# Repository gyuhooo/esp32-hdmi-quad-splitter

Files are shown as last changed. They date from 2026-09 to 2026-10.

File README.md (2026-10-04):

# esp32-hdmi-quad-splitter

Full HD のテスト映像を **1 台のデバイス内で生成し、HDMI 4 本に出力する**装置の設計。

> リポジトリ名は初期案(ESP32 + 分配器)に由来します。現在の方針は **FPGA によるテストパターン発生器**です。
> mp4 の再生は行わず、カラーバー・フレームカウンタ・タイムコードをロジックで生成して 4 本を独立したタイミングで出します。

## 現在の方針: FPGA 4 出力テストパターン発生器

| 項目 | 内容 |
|---|---|
| FPGA | Xilinx Artix-7 XC7A35T 以上(無償 Vivado、MMCM ×4 で 6 種のピクセルクロックを 1 ppm 以内で生成) |
| HDMI 送信 | ADI ADV7513 ×4(24bit RGB パラレル入力 → HDMI 1.4、1080p60 対応、資料公開) |
| 出力 | 1080p / 720p / 480p × 29.97p / 59.94p / 30p / 60p を出力ごとに独立して設定 |
| 画面 | 75% カラーバー、動くボックス(コマ落ち検出)、グレースケール、外枠、ラベル、6 桁フレームカウンタ、タイムコード |
| 状態 | HDL 一式と iverilog シミュレーション済み。キャリア基板は回路図・6 層レイアウト(115 × 38 mm)・ガーバーまで生成済み(DRC 未接続 0 / クリアランス違反 0)。実機は未評価 |

```
100 MHz --> [Artix-7: MMCM x4 -> timing -> pattern] --24bit RGB--> [ADV7513] --> HDMI OUT1
                                   |                              [ADV7513] --> HDMI OUT2
                                   |                              [ADV7513] --> HDMI OUT3
                                   +---------- I2C 初期化 ------->[ADV7513] --> HDMI OUT4
```

シミュレーション結果(1080p 59.94 / 480p 59.94):

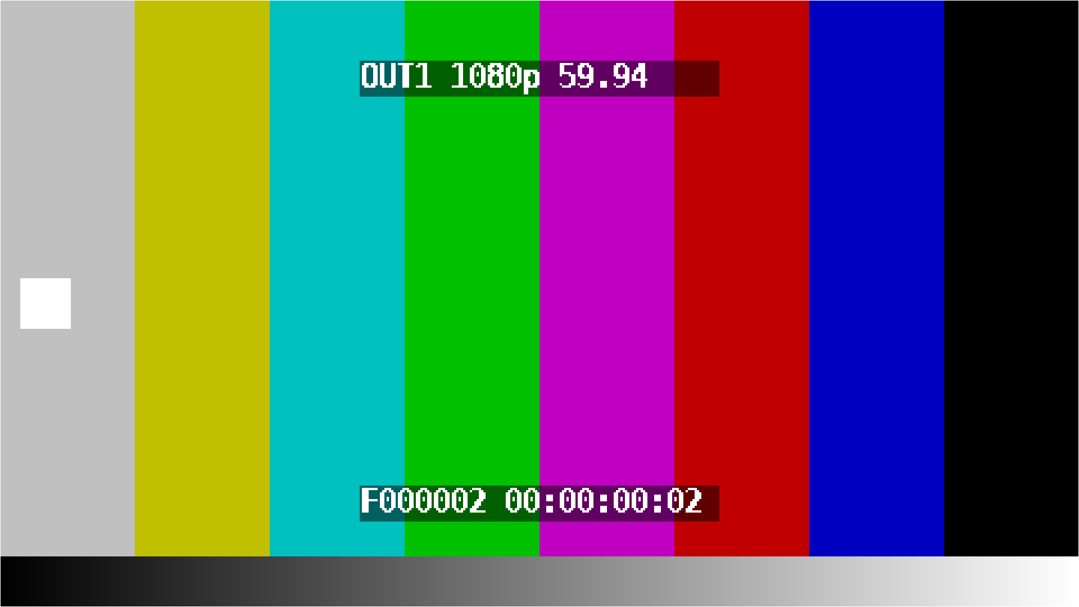
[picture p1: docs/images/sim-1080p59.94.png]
1080p


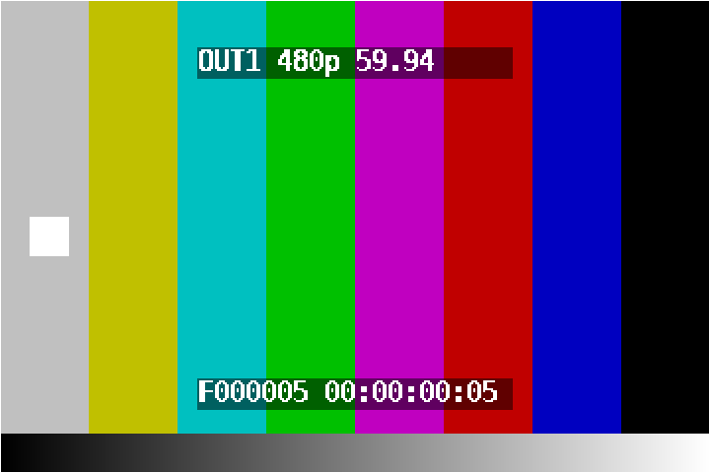
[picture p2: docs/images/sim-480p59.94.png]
480p


詳細は [docs/fpga-pattern-generator.md](docs/fpga-pattern-generator.md)。

### 試す

```
cd sim && make MODE=1 FRAME=2     # iverilog で 1080p59.94 の 1 フレームを frame.ppm に保存
```

### 回路図(hardware/)

FPGA ボードに載せるキャリア基板(ADV7513 ×4、TPD12S016 ×4、HDMI ×4、USB-C 5 V 入力、3.3 V バック、1.8 V LDO ×4)。
[hardware/README.md](hardware/README.md) に構成・検証状況・発注前チェックリストがある。

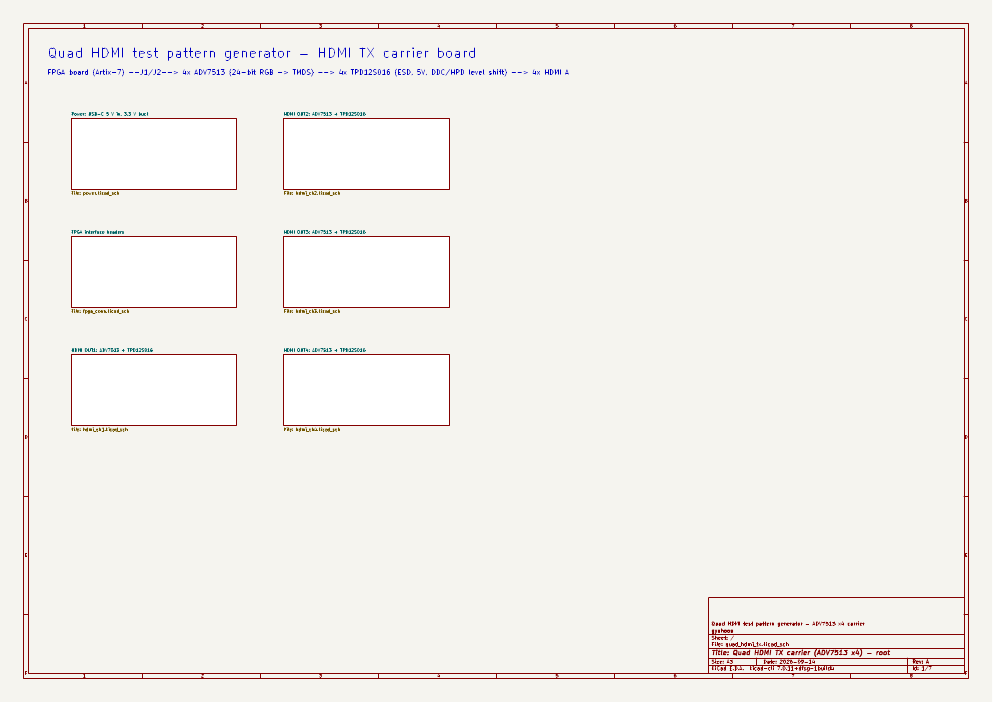
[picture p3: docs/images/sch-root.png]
root


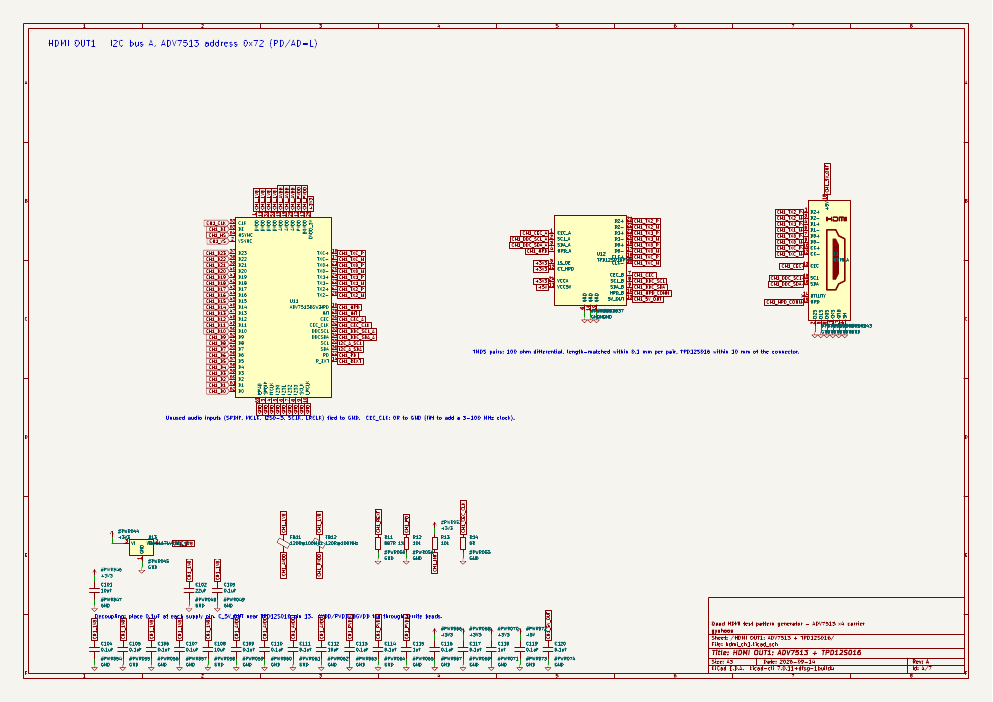
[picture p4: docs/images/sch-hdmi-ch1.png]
ch1


基板の簡易 3D モデル(`hardware/quad_hdmi_tx/3d/`、three.js ビューア付き):

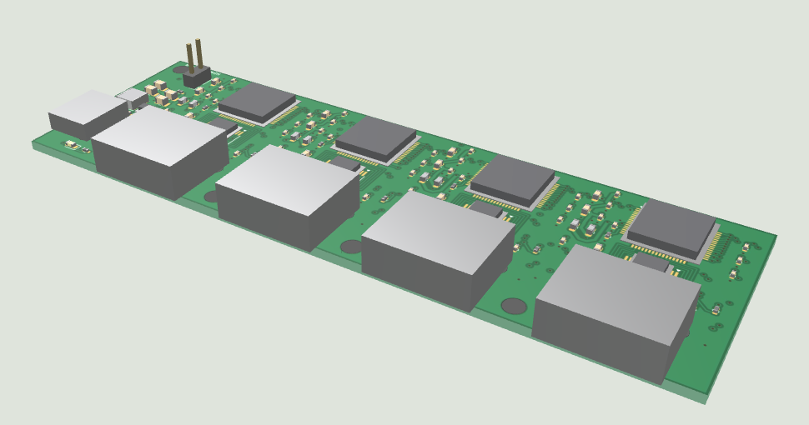
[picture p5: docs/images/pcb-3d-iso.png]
3d


基板レイアウト(6 層、115 × 38 mm、表面):

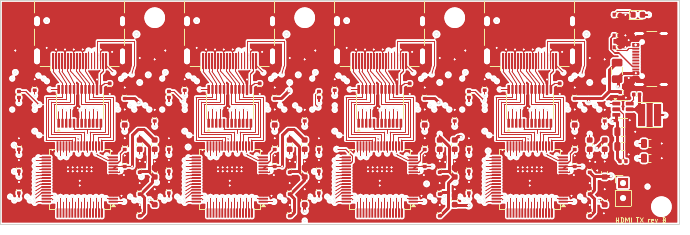
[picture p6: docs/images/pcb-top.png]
pcb


### ディレクトリ

| パス | 内容 |
|---|---|
| hardware/ | KiCad 7 回路図プロジェクト、BOM、ピン割り当て表、生成スクリプト |
| hdl/ | Verilog ソース(タイミング、パターン、文字重畳、MMCM、ADV7513 初期化、トップ) |
| sim/ | iverilog テストベンチと Makefile |
| constraints/ | Vivado 制約ファイルの例 |
| tools/make-font.py | フォント ROM 生成 |
| docs/ | 設計文書 |

## 検討経緯

| 案 | 判定 | 理由 |
|---|---|---|
| ESP32 + LT86104SX 分配器 | 不採用 | ESP32 は映像を生成できない。分配器は同一映像しか出せない |
| RK3588 で mp4 を再生し 4 CRTC へ | 代替案 | 自己完結するが、Linux と SoM が要り、出力ごとの独立タイミングは難しい。[docs/self-contained.md](docs/self-contained.md) |
| Ambarella A7 | 不採用 | HDMI 1 本、SDK は NDA |
| **FPGA パターン発生器** | **採用** | テストパターンで十分。出力ごとに独立したクロックを持て、BOM が小さい |

---

## 初期案(参考): ESP32 + LT86104SX 分配器

以下は「外部 HDMI ソース + 分配器を ESP32 で制御する」初期案の記録です。同一映像の 4 分配だけが目的ならこの構成でも成立します。

### 結論: 実現可能(ただし ESP32 は「制御担当」)

| 役割 | 担当 | 備考 |
|---|---|---|
| Full HD 映像の生成 | PC(ffmpeg) | [docs/video-source.md](docs/video-source.md) |
| Full HD 映像の再生(HDMI ソース) | **Raspberry Pi 4/5 など**(mpv) | ESP32 単体では不可 |
| 1→4 分配、HDCP リピータ、EDID 処理 | LT86104SX | 1080p60 まで、3.4 Gbps/ch |
| IC の初期化・EDID 管理・入力監視・出力 ON/OFF | ESP32(I2C マスタ) | Wi-Fi 経由でリモート制御も可 |

- LT86104SX は入力 HDMI 信号をそのまま 4 系統へ複製する IC で、映像の生成や解像度変換は行いません。
- ESP32(無印 / S3 / C3)には TMDS 出力が無く、1080p60(約 4.5 Gbps)の映像を生成する帯域も持たないため、**映像ソースにはなれません**。
- したがって「ESP32 + LT86104SX」で成立するのは **`HDMI ソース → LT86104SX → HDMI×4` を ESP32 が I2C で制御する構成** です。同じ映像を 4 台のモニタに出す用途なら、これで十分です。

### 4 本が「別々の映像」である必要がある場合

スプリッタでは実現できません。RK3588(4 画面同時出力)や 4 出力 GPU(ASUS GT710-4H など)を使ってください。

### ESP32-P4 を映像ソースにできるか

ESP32-P4 は MIPI-DSI(2 レーン)と H.264 デコーダを持つため、`ESP32-P4 → LT9611 / LT8912B (DSI→HDMI) → LT86104SX` で **1080p30 程度のテストパターン/静止画** を出すことは原理的に可能です。ただし 1080p60(RGB888 で約 3.56 Gbps)は DSI 帯域を超えるため、59.94p / 60p のテストは不可です。本リポジトリでは扱いません。

### ブロック図

```
[PC: ffmpeg で生成] --master.mp4--> [Raspberry Pi: mpv でループ再生]
                                              | HDMI 1080p
                                        [LT86104SX] --HDMI--> OUT1
                                           |   |------HDMI--> OUT2
                                           |   |------HDMI--> OUT3
                                           |   '------HDMI--> OUT4
                                           | I2C (SDA/SCL), RESET, INT
                                        [ESP32] <--Wi-Fi--> OBS-RemoteControl 等
```

### 最小構成の BOM

### 映像ソース

| 部品 | 数 | 備考 |
|---|---|---|
| Raspberry Pi 4(2 GB 以上)または Pi 5 | 1 | mpv でループ再生 |
| microSD 16 GB 以上 | 1 | Raspberry Pi OS Lite 64bit |
| micro HDMI → HDMI ケーブル | 1 | LT86104SX 入力へ |
| 5V 3A(Pi4)/ 5V 5A(Pi5)電源 | 1 | |
| 生成用 PC(ffmpeg) | 1 | 手元の PC で可 |

### スプリッタ + 制御

| 部品 | 数 | 備考 |
|---|---|---|
| LT86104SX(LQFP-128) | 1 | Lontium。データシート/レジスタ仕様は代理店経由(NDA)で入手 |
| ESP32 モジュール(ESP32-WROOM-32 / S3) | 1 | I2C マスタ、Wi-Fi |
| HDMI レセプタクル | 5 | 入力 1、出力 4 |
| 3.3V / コア用レギュレータ | 各 1 | 電圧は LT86104SX データシートで要確認 |
| ESD 保護ダイオード(TMDS 用) | 5 セット | 入出力各ポート |
| 水晶(周波数はデータシートで要確認) | 1 | |
| I2C プルアップ 4.7 kΩ | 2 | |
| 5V → HDMI +5V(各出力) | 4 | 出力側ホットプラグ用に 5V を給電 |

完成品の 1×4 スプリッタ基板(LT86104 搭載)を購入し、基板上の I2C を ESP32 に引き出す方法が最も安価で確実です。

### 使い方(映像の生成と再生)

```
# PC で生成 (ffmpeg 必須)
tools/generate-test-video.sh out/test-video 3

# Raspberry Pi に master.mp4 をコピーしてループ再生 (mpv 必須)
tools/play-loop.sh master.mp4
# セグメントごとに HDMI 出力モードを切替してテストする場合
tools/play-loop.sh --native segments
```

### 詳細

- [docs/self-contained.md](docs/self-contained.md): **現在の方針**。デバイス内で生成して 4 本出す構成
- [docs/video-source.md](docs/video-source.md): 映像の生成と再生機に必要なもの(初期案)
- [docs/feasibility.md](docs/feasibility.md): 可否判断の根拠、帯域計算
- [docs/hardware.md](docs/hardware.md): 配線、電源、注意点
- [docs/i2c-control.md](docs/i2c-control.md): ESP32 からの制御シーケンス
- [tools/](tools/): テスト映像の生成・再生スクリプト
- [firmware/](firmware/): ESP-IDF 用 I2C 制御の雛形

### 関連

- [OBS-RemoteControl](https://github.com/gyuhooo/OBS-RemoteControl)(テスト映像スクリプトの元)
- [LT86104SXE Product Brief (Lontium)](https://www.lontiumsemi.com/UploadFiles/2021-03/LT86104SXE_brief_R1.pdf)

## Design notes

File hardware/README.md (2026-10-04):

# Quad HDMI TX キャリア基板 (ADV7513 ×4)

FPGA ボードから 24bit RGB ×4 を受け、HDMI 4 本を出す基板の KiCad 7 プロジェクト。
`gen/gen_schematic.py` が回路図・BOM・ピン割り当て表を生成し、`kicad-cli` でネットリストと PDF を書き出している。

| ファイル | 内容 |
|---|---|
| quad_hdmi_tx/quad_hdmi_tx.kicad_pro / *.kicad_sch | KiCad 7 プロジェクト(ルート + 電源 + FPGA コネクタ + HDMI OUT1〜4) |
| quad_hdmi_tx/quad_hdmi_tx.pdf | 回路図 PDF(7 ページ) |
| quad_hdmi_tx/netlist.net | kicad-cli で書き出したネットリスト |
| quad_hdmi_tx/bom.csv, bom_grouped.csv | 部品表(リファレンス別 / 集計、MPN 付き) |
| quad_hdmi_tx/fpga_header_pinmap.csv | J7/J8 のピン → 信号名。FPGA ピン列を埋めて `gen/gen_xdc.py` で XDC を生成 |
| quad_hdmi_tx/quad_hdmi_tx.kicad_pcb | 基板レイアウト rev B(6 層、115 × 38 mm の細長い基板)。`gen/gen_pcb.py` が配置・プレーン・事前配線を生成し、FreeRouting で自動配線 |
| quad_hdmi_tx/drc.rpt | DRC レポート(pcbnew API) |
| quad_hdmi_tx/fab/ | ガーバー、ドリル、CPL(部品座標)、各層の PDF(`gen/export_fab.sh`) |
| quad_hdmi_tx/3d/ | STEP(基板のみ)、簡易 3D モデル(OBJ + テクスチャ)、three.js ビューア(`gen/gen_3d.py`、`gen/make_3d_textures.py`) |
| gen/ | 生成スクリプト、ネットリスト検査、配線パイプライン |

## 回路構成

```
USB-C 5V ─ F1(PTC 2A) ─ +5V ─ U5 AP63203 (3.3V 2A buck) ─ +3V3 ─┬─ U13 TLV1117LV18 ─ CH1_1V8 ─ U11 ADV7513 ─ U12 TPD12S016 ─ J1 HDMI
                                                               ├─ U23 ...                          CH2 (I2C bus A, addr 0x7A)
                                                               ├─ U33 ...                          CH3 (I2C bus B, addr 0x72)
                                                               └─ U43 ...                          CH4 (I2C bus B, addr 0x7A)
J7 / J8 (2×40 SMD、裏面): 各チャネル 20 ピンずつ。J7 = D13-23 + D1/D2/D4/D5/D10、J8 = D0/D3/D6-9/D11/D12, CLK, DE/HS/VS, HPD, INT (+ I2C_A/I2C_B, FPGA_5V)
```

### チャネル(×4)

| 要素 | 内容 | 根拠 |
|---|---|---|
| ADV7513BSWZ (LQFP-64 EP) | 24bit RGB 4:4:4 入力 ID 0、セパレートシンク。TMDS 出力 | データシート Rev.B Table 3 のピン配置 |
| R_EXT 887 Ω 1% | TMDS 基準電流 | データシート Table 3 |
| PD/AD 10 kΩ | GND → I2C 0x72(7bit 0x39)、+3V3 → 0x7A(0x3D)。同一バス 2 台をこれで分ける | |
| INT 10 kΩ プルアップ | ヘッダへ | |
| CEC_CLK 0 Ω→GND | CEC 未使用。使う場合は 0 Ω を外して 3〜100 MHz を入れる | Table 3 |
| 未使用オーディオ入力 | SPDIF, MCLK, I2S0-3, SCLK, LRCLK を GND | |
| 電源 | DVDD ×4 / AVDD ×3 / PVDD / BGVDD = 1.8 V、DVDD_3V = 3.3 V。1.8 V はチャネルごとの LDO。AVDD と PVDD/BGVDD はフェライトビーズ経由 | 1.8 V 系は最大 256 mW/個 |
| TPD12S016PWR (TSSOP-24) | TMDS 8 本の ESD、DDC/CEC のレベルシフト(A 側 3.3 V、B 側 5 V プルアップ内蔵)、HPD、5V_OUT(55 mA リミット) | データシート SLLSE96F |
| LS_OE / CT_HPD | +3V3 固定(常時有効) | |
| HDMI A(Molex 208658-1001) | シールド、GND、SH は GND。UTILITY(14) は未接続 | |

### 電源

- USB-C(GCT USB4105-GF-A、USB2.0 16P)、CC1/CC2 に 5.1 kΩ(5 V 3 A シンク宣言)。代替 5 V 入力 J6。
- F1: PTC 2 A。+5V と VBUS に PWR_FLAG。
- U5 AP63203WU(3.3 V 固定、2 A): CIN 10 µF ×2、CBST 0.1 µF、L 4.7 µH(NR4018T4R7M)、COUT 22 µF ×2、EN は 100 kΩ で VIN へ。
- 消費見積: 1.8 V 系 4 × 142 mA ≈ 0.57 A(LDO 損失 ≈ 0.85 W、SOT-223 ×4 に分散)、3.3 V 系合計 ≈ 0.7 A、5 V 入力 ≈ 0.8 A(HDMI 5V_OUT 4 × 55 mA 含む)。
- JP1(ソルダージャンパ)を閉じると J8 の 39-40 ピン(FPGA_5V)から FPGA ボードへ 5 V を供給できる。FPGA ボードが自前電源のときは開けたままにする。

### FPGA コネクタ J7 / J8

- 2×40 ピン 2.54 mm の SMD ヘッダ 2 本を **裏面** に長辺と平行に置く(Samtec TSM-140-01-L-DV 相当)。リボンケーブル(IDC)で FPGA ボードへ。
- ヘッダの列 k(ピン 2k-1 / 2k)は OUT ⌈k/10⌉ の ADV7513 の真下にある。各チャネルは J7 で 20 ピン(ADV 左辺の D13-23 と下辺の D1/D2/D4/D5/D10、GND ×4)、J8 で 20 ピン(ADV 下辺の D0/D3/D6-9/D11、CLK, DE/HS と D12、VS, HPD, INT、GND ×4、OUT1/OUT3 は I2C、OUT2 は FPGA_5V ×2)。
  データ線の並びは配線経路(内層の通路の順序)で決めたもので、ビット順ではない。FPGA 側のピン割り当ては `fpga_header_pinmap.csv` を参照。
- GND は ADV / TPD の真下の列(J7 列 4-7 下段、J8 列 4-7 上段)に置いている(表面がふさがっていて信号のビアが打てない位置)。リボンケーブル上では 4〜9 本おき。ケーブルは 15 cm 以下を推奨(148.5 MHz SDR)。
- 3.3 V LVCMOS。FPGA ボードの該当バンクは VCCO = 3.3 V であること。
- スタック高さは 30 mm 以下を推奨(148.5 MHz SDR)。FPGA 側で 22〜33 Ω の直列終端を入れられるとなお良い。
- 使用する FPGA ボードのヘッダ ⇔ FPGA ピン対応を `fpga_header_pinmap.csv` の FPGA_pin 列に記入し、`python3 gen/gen_xdc.py quad_hdmi_tx/fpga_header_pinmap.csv > constraints/board.xdc` で XDC を作る。

## 検証状況

| 項目 | 状態 |
|---|---|
| ADV7513 の全 65 ピン、TPD12S016 の全 24 ピンがデータシートどおりに割り当てられている | 済(スクリプトで番号を生成、検査で全ピンの接続を確認) |
| kicad-cli によるネットリスト書き出し | 済(147 部品、233 ネット) |
| ネット検査: データ線 2 ピン、TMDS 3 ピン、HPD/INT 3 ピン、I2C 4 ピン、GND/+3V3 に信号ピンが混ざっていない | 済(`gen/check_netlist.py`) |
| 基板レイアウト(配置・配線) | 済(rev B: 6 層 115 × 38 mm、配線 2010 本、ビア 634 個。HDMI・USB-C コネクタは基板端に合わせ済み) |
| DRC(pcbnew API、KiCad 7 の既定ルール + 本基板のルール) | 未接続 0、クリアランス / 穴 / 外形 / コートヤード違反 0(残りは `lib_footprint_issues` 147 件 = 生成したフットプリントがライブラリと一致しないという情報のみ) |
| TMDS 8 本 × 4 ch | ビアなし、ペア内長差 0.47 mm 以下(スクリプトで固定配線) |
| ガーバー / ドリル / CPL 出力 | 済(`quad_hdmi_tx/fab/`) |
| KiCad GUI での ERC / DRC 再確認 | **未**(GUI で開いて再実行を推奨) |
| 実機評価 | **未** |

### レイアウトの結果

| 層 | 画像 |
|---|---|
| 表面 (F.Cu) | top |
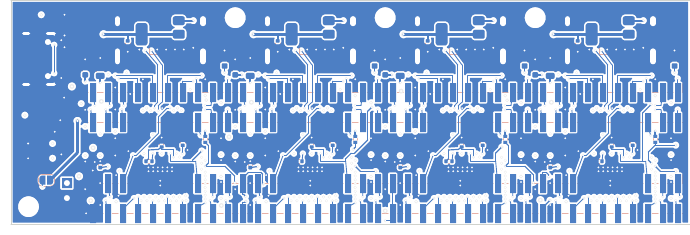
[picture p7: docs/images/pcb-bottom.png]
bottom
| 裏面 (B.Cu、ミラー表示) |  |
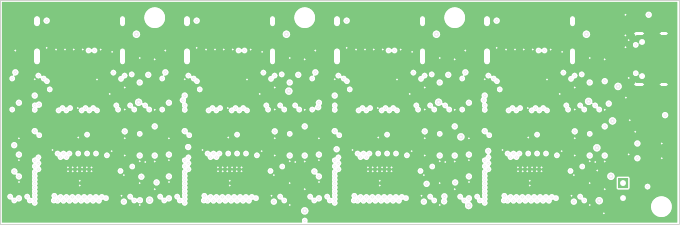
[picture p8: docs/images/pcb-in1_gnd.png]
gnd
| 内層 1 (GND) |  |
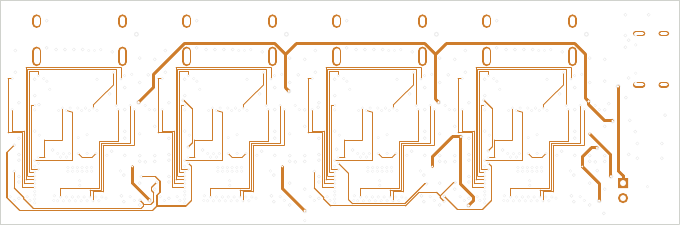
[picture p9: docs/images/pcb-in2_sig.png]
sig1
| 内層 2 (SIG1) |  |
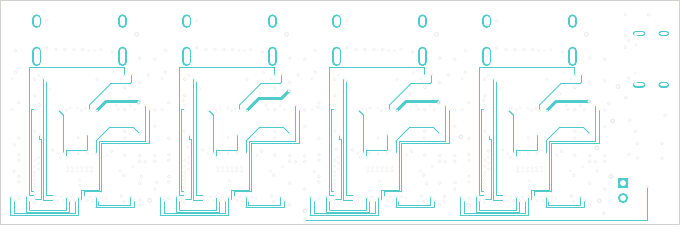
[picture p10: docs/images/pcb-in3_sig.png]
sig2
| 内層 3 (SIG2) |  |
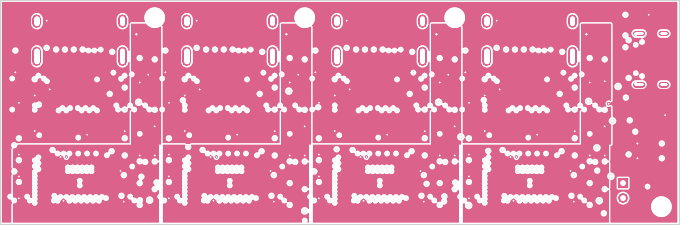
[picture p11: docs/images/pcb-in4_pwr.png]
pwr
| 内層 4 (+3V3 / CHn_1V8) |  |

TMDS の事前配線(OUT1 周辺、配線前の状態):

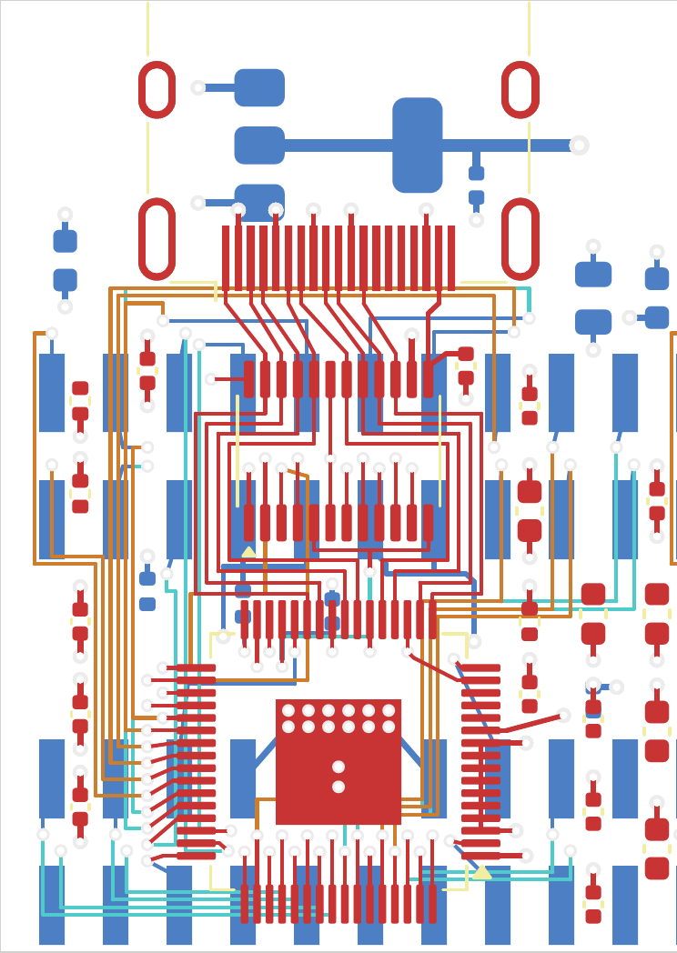
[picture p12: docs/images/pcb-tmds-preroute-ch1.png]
tmds


自動配線(FreeRouting 1.9)後の主なネット長:

```
RGB バス / 同期 (112 本): 最長 51.3 mm (D16、ヘッダ上の横レーン経由)、平均 21.4 mm、最短 4.2 mm。すべて gen_pcb.py の固定配線 (ビア 1〜2 個)
I2C_A_SCL 70 mm (OUT1/OUT2 の ADV とプルアップ、J8 経由)、I2C_B_SCL 56 mm
HPD 20 mm、INT 25 mm、DDC_SCL / CEC 15 mm (TPD -> HDMI)、FPGA_5V 72 mm (J8 ピン 39/40 -> JP1)
+5V 197 mm (ビア 9)、+3V3 132 mm (ビア 41、内層 4 のプレーンが主)、GND 326 mm (ビア 203、内層 1 のプレーンが主)
TMDS: ペア内長差 0.05〜0.47 mm、ビアなし
```

### 3D モデル

3d

| 表 | 裏 |
|---|---|
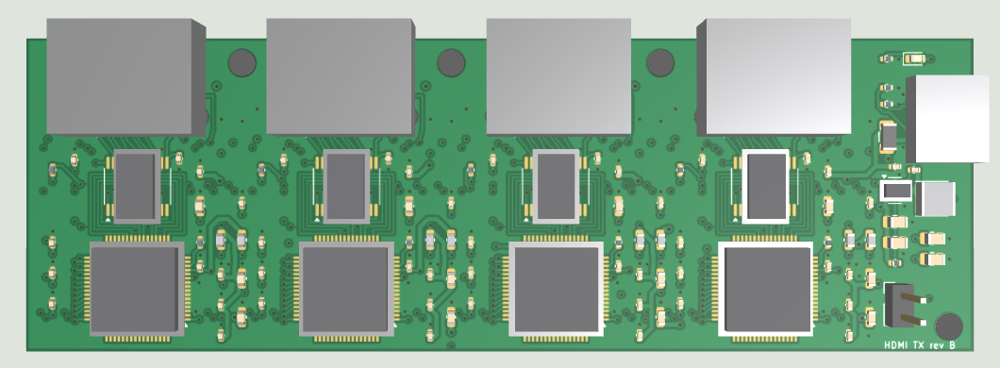
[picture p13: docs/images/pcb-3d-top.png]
3d top
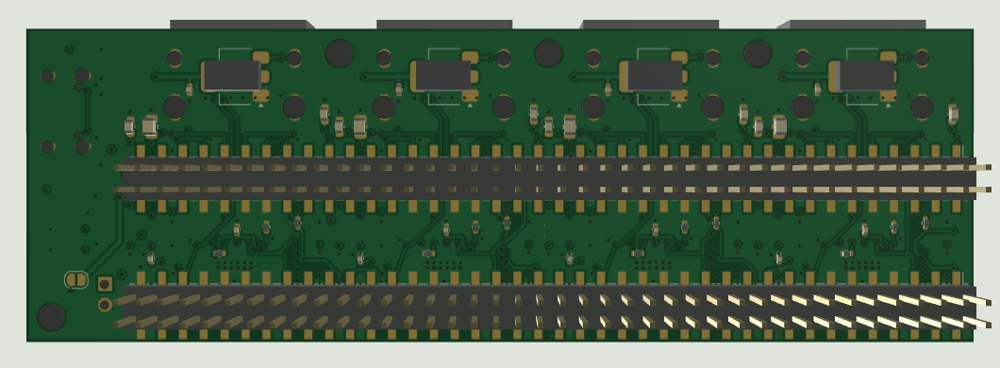
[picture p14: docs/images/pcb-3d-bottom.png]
3d bottom
|  |  |

`quad_hdmi_tx/3d/` に 3 種類ある(`gen/gen_3d.py` と `gen/make_3d_textures.py` で生成):

| ファイル | 内容 |
|---|---|
| `quad_hdmi_tx.step` | kicad-cli の STEP 出力。この環境には KiCad の 3D モデルライブラリが無いため **基板のみ**(部品なし)。筐体設計の基準に使える |
| `quad_hdmi_tx_simplified.obj` / `.mtl` / `tex_top.png` / `tex_bot.png` | 簡易モデル(Wavefront OBJ、mm、Y 上)。基板は表裏にレジスト・金パッド・シルクのテクスチャ、部品はパッケージ種別の寸法表による直方体(IC・受動部品・コネクタ・ヘッダのピン) |
| `viewer.html` | 上の簡易モデルを three.js で回転表示する 1 ファイルのビューア(ブラウザで開く) |

部品の外形は寸法表の近似なので、正確な 3D モデルが要るときは KiCad の 3D ライブラリを入れて `kicad-cli pcb export step` を再実行する。

## 発注前チェックリスト

1. **ADV7513 の推奨回路**: ハードウェアユーザーガイド(ADI)で、PVDD/BGVDD のフィルタ構成と HPD/DDC の扱いが本回路(フェライトビーズ + 0.1 µF、TPD12S016 経由)と矛盾しないか確認する。
2. **フットプリント**: ADV7513 の露出パッドは 5.3 mm 角。`LQFP-64-1EP_10x10mm_P0.5mm_EP5x5mm` を使い、EP のサーマルビア(0.5/0.3 mm ×14)は裏面ヘッダのパッドを避けて `gen_pcb.py` が打っている。
3. **HDMI コネクタ**: Molex 208658-1001 の KiCad 標準フットプリント。別品番なら 1〜19 + シェルの配列を照合する。
4. **USB-C**: GCT USB4105-GF-A の標準フットプリント。NPTH と自身のパッドの間隔が 0.194 mm なので、穴クリアランスの規則を 0.18 mm にしている。
5. **LDO**: TLV1117LV18DCYR(セラミック出力対応、1 A)。AMS1117-1.8 はピン互換だがタンタル出力推奨。
6. **I2C アドレス**: 同一バスに 2 台(0x72 と 0x7A)。HDL の `top.v` はバス 0 = OUT1/OUT2、バス 1 = OUT3/OUT4 でこの割り当てを前提にしている。
7. **KiCad GUI で ERC と DRC を再実行する**: 本リポジトリの検査は pcbnew API のレポート。DRC の残り 143 件は「フットプリントがライブラリと一致しない」情報(ライブラリ名なしで読み込んだため)で、製造には影響しない。
8. **インピーダンス**: TMDS は 0.15 mm 幅 / 0.15 mm 間隔で固定配線している。製造業者の 6 層スタックアップ(例: JLC06161H-3313、F.Cu〜In1 が 0.1 mm 程度)の計算値に合わせて幅・間隔を調整し、必要なら `gen/gen_pcb.py` のネットクラスと事前配線幅を変えて再生成する。
9. **自動配線部の目視確認**: RGB バス(148.5 MHz)30 本は `gen_pcb.py` の固定配線(内層 SIG1/SIG2、各線 40 mm 以下)。電源・I2C・CEC・HPD 系は FreeRouting の結果なので、ADV 右辺付近の AVDD/PVDD と I2C の引き回しをレビューし、必要なら手で整える。
10. **シルク**: 参照記号は F.Fab に置いている(シルクには出ない)。実装は `fab/cpl.csv` の座標で行う。
11. **コネクタの基板端合わせ**: HDMI(Molex 208658)と USB-C(GCT USB4105)のフットプリントには "PCB Edge" の基準線がある。
    生成スクリプトはこの線が基板外形(HDMI: y=0、USB-C: x=115)に一致するよう配置している(HDMI は本体が 1.5 mm、USB-C は 0.5 mm 外形からはみ出す)。
    ケースに入れる場合はこのはみ出し量を前提に開口を設計する。
12. **裏面のヘッダと IDC ソケット**: J7/J8 の中心間隔は 15.4 mm、J8 は下辺から 4.4 mm。IDC ソケット(幅 8.9 mm)は J8 側が基板端とほぼ面一になる。基板の下に高さ 10 mm 以上の空間が必要。
13. **両面実装**: LDO ×4、そのコンデンサ、ヘッダ 2 本、JP1 が裏面。実装業者には両面(F+B)の CPL を渡す。裏面の SMD ヘッダはリフロー可能品(TSM-140-01-L-DV 等)を選ぶ。
14. **取付穴**: M3 ×4(HDMI の間に 3 個、右下に 1 個)。HDMI の間の穴はプラグのオーバーモールド(幅 ~21 mm)と干渉しない位置だが、ナットは基板の裏側に置くこと。

## 基板レイアウト

### 配置(rev B: 115 × 38 mm、縦横比 0.33)

```
 y=0  ┌───────────────────────────────────────────────────────────────────────┐
      │ [J1 HDMI] H1 [J2 HDMI]  H2 [J3 HDMI]  H4 [J4 HDMI]   R5 R6 F1  [J5]   │  上辺: HDMI ×4 (25.4 mm ピッチ、開口部は上)。裏面の真裏に LDO
      │  U12 TPD     U22 TPD       U32 TPD       U42 TPD      C54     USB-C   │  TPD12S016 (rot 90)。両脇に +3V3 / 5V 系のコンデンサ
      │  U11 ADV     U21 ADV       U31 ADV       U41 ADV      U5  C51  L1     │  ADV7513 (rot 180)。左右の列に 1V8 / AVDD / PVDD 系
      │                                                      C52 C53  C55 C56 │  電源部 (右端)
 y=38 └───────────────────────────────────────────────────────────────────────┘
        x=0                              裏面: J7 (y=18.2) と J8 (y=33.6) が x=1.6..101.6 に横たわる        x=115

 裏面 (透視): [LDO U13][LDO U23][LDO U33][LDO U43] ← HDMI のシェルタブの穴の間
             ═══════════ J7 2×40 (列 1-10 = OUT1, 11-20 = OUT2, 21-30 = OUT3, 31-40 = OUT4) ═══════════
             ═══════════ J8 2×40 (同じ列割り) ═══════════════════════════════════════════════════  JP1
```

- HDMI 4 個の横幅(4 × 25.4 mm)に電源部を足した 115 mm を横幅とし、縦幅は 38 mm(横の 1/3 以下)。
- 各チャネルは幅 25.4 mm = ヘッダ 10 列。ヘッダの列は ADV の真下なので、RGB バスの配線は 1 本あたり 15 mm 以下。
- TMDS の並び順が ADV7513(rot 180)→ TPD12S016(rot 90)→ HDMI(rot 90)で **交差なし**に揃うよう向きを決めている
  (ADV 上辺: TX2+ TX2- TX1+ TX1- TX0+ TX0- TXC+ TXC-、TPD 上辺: D2+ D2- D1+ D1- D0+ D0- CLK+ CLK-、コネクタ: 1 3 4 6 7 9 10 12)。
- 裏面ヘッダのパッド(1.0 mm 幅、2.54 mm ピッチ)の隙間は 1.54 mm しかないので、貫通ビアはパッド列の隙間の中心(x = cx ± 2.54 m)か、
  2 列の間 / J7-J8 の間の帯に置く。2 端子部品はすべて縦置きでこの x に載せ、外向きのビアが隙間に来るようにしている。
  TPD の A 側ピンのビア(y = 18.3 / 18.7)は J7 の 2 列の隙間(y 17.25〜19.15)に、ADV 上辺の囲われたピンのビア(y = 26.0 / 26.6)は J7-J8 の間の帯に入る。
- ADV のデータピンはルータ任せでは半分が配線できない(裏面ヘッダのパッドが B.Cu を塞ぐ)ので、`gen_pcb.py` が 30 本の RGB/同期/制御線をすべて事前配線する(残りの電源・I2C・CEC などが FreeRouting):
  - 下辺 16 ピンのエスケープビアは本体下(EP とパッド内端の間 = J8 の 2 列の隙間に当たる y)に 2 段。真下の J8 下段 4 本(D11/D8/D3/HS)は裏面で直落とし、
    D6/D7/CLK/D9 と DE/D0 は SIG2 の横レーン(y = 34.8〜36.5)で J8 列 1-2 / 列 9 の隙間ビアへ、D1/D2/D4/D5/D10 は ADV 右脇の通路(x = cx+3.35/3.65/3.95)を上って J7 列 8-10 へ。
  - 左辺 16 ピンは左へ(上 5 本は x=cx-7.0/-7.62 に交互、中 8 本は隙間の列 x=cx-7.62 に 0.65 ピッチで斜めに、D14/D13 は本体下、D12 は隙間の列の一番下)。
    D16-D23 と DDC は左の内層通路(x = cx-8.19〜-9.69、SIG1/SIG2 各 6 レーン)を上り、J7 列 1-2 の隙間ビア、またはヘッダの上(y = 11.5〜12.1)の横レーン経由で列 5-8 上段へ。
    D13/D14/D15 は ADV 脇の帯(x = cx-6.5〜-5.5)を SIG2 で上って列 3-4 へ。J8 列 4-7 上段(GND)は EP のサーマルビアに裏面で直結。
  - レーンの割り当ては「右の通路ほど低い横レーン」「横レーンから下に曲がる先は左ほど低いレーン」の規則で決め、事前配線どうしが交差しないようにしている。
  - そのほか、ルータが落としやすい DDC_SCL(TPD → HDMI、SIG2 で右上へ抜けて表面でコネクタの上を回る)と FPGA_5V(J8 ピン 39/40 → JP1、SIG2 で基板下端を右へ)も固定配線。
- LDO(SOT-223)は HDMI コネクタの真裏、シェルタブの穴の間。出力は裏面の太い配線で内層 4 の 1V8 の島の「首」へ入る。
- 電源部は右端(USB-C の開口部は右)。

### 層構成(6 層、1.6 mm)

| 層 | 用途 |
|---|---|
| F.Cu | 信号(TMDS 事前配線、短い引き出し)、部品 |
| In1.Cu (GND) | GND プレーン(全面) |
| In2.Cu (SIG1) / In3.Cu (SIG2) | 信号(RGB バス、制御線、+5V) |
| In4.Cu (PWR) | +3V3 プレーン。各 ADV の周囲は CHn_1V8 の島(優先度 1)。島は LDO へ向けて首を伸ばしている |
| B.Cu | FPGA ヘッダ、LDO、信号、配線後に GND ベタ |

4 層では裏面ヘッダのパッド列が B.Cu を塞ぐため、RGB バスの配線が成立しない。6 層にして内層 2 層を信号に使う。

### ルール

| 項目 | 値 |
|---|---|
| クリアランス | 0.15 mm |
| 配線幅 | 0.2 mm(TMDS 0.15、Power 0.5) |
| ビア | 0.6/0.3 mm(TMDS・アクセスビア 0.5/0.3、Power 0.8/0.4) |
| 差動 | 100 Ω 目標、0.15/0.15 mm(**製造業者のインピーダンス計算で要調整**) |

### 生成と配線のパイプライン

```
cd hardware/gen
python3 gen_pcb.py                       # 配置・外形・プレーン・事前配線・ファンアウト -> quad_hdmi_tx.kicad_pcb, drc_pre.rpt
python3 route_pcb.py export              # quad_hdmi_tx.dsn
xvfb-run -a java -jar freerouting-1.9.0.jar -de ../quad_hdmi_tx/quad_hdmi_tx.dsn -do ../quad_hdmi_tx/quad_hdmi_tx.ses -mp 24 -oit 1.0   # 約 10 分
python3 route_pcb.py import              # SES 取り込み、外層 GND ベタ、ゾーン塗り、DRC -> drc.rpt
python3 layout_report.py                 # 配線長、ビア数、TMDS ペア長差、DRC 集計
./export_fab.sh                          # fab/ にガーバー・ドリル・CPL・PDF
python3 render_images.py                 # fab/*.pdf → docs/images/pcb-*.png (Pillow, pdftoppm)
python3 gen_3d.py                        # 3d/board3d.json, 簡易 OBJ/MTL (pcbnew)
python make_3d_textures.py               # 3d/tex_*.png と 3d/viewer.html (Pillow + numpy。先に各層の白黒 PDF→PNG が要る、スクリプト冒頭参照)
```

FreeRouting を使う上での注意(実測で判明したもの):

- 外層のベタを DSN に含めると障害物として扱われ配線できないため、ベタは SES 取り込み後に追加している。
- FreeRouting 2.1 は SMD パッドから内層プレーンへのビアを自分では作らない。`gen_pcb.py` が GND / +3V3 / CHn_1V8 の全 SMD パッドに
  ファンアウトビア(ロック済み)を先に置き、DSN には固定配線として渡している。
- 2.1 はコマンドラインの `-mp` / `-mt` を無視し、設定ファイル(`/tmp/freerouting/freerouting.json` など)の
  `router.max_passes`(既定 9999)と `router.max_threads`(既定 1)を使う。ヘッドレスでは `gui.enabled` を false にする。
- 1.9.0 は `-mp` を受け付けるが GUI 必須(Xvfb で起動できる)。

## レイアウト指針

- TMDS: 100 Ω 差動、ペア内長差 0.1 mm 以内、ペア間はゆるく揃える。ADV7513 → TPD12S016 → コネクタを一直線に、TPD はコネクタから 10 mm 以内。
- RGB バス(148.5 MHz SDR): ヘッダ → ADV7513 を短く、GND プレーンを連続させる。CLK はデータより長めにしない。
- 1.8 V: LDO ごとに ADV7513 の近くに配置。0.1 µF は各電源ピン直近。
- 4 層(信号 / GND / 電源 / 信号)を推奨。2 層でも可能だが TMDS のインピーダンス管理が難しい。
- 発熱: LDO ×4(各 ≈ 0.2 W)と ADV7513 ×4 に銅箔面積を確保する。

## 発注手順(例: JLCPCB)

1. KiCad で `quad_hdmi_tx.kicad_pro` を開き、ERC → 「PCB を更新」でフットプリントを配置、レイアウトする。
2. 基板外形、4 層、1.6 mm、ENIG(0.5 mm ピッチの LQFP と TSSOP に無難)。
3. ガーバー + ドリルを出力、`bom_grouped.csv` と CPL(配置座標)を出して実装を依頼する。MPN は Murata / Yageo / Taiyo Yuden / Diodes / TI / ADI / Molex / GCT の標準品。
4. ADV7513、TPD12S016、AP63203、TLV1117LV は実装業者の在庫にない場合があるので、事前に入手性を確認する。

## 回路図の再生成

```
cd hardware/gen
python3 gen_schematic.py                 # *.kicad_sch, bom.csv, fpga_header_pinmap.csv
cd ../quad_hdmi_tx
kicad-cli sch export netlist --format kicadsexpr -o netlist.net quad_hdmi_tx.kicad_sch
python3 ../gen/check_netlist.py netlist.net
kicad-cli sch export pdf -o quad_hdmi_tx.pdf quad_hdmi_tx.kicad_sch
```

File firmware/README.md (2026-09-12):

# firmware

ESP-IDF(v5.x)向けの雛形。以下を行います。

1. LT86104SX をリセット
2. I2C バスをスキャンしてデバイスを列挙
3. 見つかったアドレスに対して `lt86104_init()` を呼ぶ(初期化テーブルは空。データシート入手後に `lt86104.c` の `INIT_TABLE` を埋める)

```
idf.py set-target esp32
idf.py build flash monitor
```

ピン割り当ては `main/lt86104.h` で変更できます。

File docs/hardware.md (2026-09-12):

# ハードウェア構成

## 接続

| ESP32 ピン(例) | LT86104SX 側 | 備考 |
|---|---|---|
| GPIO21 (SDA) | SDA | 4.7 kΩ プルアップ(3.3V) |
| GPIO22 (SCL) | SCL | 同上。100 kHz から始め、安定したら 400 kHz |
| GPIO4 | RESET_N | 起動時に Low → High |
| GPIO5 | INT | 入力信号変化 / HPD 通知(プルアップ) |
| GND | GND | 共通 |

ピン番号は例です。使用する ESP32 ボードに合わせて変更してください。

## 電源

- LT86104SX はコア用の低電圧と I/O 用 3.3V の複数電源が必要です。正確な電圧・投入順序はデータシートで確認してください。
- 各 HDMI 出力の +5V ピンにはソース側の役割として 5V を供給します(合計 4 系統、各 50 mA 程度)。
- ESP32 の Wi-Fi ピーク電流(約 500 mA)を考慮し、3.3V レギュレータは 1 A 級を推奨します。

## TMDS 配線

- 差動 100 Ω、ペア内長差 ±5 mil 以内、AC 結合なし(HDMI は DC 結合)
- コネクタ直近に ESD 保護素子を配置
- 自作基板で TMDS を引く場合は 4 層以上を推奨。難しければ **市販の LT86104 搭載スプリッタ基板を流用し、I2C だけ引き出す** ことを推奨します。

## 市販基板流用の手順

1. LT86104SX/SXE 搭載の 1×4 スプリッタ(2,000〜4,000 円程度)を入手
2. 基板上の MCU(多くは 8051 系)を取り外す、または I2C バスをアイドルにする
3. SDA/SCL/RESET/GND を ESP32 に接続
4. 基板の 5V 電源を ESP32 と共用

## 注意

- LT86104SX のレジスタマップは公開されていません。Lontium または代理店(L2Tek 等)から NDA でデータシートと初期化シーケンスを入手する必要があります。
- HDCP コンテンツを扱う場合はライセンス上の制約があります。

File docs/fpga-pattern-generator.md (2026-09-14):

# FPGA 4 出力テストパターン発生器

mp4 を再生するのではなく、**FPGA のロジックでテストパターンを生成し、HDMI 4 本を独立したタイミングで出力する**装置。
1 台で完結し、分配器も外部ソースも使わない。

## 出せるもの

- 解像度: 1080p / 720p / 480p
- フレームレート: 29.97p / 59.94p / 30p / 60p(4 出力それぞれに別のモードを設定できる)
- 画面内容: 75% カラーバー、1 フレーム 1 ステップで動く白いボックス(コマ落ち検出用)、
  下部グレースケール、1 ピクセルの白い外枠(オーバースキャン検出用)、
  「OUT1 1080p 59.94」ラベル、6 桁フレームカウンタ、hh:mm:ss:ff タイムコード
- 音声: なし(必要なら ADV7513 の I2S に正弦波を入れる拡張が可能)

シミュレーションで得た 480p フレーム:

```
sim/ で make MODE=9 FRAME=2 -> frame.ppm
```

## 構成

```
                +------------------------- Artix-7 -------------------------+
100 MHz OSC --->| MMCM x4 (各出力の正確なピクセルクロック)                     |
                |  ch0: timing -> counter -> pattern -> 24bit RGB + DE/HS/VS |--> ADV7513 #1 --> HDMI OUT1
                |  ch1:                     "                                |--> ADV7513 #2 --> HDMI OUT2
                |  ch2:                     "                                |--> ADV7513 #3 --> HDMI OUT3
                |  ch3:                     "                                |--> ADV7513 #4 --> HDMI OUT4
                |  I2C master x2 (ADV7513 初期化: 0x39 / 0x3D を 2 バスに振り分け) |
                +------------------------------------------------------------+
```

- 各チャネルは完全に独立したクロック域で動く。OUT1=59.94p、OUT2=60p のような組み合わせも同時に出せる。
- HDMI の TMDS 化は ADV7513(HDMI 1.4 送信 IC、165 MHz まで、公開データシート・Linux ドライバあり)に任せ、
  FPGA は 24bit パラレル RGB を出すだけ。FPGA から直接 TMDS を出す方式は Artix-7 の HR バンクでは
  1080p60(1.485 Gbps)が規格外になるため採らない。

## チップ選定

| 部品 | 選定 | 理由 |
|---|---|---|
| FPGA | Xilinx Artix-7 XC7A35T 以上(FGG484 推奨) | 無償の Vivado で使える、MMCM 5 個以上、I/O が足りる |
| HDMI 送信 | ADI ADV7513 ×4 | 1080p60 対応、データシート公開、Linux に adv7511 ドライバがあり設定値が確認できる |
| 発振器 | 100 MHz ×1 | MMCM で 6 種類のピクセルクロックを誤差 1 ppm 以内で生成 |

### 代替

- HDMI 送信を **ITE IT66121** にすると安価だが、設定手順の公開資料が少ない。
- **Lattice ECP5 + オープンツール(Yosys/nextpnr)** でも可。PLL の分数分周がないので 1/1.001 系の
  クロックは外付け発振器(Si5351 など)が必要。
- 4 出力を 1 つの FPGA に入れず、**1 出力 = 小型 FPGA 1 個**(Artix-7 XC7A15T / Gowin GW1N + ADV7513)を
  4 枚並べる構成も、基板が単純になり最小構成として有効。

## ピン数の見積もり(XC7A35T-FGG484: 250 I/O)

| 信号 | 本数 |
|---|---|
| RGB 24bit ×4 | 96 |
| CLK / DE / HS / VS ×4 | 16 |
| I2C ×2 バス | 4 |
| HPD ×4 | 4 |
| 100 MHz、リセット、LED | 6 |
| 合計 | 約 126 |

I/O が足りない小型パッケージ(FTG256 = 170 I/O)でも収まる。さらに減らしたい場合は ADV7513 の
DDR 入力モード(12bit ×2 エッジ)を使えば RGB は 48 本になる。

## クロック生成

MMCME2_BASE(100 MHz 入力)の設定。`hdl/video_modes.vh` の関数で MODE から自動選択される。

| ピクセルクロック | 用途 | DIVCLK | MULT_F | DIVIDE_F | 誤差 |
|---|---|---|---|---|---|
| 148.5 MHz | 1080p60 | 4 | 37.125 | 6.25 | 0 |
| 148.352 MHz | 1080p59.94 | 7 | 50.625 | 4.875 | 0 |
| 74.25 MHz | 1080p30 / 720p60 / 720p30 | 4 | 37.125 | 12.5 | 0 |
| 74.176 MHz | 1080p29.97 / 720p59.94 / 720p29.97 | 6 | 50.625 | 11.375 | 0 |
| 27.027 MHz | 480p60 | 1 | 6.25 | 23.125 | +1 ppm |
| 27.0 MHz | 480p59.94 | 1 | 6.75 | 25.0 | 0 |

## モード一覧

| MODE | 解像度 | fps | H total × V total | 備考 |
|---|---|---|---|---|
| 0 / 1 | 1080p | 60 / 59.94 | 2200 × 1125 | CEA-861 VIC 16 |
| 2 / 3 | 1080p | 30 / 29.97 | 2200 × 1125 | VIC 34 |
| 4 / 5 | 720p | 60 / 59.94 | 1650 × 750 | VIC 4 |
| 6 / 7 | 720p | 30 / 29.97 | 3300 × 750 | VIC 62 |
| 8 / 9 | 480p | 60 / 59.94 | 858 × 525 | VIC 2/3、負極性シンク |
| 10 / 11 | 480p | 30 / 29.97 | 1716 × 525 | **規格外**。受け付けないモニタがある |

各出力のモードは `hdl/top.v` の `MODE0..MODE3` パラメータで指定する(ビルド時固定)。

### 実行時にモードを切り替えたい場合

ピクセルクロックを変える必要があるため、次のいずれかが要る。v1 では対象外。

1. MMCM の DRP(動的再構成)で分周比を書き換える
2. 外付けクロックジェネレータ(Si5351A、I2C、分数 PLL)から 4 本のピクセルクロックを供給し、
   FPGA から I2C で周波数を書き換える。タイミングパラメータはレジスタ化して UART/DIP から選ぶ

## ADV7513 の接続

| ADV7513 ピン | 接続先 | 備考 |
|---|---|---|
| D[23:0] | hdmi_d[23:0](R=D[23:16], G=D[15:8], B=D[7:0]) | 入力 ID 0(24bit RGB 4:4:4) |
| CLK | hdmi_clk | ピクセルクロック。ODDR で出すのが望ましい |
| DE / HSYNC / VSYNC | hdmi_de / hdmi_hs / hdmi_vs | セパレートシンク |
| SCL / SDA | i2c_scl / i2c_sda | 4.7 kΩ プルアップ。1 バスに 2 台(PD/AD ピンで 0x39 と 0x3D) |
| PD/AD | GND または 3.3V | I2C アドレス選択 |
| HPD(出力) | hdmi_hpd | 未使用なら FPGA 側で 1 に固定 |
| TMDS 出力 | HDMI コネクタ | 100 Ω 差動、ESD 保護 |
| 電源 | 1.8V(コア/PLL/TMDS)、3.3V(I/O) | データシートの推奨回路に従う |

初期化レジスタは `hdl/adv7513_init.v` のテーブルにある(ADI Programming Guide の
クイックスタート値)。HPD を強制 High(0xD6=0xC0)にしているので、モニタ未接続でも出力を続ける。

## ファイル

| パス | 内容 |
|---|---|
| hdl/video_modes.vh | MODE → タイミング / MMCM 設定 / ラベルの変換関数 |
| hdl/video_timing.v | H/V カウンタ、DE/HS/VS 生成 |
| hdl/frame_counter.v | 6 桁 BCD フレームカウンタとタイムコード |
| hdl/text_overlay.v | 8x16 フォントによる文字重畳(2^n 倍拡大) |
| hdl/pattern_gen.v | カラーバー、動くボックス、グラデーション、文字合成 |
| hdl/mmcm_pixclk.v | MMCME2_BASE ラッパ(SIM 時はバイパス) |
| hdl/hdmi_channel.v | 1 出力分の結線 |
| hdl/adv7513_init.v, hdl/i2c_master.v | ADV7513 の I2C 初期化 |
| hdl/top.v | 4 出力トップ |
| hdl/font8x16.mem | フォント ROM(tools/make-font.py で生成) |
| sim/ | iverilog テストベンチ。1 フレームを PPM に保存 |
| constraints/example.xdc | 制約ファイルの例 |
| hardware/ | キャリア基板の KiCad 7 回路図、BOM、J7/J8 ピン割り当て、XDC 生成 ([hardware/README.md](../hardware/README.md)) |

## ビルドとシミュレーション

```
# シミュレーション (iverilog 12 以上)
cd sim && make MODE=1 FRAME=2      # 1080p 59.94 の 3 フレーム目を frame.ppm に保存

# Vivado
#  1. hdl/*.v, hdl/video_modes.vh, hdl/font8x16.mem をソースに追加 (top = top)
#  2. constraints/example.xdc をボードに合わせて編集して追加
#  3. top の MODE0..3 を Settings > General > Generics/Parameters で設定
#  4. Generate Bitstream
```

## 未実装・注意

- 音声出力なし。
- モード切替はビルド時固定。
- ADV7513 のレジスタ値は Programming Guide のクイックスタート値で、実機での確認が必要
  (特に 0x17 のシンク極性まわりと 0x18)。
- 同一 I2C バス上の 2 台は起動時に直列に初期化するが、HPD 再初期化が同時に走ると衝突する。
  ケーブルを同時に挿さない運用か、バスを 4 本に分けることで回避できる。
- 480p の 29.97/30(MODE 10/11)は CEA-861 にない規格外タイミング。

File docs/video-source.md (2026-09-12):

# 映像ソース(生成・再生)

LT86104SX は入力を複製するだけなので、Full HD 映像を作って HDMI で入力する機器が別途必要です。
ここでは「テスト映像の生成」と「その再生機」に必要なものをまとめます。

## 1. テスト映像の生成(PC で行う)

| 必要なもの | 備考 |
|---|---|
| ffmpeg / ffprobe | drawtext(libfreetype)有効ビルド。Ubuntu は `apt install ffmpeg`、Windows は gyan.dev の full ビルド |
| 等幅フォント | 既定は DejaVu Sans Mono Bold。環境変数 `FONT` で変更可 |
| bash | Windows は WSL または Git Bash |
| ディスク約 200 MB | 3 秒セグメントで master 約 30 MB × 5 本 |

```
tools/generate-test-video.sh out/test-video 3
```

生成されるもの:

- `master.mp4`: 1080p / 720p / 480p × 29.97p / 59.94p / 30p / 60p の 12 セグメントを連結した 1 本。キャンバスは 1920x1080、フレームレートは VFR で元の値を保持
- `output-1.mp4` 〜 `output-4.mp4`: master の複製(ファイルとして 4 本必要な場合用)
- `segments/`: 各組み合わせをネイティブ解像度のまま保存した個別ファイル

各フレームに「解像度 fps」ラベル、フレーム番号、タイムコードを焼き込んでいるので、4 出力のコマ落ちや遅延差を目視で確認できます。

### モード切替をネイティブでテストしたい場合

1 本のファイルに複数解像度は入らないため、master は 1080p キャンバスに拡大しています。
HDMI のモード切替(EDID ネゴシエーション、再ロック)をテストしたい場合は `segments/` のファイルを順に再生し、
再生機の出力モードをファイルに追従させます(`tools/play-loop.sh` の `--native` 参照)。

## 2. 再生機(HDMI ソース)の選定

| 候補 | 1080p60 | 59.94p の正確さ | モード切替 | 備考 |
|---|---|---|---|---|
| **Raspberry Pi 4 / 5** | ◎ | ○(KMS で 59.94 Hz 選択可) | ○ | 最小・安価。推奨 |
| ミニ PC(N100 等) | ◎ | ○ | ○ | mpv で安定。ffmpeg で生成も同じ機で可 |
| RK3588 ボード | ◎ | ○ | ○ | 将来 4 画面独立出力に移行するならこれ |
| ESP32-P4 + LT9611 | ×(1080p30 まで) | × | △ | 59.94p/60p が不可のため対象外 |

推奨は Raspberry Pi 4 または 5 です。必要なもの:

| 部品 | 備考 |
|---|---|
| Raspberry Pi 4 (2 GB 以上) または Pi 5 | Pi 5 は H.264 ハードウェアデコードがないが 1080p60 は CPU で足りる |
| microSD 16 GB 以上 | Raspberry Pi OS Lite(64bit) |
| micro HDMI → HDMI ケーブル | LT86104SX の入力へ |
| 5V 3A(Pi4) / 5V 5A(Pi5) 電源 | |
| mpv | `apt install mpv` |

### Raspberry Pi の設定

`/boot/firmware/cmdline.txt` に出力モードを固定します(1080p 59.94 Hz の例)。

```
video=HDMI-A-1:1920x1080@59.94D
```

モードを切り替えてテストする場合は固定せず、`tools/play-loop.sh --native` で mpv に切替させます。

デスクトップ不要のため DRM 直接出力を使います:

```
mpv --vo=drm --drm-connector=HDMI-A-1 --loop-file=inf --fs master.mp4
```

## 3. システム全体

```
[PC: ffmpeg で生成] --master.mp4--> [Raspberry Pi: mpv でループ再生]
                                              | HDMI 1080p
                                        [LT86104SX] ---> HDMI×4
                                              | I2C
                                           [ESP32]
```

## 4. 確認項目

- 4 出力ともフレーム番号が同時に進む(スプリッタの遅延は 1 フレーム未満)
- 29.97p ↔ 59.94p の切替でコマ落ち・テアリングがない(VFR 区間)
- モニタの情報表示で入力モードが 1080p 59.94/60 Hz と表示される
- 1 kHz テスト音が 4 出力すべてで出る

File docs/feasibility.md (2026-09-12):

# 実現可否の検討

## 要件

- Full HD(1920x1080)の映像を HDMI で 4 本出力する
- 最小構成にしたい
- ESP32 と LT86104SX を使う

## LT86104SX の能力

- HDMI 1.4 / DVI 1.0 準拠、1 入力 4 出力
- 3.4 Gbps/ch まで(1080p60 8bit は 1.485 Gbps/ch、Deep Color 12bit でも収まる)
- HDCP 1.4 リピータをハードウェアで処理
- EDID シャドウ RAM 内蔵(4 台の出力先の EDID を 1 つにまとめてソースへ提示)
- 受信側に CDR とアダプティブイコライザ、送信側にデエンファシス。長めのケーブルにも耐える

→ 1080p60 を 4 本へ複製する要件は IC 単体で満たす。

## ESP32 の能力

| 項目 | ESP32 / S3 | 1080p60 で必要な値 |
|---|---|---|
| 映像 I/F | なし(TMDS なし) | TMDS 3 レーン |
| 出力帯域 | 数十 Mbps 級(LCD/RGB パラレルで最大 80 MHz 程度) | 約 4.5 Gbps |
| フレームバッファ | PSRAM 最大 8〜16 MB | 1 フレーム 6 MB(RGB888) |

→ ESP32 は映像ソースになれない。役割は I2C による制御に限定する。

## 成立する構成

```
HDMI ソース ──> LT86104SX ──> HDMI×4
                  ^
                  | I2C
                ESP32
```

- 映像品質・解像度・フレームレート(29.97p / 59.94p / 30p / 60p)は **ソース側で決まる**。スプリッタは透過。
- ESP32 は起動時初期化、EDID 選択、入力信号検出、出力ポートの有効/無効、リモート操作を担当。

## 成立しない構成

- ESP32 が映像を生成して LT86104SX に入れる(帯域・I/F が無い)
- 4 本に異なる映像を出す(スプリッタは複製専用)

## 判断

**同一映像の 4 分配**であれば実現可能。ESP32 を組み合わせる価値は「ネットワーク経由での制御・監視」にある。

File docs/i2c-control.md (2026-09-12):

# ESP32 からの制御

LT86104SX は I2C スレーブとして動作します。レジスタの詳細は非公開のため、ここでは制御の枠組みと、実機で確認すべき項目を示します。

## I2C アドレス

- 7bit アドレスはアドレス選択ピンで決まります。
- 起動後にバススキャンして確認してください(`firmware/` の雛形はスキャンを行います)。

## 初期化シーケンス(概要)

1. RESET_N を Low に 10 ms 以上保持し、High にする
2. 20 ms 待つ
3. チップ ID レジスタを読み、応答を確認
4. Lontium 提供の初期化テーブル(レジスタ/値の配列)を順に書く
5. EDID モードを設定(下記)
6. 出力ポートを有効化

## EDID の扱い

| モード | 内容 | 用途 |
|---|---|---|
| 内蔵固定 EDID | 1080p60 固定の EDID をソースへ提示 | テスト用途で最も安定。モニタ未接続でも出力可 |
| 最小公倍(mix) | 4 出力先の EDID から共通能力を合成 | 混在モニタ |
| 特定ポートをコピー | OUT1 の EDID をそのまま提示 | 基準モニタがある場合 |

テスト映像(1080/720/480、29.97p/59.94p/30p/60p)を通す場合は、固定 EDID に各モードの DTD を含めておくとソース側の切替が確実になります。

## 監視

- INT ピンまたはポーリングで「入力信号あり/なし」「各出力の HPD」を取得
- 取得した状態を Wi-Fi 経由(HTTP / WebSocket)で公開すると、OBS-RemoteControl などから確認できます

## 実機で確認する項目

- [ ] I2C アドレス
- [ ] チップ ID レジスタとその期待値
- [ ] 初期化テーブル(代理店提供)
- [ ] EDID 書き込み手順(シャドウ RAM のアドレス)
- [ ] 出力ポート個別 ON/OFF のレジスタ
- [ ] 信号検出ステータスのレジスタ

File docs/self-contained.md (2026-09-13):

# 自己完結型: デバイス内で映像を生成し HDMI 4 本を出す

外部ソースも分配器も使わず、**1 台の中で Full HD テスト映像を生成し、HDMI コネクタ 4 本から直接出す**ための構成検討。

## 要件

- 1080p / 720p / 480p、29.97p / 59.94p / 30p / 60p のテスト映像を本体で生成する
- HDMI 出力 4 本(本体に 4 コネクタ)
- 分配器チップに頼らない(4 本を独立した表示パイプラインから出す)
- 最小構成

## 候補チップの比較

| チップ | 映像生成 | 表示出力数 | 4 本 HDMI にするには | 59.94p/60p | 入手性 | 判定 |
|---|---|---|---|---|---|---|
| **Rockchip RK3588** | ◎(H.264/H.265 デコード、GPU、CPU) | 4(HDMI2.1×2, DP1.4×2, eDP, DSI×2) | HDMI×2 ネイティブ + DP→HDMI 変換 IC×2 | ◎ | ◎(SoM 多数、Linux 公開) | **推奨** |
| FPGA(Artix-7 / Zynq-7000 / ECP5) | ○(パターン生成はロジックで容易。mp4 再生は不向き) | ロジック次第で 4 本以上 | HDMI TX IC(ADV7513 等)×4 | ◎(出力ごとに独立クロック) | ○ | 純粋な信号発生器なら最適 |
| x86 ミニ PC(Iris Xe 11 世代以降 / Ryzen APU) | ◎ | 4 | 2×HDMI + 2×USB-C(DP Alt)→HDMI ケーブル | ◎ | ◎ | 最短で動くが「チップ」ではなく完成品 |
| NXP i.MX 8QuadMax | ◎ | 4(HDMI/DP, DSI×2, LVDS×2) | DSI/LVDS→HDMI ブリッジ×3 | ○ | △(高価、複雑) | 不利 |
| ESP32-P4 | △(1080p30 まで) | 1(DSI 2 レーン) | 不可 | × | ◎ | 不可 |
| ESP32 / S3 / C3 | ×(帯域なし) | 0 | 不可 | × | ◎ | 不可 |
| Ambarella A7 | ○(カメラ SoC) | 1(HDMI×1) | 不可 | ○ | ×(NDA、旧世代) | 不可 |

## 推奨: RK3588

### 構成

```
                 +-------------------- RK3588 --------------------+
                 |  CPU/GPU/VPU: テスト映像を生成 (ffmpeg / mpv)   |
                 |  VOP: 4 つの表示ポート (VP0..VP3)                |
                 |   VP0 -> HDMI TX0 ------------------------------> HDMI OUT1
                 |   VP1 -> HDMI TX1 ------------------------------> HDMI OUT2
                 |   VP2 -> DP TX0  ---> [DP→HDMI 変換 IC] --------> HDMI OUT3
                 |   VP3 -> DP TX1  ---> [DP→HDMI 変換 IC] --------> HDMI OUT4
                 +-------------------------------------------------+
```

- HDMI 2.1 TX を 2 本ネイティブに持ち、残り 2 本は DP1.4 TX を **アクティブ DP→HDMI 変換 IC**(ITE IT6563、Realtek RTD2171、Parade PS176 など。いずれも 1080p60 は余裕)で HDMI 化する。
- DP を使わず MIPI-DSI×2 を **LT9611(DSI→HDMI1.4)** で変換しても 4 本にできる。DSI は 1080p60 まで。DP のほうが帯域に余裕があり、USB3 と PHY を共有する点だけ注意。
- 4 本は独立した CRTC なので、同一映像のミラーも、別々の映像も出せる。分配器は不要。

### ソフトウェア

- Linux(Armbian / Debian、Rockchip BSP カーネル)で 4 つの CRTC が DRM に見える。
- 同一映像を 4 本に出す: 1 枚のフレームバッファを 4 つの CRTC にアタッチする(KMS の clone)。Weston や X の mirror 設定で可能。
- 生成: `tools/generate-test-video.sh` を本体で実行(ffmpeg はソフトウェアエンコード)。再生: mpv の `--vo=drm` または Weston 上で再生。
- 出力ごとにモード(1080p59.94 / 1080p60 など)を個別に設定できる。ミラー時は同じモードに揃える。

### 入手できる形

| 形 | 例 | 4 本目までの出し方 |
|---|---|---|
| SoM + 自作キャリア | Firefly Core-3588J、Radxa CM5、Banana Pi CM5 | キャリアに HDMI×2 + DP→HDMI IC×2 を実装。最小構成に最も近い |
| 市販 SBC | Radxa ROCK 5B(HDMI×2 + USB-C DP)、Orange Pi 5 Plus | 3 本は変換ケーブルで出る。4 本目は DSI→HDMI アダプタ基板(LT9611 搭載)が必要 |
| 産業用ボード | Firefly ITX-3588J、AIO-3588Q | 4 画面出力を公式に謳う。コネクタ形状は製品ごとに異なる |

### BOM(SoM + 自作キャリアの場合)

| 部品 | 数 | 備考 |
|---|---|---|
| RK3588 SoM(4 GB 以上) | 1 | Core-3588J など |
| DP→HDMI 変換 IC(IT6563 等) | 2 | 1080p60 対応、ファーム内蔵タイプが楽 |
| HDMI レセプタクル | 4 | |
| ESD 保護(TMDS 用) | 4 セット | |
| 電源(12V 入力 + DC/DC) | 1 式 | SoM の要求に従う |
| eMMC / microSD | 1 | OS とテスト映像 |

## FPGA を選ぶ場合

「mp4 を再生」ではなく「テストパターンを出す装置」として割り切れるなら FPGA が最も素直です。

- カラーバー、フレームカウンタ、タイムコードはロジックと文字 ROM で生成でき、フレームバッファ不要。
- 出力ごとに PLL を持てるので、OUT1=59.94p、OUT2=60p のような **完全に独立したタイミング**を同時に出せる。同期検証やキャプチャカード評価に向く。
- HDMI TX は 1080p60 なら外付け IC(ADV7513 / IT66121、24bit RGB パラレル入力)を 4 個。FPGA から直接 TMDS を出す場合は 1.485 Gbps のシリアライザが必要で、Artix-7 の HR バンクでは規格外(Kintex-7 HP バンクか、Zynq UltraScale+ なら規格内)。
- 4 出力とも HDMI コネクタ付きの市販 FPGA ボードは無いので、キャリア自作か拡張ボードが必要。

## 使わない理由の記録

- **分配器(LT86104SX)**: 4 本が同一映像に固定され、出力ごとのタイミング差もつけられない。
- **ESP32**: 映像帯域がない。制御用マイコンとして残す価値もあるが、RK3588 なら本体だけで完結する。
- **Ambarella A7**: HDMI 1 本、SDK は NDA。

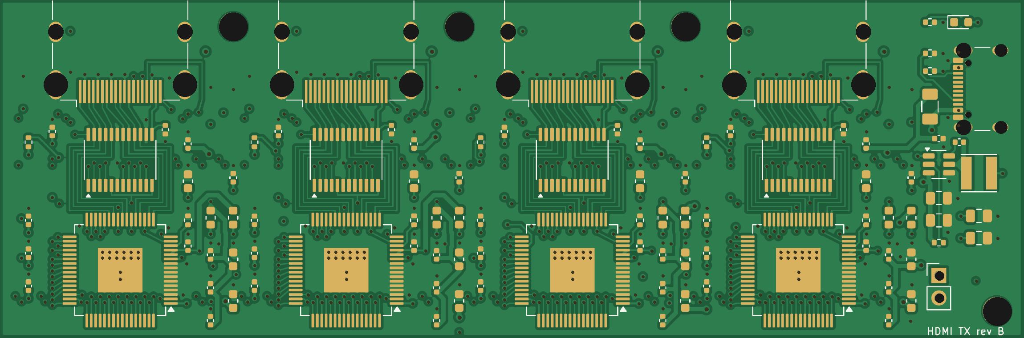
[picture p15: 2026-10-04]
hardware/quad_hdmi_tx/3d/tex_top.png

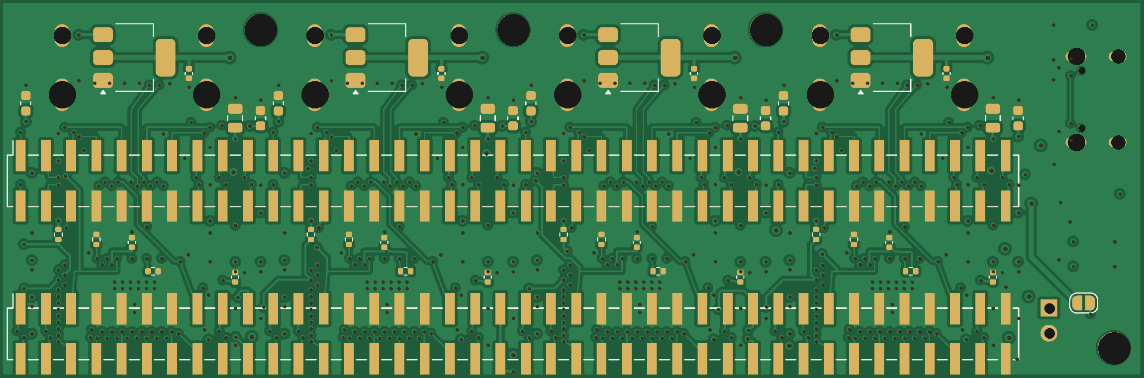
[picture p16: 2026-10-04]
hardware/quad_hdmi_tx/3d/tex_bot.png

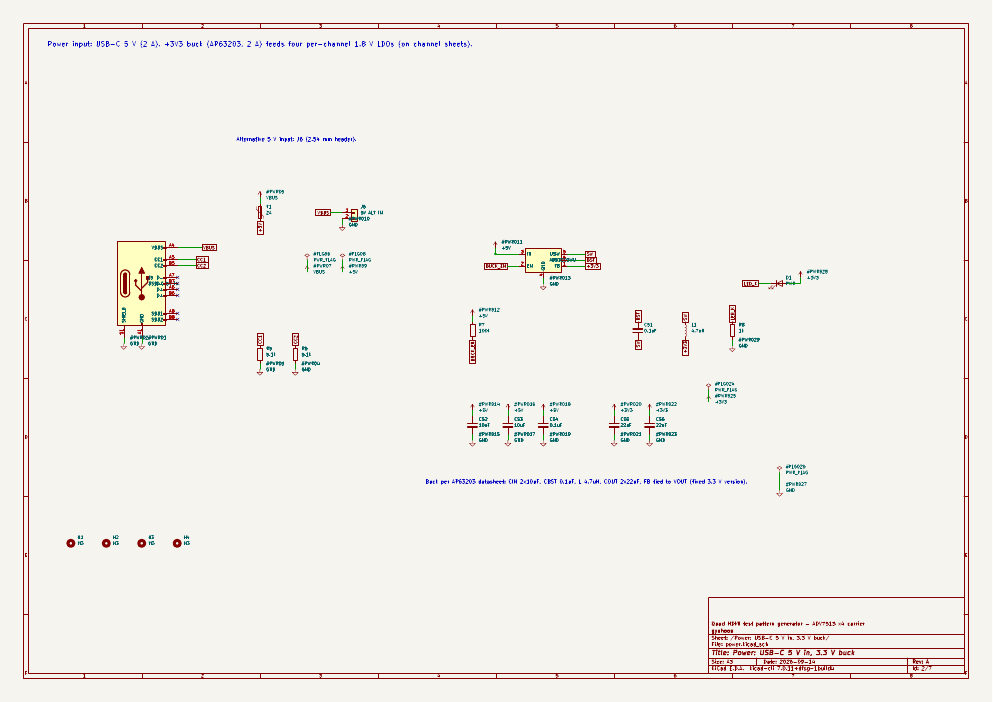
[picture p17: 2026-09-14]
docs/images/sch-power.png

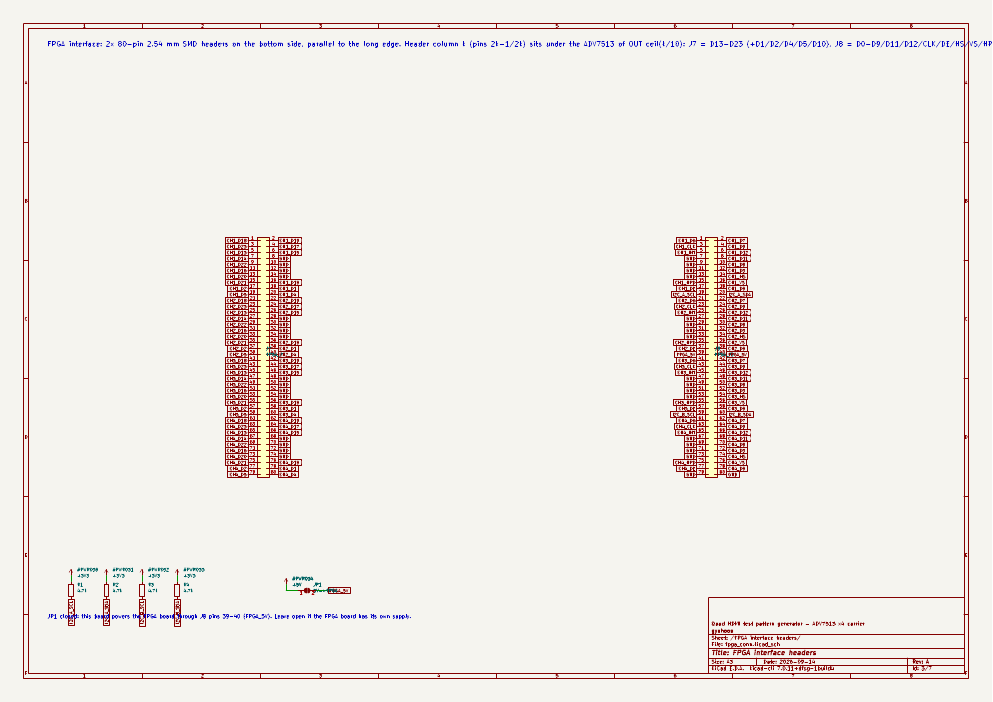
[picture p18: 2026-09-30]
docs/images/sch-fpga.png

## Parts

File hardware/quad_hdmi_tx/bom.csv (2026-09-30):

Reference | Value | Footprint | MPN | Description
C51 | 0.1uF | Capacitor_SMD:C_0402_1005Metric | GRM155R71C104KA88D | 0.1uF 16V X7R 0402 (bootstrap)
C52 | 10uF | Capacitor_SMD:C_0805_2012Metric | GRM21BR61A106KE19L | 10uF 10V X5R 0805
C53 | 10uF | Capacitor_SMD:C_0805_2012Metric | GRM21BR61A106KE19L | 10uF 10V X5R 0805
C54 | 0.1uF | Capacitor_SMD:C_0402_1005Metric | GRM155R71C104KA88D | 0.1uF 16V X7R 0402
C55 | 22uF | Capacitor_SMD:C_0805_2012Metric | GRM21BR60J226ME39L | 22uF 6.3V X5R 0805
C56 | 22uF | Capacitor_SMD:C_0805_2012Metric | GRM21BR60J226ME39L | 22uF 6.3V X5R 0805
C101 | 10uF | Capacitor_SMD:C_0603_1608Metric | GRM188R60J106ME47D | 10uF 6.3V X5R 0603
C102 | 22uF | Capacitor_SMD:C_0805_2012Metric | GRM21BR60J226ME39L | 22uF 6.3V X5R 0805
C103 | 0.1uF | Capacitor_SMD:C_0402_1005Metric | GRM155R71C104KA88D | 0.1uF 16V X7R 0402
C104 | 0.1uF | Capacitor_SMD:C_0402_1005Metric | GRM155R71C104KA88D | 0.1uF 16V X7R 0402
C105 | 0.1uF | Capacitor_SMD:C_0402_1005Metric | GRM155R71C104KA88D | 0.1uF 16V X7R 0402
C106 | 0.1uF | Capacitor_SMD:C_0402_1005Metric | GRM155R71C104KA88D | 0.1uF 16V X7R 0402
C107 | 0.1uF | Capacitor_SMD:C_0402_1005Metric | GRM155R71C104KA88D | 0.1uF 16V X7R 0402
C108 | 10uF | Capacitor_SMD:C_0603_1608Metric | GRM188R60J106ME47D | 10uF 6.3V X5R 0603
C109 | 0.1uF | Capacitor_SMD:C_0402_1005Metric | GRM155R71C104KA88D | 0.1uF 16V X7R 0402
C110 | 0.1uF | Capacitor_SMD:C_0402_1005Metric | GRM155R71C104KA88D | 0.1uF 16V X7R 0402
C111 | 0.1uF | Capacitor_SMD:C_0402_1005Metric | GRM155R71C104KA88D | 0.1uF 16V X7R 0402
C112 | 10uF | Capacitor_SMD:C_0603_1608Metric | GRM188R60J106ME47D | 10uF 6.3V X5R 0603
C113 | 0.1uF | Capacitor_SMD:C_0402_1005Metric | GRM155R71C104KA88D | 0.1uF 16V X7R 0402
C114 | 0.1uF | Capacitor_SMD:C_0402_1005Metric | GRM155R71C104KA88D | 0.1uF 16V X7R 0402
C115 | 1uF | Capacitor_SMD:C_0603_1608Metric | GRM188R61A105KA61D | 1uF 10V X5R 0603
C116 | 0.1uF | Capacitor_SMD:C_0402_1005Metric | GRM155R71C104KA88D | 0.1uF 16V X7R 0402
C117 | 0.1uF | Capacitor_SMD:C_0402_1005Metric | GRM155R71C104KA88D | 0.1uF 16V X7R 0402
C118 | 1uF | Capacitor_SMD:C_0603_1608Metric | GRM188R61A105KA61D | 1uF 10V X5R 0603
C119 | 0.1uF | Capacitor_SMD:C_0402_1005Metric | GRM155R71C104KA88D | 0.1uF 16V X7R 0402
C120 | 0.1uF | Capacitor_SMD:C_0402_1005Metric | GRM155R71C104KA88D | 0.1uF 16V X7R 0402
C201 | 10uF | Capacitor_SMD:C_0603_1608Metric | GRM188R60J106ME47D | 10uF 6.3V X5R 0603
C202 | 22uF | Capacitor_SMD:C_0805_2012Metric | GRM21BR60J226ME39L | 22uF 6.3V X5R 0805
C203 | 0.1uF | Capacitor_SMD:C_0402_1005Metric | GRM155R71C104KA88D | 0.1uF 16V X7R 0402
C204 | 0.1uF | Capacitor_SMD:C_0402_1005Metric | GRM155R71C104KA88D | 0.1uF 16V X7R 0402
C205 | 0.1uF | Capacitor_SMD:C_0402_1005Metric | GRM155R71C104KA88D | 0.1uF 16V X7R 0402
C206 | 0.1uF | Capacitor_SMD:C_0402_1005Metric | GRM155R71C104KA88D | 0.1uF 16V X7R 0402
C207 | 0.1uF | Capacitor_SMD:C_0402_1005Metric | GRM155R71C104KA88D | 0.1uF 16V X7R 0402
C208 | 10uF | Capacitor_SMD:C_0603_1608Metric | GRM188R60J106ME47D | 10uF 6.3V X5R 0603
C209 | 0.1uF | Capacitor_SMD:C_0402_1005Metric | GRM155R71C104KA88D | 0.1uF 16V X7R 0402
C210 | 0.1uF | Capacitor_SMD:C_0402_1005Metric | GRM155R71C104KA88D | 0.1uF 16V X7R 0402
C211 | 0.1uF | Capacitor_SMD:C_0402_1005Metric | GRM155R71C104KA88D | 0.1uF 16V X7R 0402
C212 | 10uF | Capacitor_SMD:C_0603_1608Metric | GRM188R60J106ME47D | 10uF 6.3V X5R 0603
C213 | 0.1uF | Capacitor_SMD:C_0402_1005Metric | GRM155R71C104KA88D | 0.1uF 16V X7R 0402
C214 | 0.1uF | Capacitor_SMD:C_0402_1005Metric | GRM155R71C104KA88D | 0.1uF 16V X7R 0402
C215 | 1uF | Capacitor_SMD:C_0603_1608Metric | GRM188R61A105KA61D | 1uF 10V X5R 0603
C216 | 0.1uF | Capacitor_SMD:C_0402_1005Metric | GRM155R71C104KA88D | 0.1uF 16V X7R 0402
C217 | 0.1uF | Capacitor_SMD:C_0402_1005Metric | GRM155R71C104KA88D | 0.1uF 16V X7R 0402
C218 | 1uF | Capacitor_SMD:C_0603_1608Metric | GRM188R61A105KA61D | 1uF 10V X5R 0603
C219 | 0.1uF | Capacitor_SMD:C_0402_1005Metric | GRM155R71C104KA88D | 0.1uF 16V X7R 0402
C220 | 0.1uF | Capacitor_SMD:C_0402_1005Metric | GRM155R71C104KA88D | 0.1uF 16V X7R 0402
C301 | 10uF | Capacitor_SMD:C_0603_1608Metric | GRM188R60J106ME47D | 10uF 6.3V X5R 0603
C302 | 22uF | Capacitor_SMD:C_0805_2012Metric | GRM21BR60J226ME39L | 22uF 6.3V X5R 0805
C303 | 0.1uF | Capacitor_SMD:C_0402_1005Metric | GRM155R71C104KA88D | 0.1uF 16V X7R 0402
C304 | 0.1uF | Capacitor_SMD:C_0402_1005Metric | GRM155R71C104KA88D | 0.1uF 16V X7R 0402
C305 | 0.1uF | Capacitor_SMD:C_0402_1005Metric | GRM155R71C104KA88D | 0.1uF 16V X7R 0402
C306 | 0.1uF | Capacitor_SMD:C_0402_1005Metric | GRM155R71C104KA88D | 0.1uF 16V X7R 0402
C307 | 0.1uF | Capacitor_SMD:C_0402_1005Metric | GRM155R71C104KA88D | 0.1uF 16V X7R 0402
C308 | 10uF | Capacitor_SMD:C_0603_1608Metric | GRM188R60J106ME47D | 10uF 6.3V X5R 0603
C309 | 0.1uF | Capacitor_SMD:C_0402_1005Metric | GRM155R71C104KA88D | 0.1uF 16V X7R 0402
C310 | 0.1uF | Capacitor_SMD:C_0402_1005Metric | GRM155R71C104KA88D | 0.1uF 16V X7R 0402
C311 | 0.1uF | Capacitor_SMD:C_0402_1005Metric | GRM155R71C104KA88D | 0.1uF 16V X7R 0402
C312 | 10uF | Capacitor_SMD:C_0603_1608Metric | GRM188R60J106ME47D | 10uF 6.3V X5R 0603
C313 | 0.1uF | Capacitor_SMD:C_0402_1005Metric | GRM155R71C104KA88D | 0.1uF 16V X7R 0402
C314 | 0.1uF | Capacitor_SMD:C_0402_1005Metric | GRM155R71C104KA88D | 0.1uF 16V X7R 0402
C315 | 1uF | Capacitor_SMD:C_0603_1608Metric | GRM188R61A105KA61D | 1uF 10V X5R 0603
C316 | 0.1uF | Capacitor_SMD:C_0402_1005Metric | GRM155R71C104KA88D | 0.1uF 16V X7R 0402
C317 | 0.1uF | Capacitor_SMD:C_0402_1005Metric | GRM155R71C104KA88D | 0.1uF 16V X7R 0402
C318 | 1uF | Capacitor_SMD:C_0603_1608Metric | GRM188R61A105KA61D | 1uF 10V X5R 0603
C319 | 0.1uF | Capacitor_SMD:C_0402_1005Metric | GRM155R71C104KA88D | 0.1uF 16V X7R 0402
C320 | 0.1uF | Capacitor_SMD:C_0402_1005Metric | GRM155R71C104KA88D | 0.1uF 16V X7R 0402
C401 | 10uF | Capacitor_SMD:C_0603_1608Metric | GRM188R60J106ME47D | 10uF 6.3V X5R 0603
C402 | 22uF | Capacitor_SMD:C_0805_2012Metric | GRM21BR60J226ME39L | 22uF 6.3V X5R 0805
C403 | 0.1uF | Capacitor_SMD:C_0402_1005Metric | GRM155R71C104KA88D | 0.1uF 16V X7R 0402
C404 | 0.1uF | Capacitor_SMD:C_0402_1005Metric | GRM155R71C104KA88D | 0.1uF 16V X7R 0402
C405 | 0.1uF | Capacitor_SMD:C_0402_1005Metric | GRM155R71C104KA88D | 0.1uF 16V X7R 0402
C406 | 0.1uF | Capacitor_SMD:C_0402_1005Metric | GRM155R71C104KA88D | 0.1uF 16V X7R 0402
C407 | 0.1uF | Capacitor_SMD:C_0402_1005Metric | GRM155R71C104KA88D | 0.1uF 16V X7R 0402
C408 | 10uF | Capacitor_SMD:C_0603_1608Metric | GRM188R60J106ME47D | 10uF 6.3V X5R 0603
C409 | 0.1uF | Capacitor_SMD:C_0402_1005Metric | GRM155R71C104KA88D | 0.1uF 16V X7R 0402
C410 | 0.1uF | Capacitor_SMD:C_0402_1005Metric | GRM155R71C104KA88D | 0.1uF 16V X7R 0402
C411 | 0.1uF | Capacitor_SMD:C_0402_1005Metric | GRM155R71C104KA88D | 0.1uF 16V X7R 0402
C412 | 10uF | Capacitor_SMD:C_0603_1608Metric | GRM188R60J106ME47D | 10uF 6.3V X5R 0603
C413 | 0.1uF | Capacitor_SMD:C_0402_1005Metric | GRM155R71C104KA88D | 0.1uF 16V X7R 0402
C414 | 0.1uF | Capacitor_SMD:C_0402_1005Metric | GRM155R71C104KA88D | 0.1uF 16V X7R 0402
C415 | 1uF | Capacitor_SMD:C_0603_1608Metric | GRM188R61A105KA61D | 1uF 10V X5R 0603
C416 | 0.1uF | Capacitor_SMD:C_0402_1005Metric | GRM155R71C104KA88D | 0.1uF 16V X7R 0402
C417 | 0.1uF | Capacitor_SMD:C_0402_1005Metric | GRM155R71C104KA88D | 0.1uF 16V X7R 0402
C418 | 1uF | Capacitor_SMD:C_0603_1608Metric | GRM188R61A105KA61D | 1uF 10V X5R 0603
C419 | 0.1uF | Capacitor_SMD:C_0402_1005Metric | GRM155R71C104KA88D | 0.1uF 16V X7R 0402
C420 | 0.1uF | Capacitor_SMD:C_0402_1005Metric | GRM155R71C104KA88D | 0.1uF 16V X7R 0402
D1 | PWR | LED_SMD:LED_0603_1608Metric | LTST-C193KGKT-5A | Green LED 0603
F1 | 2A | Fuse:Fuse_1206_3216Metric | 1206L200/12SLYR | PTC resettable fuse 2 A hold, 1206
FB11 | 120R@100MHz | Inductor_SMD:L_0603_1608Metric | BLM18PG121SN1D | Ferrite bead 0603
FB12 | 120R@100MHz | Inductor_SMD:L_0603_1608Metric | BLM18PG121SN1D | Ferrite bead 0603
FB21 | 120R@100MHz | Inductor_SMD:L_0603_1608Metric | BLM18PG121SN1D | Ferrite bead 0603
FB22 | 120R@100MHz | Inductor_SMD:L_0603_1608Metric | BLM18PG121SN1D | Ferrite bead 0603
FB31 | 120R@100MHz | Inductor_SMD:L_0603_1608Metric | BLM18PG121SN1D | Ferrite bead 0603
FB32 | 120R@100MHz | Inductor_SMD:L_0603_1608Metric | BLM18PG121SN1D | Ferrite bead 0603
FB41 | 120R@100MHz | Inductor_SMD:L_0603_1608Metric | BLM18PG121SN1D | Ferrite bead 0603
FB42 | 120R@100MHz | Inductor_SMD:L_0603_1608Metric | BLM18PG121SN1D | Ferrite bead 0603
H1 | M3 | MountingHole:MountingHole_3.2mm |  | Mounting hole M3
H2 | M3 | MountingHole:MountingHole_3.2mm |  | Mounting hole M3
H3 | M3 | MountingHole:MountingHole_3.2mm |  | Mounting hole M3
H4 | M3 | MountingHole:MountingHole_3.2mm |  | Mounting hole M3
J1 | HDMI_A | Connector_HDMI:HDMI_A_Molex_208658-1001_Horizontal | 208658-1001 | HDMI type A receptacle, right angle
J2 | HDMI_A | Connector_HDMI:HDMI_A_Molex_208658-1001_Horizontal | 208658-1001 | HDMI type A receptacle, right angle
J3 | HDMI_A | Connector_HDMI:HDMI_A_Molex_208658-1001_Horizontal | 208658-1001 | HDMI type A receptacle, right angle
J4 | HDMI_A | Connector_HDMI:HDMI_A_Molex_208658-1001_Horizontal | 208658-1001 | HDMI type A receptacle, right angle
J5 | USB-C 5V in | Connector_USB:USB_C_Receptacle_GCT_USB4105-xx-A_16P_TopMnt_Horizontal | USB4105-GF-A | USB-C receptacle 16P (power only)
J6 | 5V ALT IN | Connector_PinHeader_2.54mm:PinHeader_1x02_P2.54mm_Vertical |  | 2-pin header, alternative 5 V input
J7 | FPGA_J7 | Connector_PinHeader_2.54mm:PinHeader_2x40_P2.54mm_Vertical_SMD | TSM-140-01-L-DV | 2x40 pin header 2.54 mm, SMD, bottom side
J8 | FPGA_J8 | Connector_PinHeader_2.54mm:PinHeader_2x40_P2.54mm_Vertical_SMD | TSM-140-01-L-DV | 2x40 pin header 2.54 mm, SMD, bottom side
JP1 | 5V->FPGA | Jumper:SolderJumper-2_P1.3mm_Open_RoundedPad1.0x1.5mm |  | Solder jumper: feed +5V to FPGA board via J8 pins 39/40
L1 | 4.7uH | Inductor_SMD:L_Taiyo-Yuden_NR-40xx | NR4018T4R7M | 4.7uH 2.2A shielded inductor 4x4 mm
R1 | 4.7k | Resistor_SMD:R_0402_1005Metric | RC0402FR-074K7L | 4.7k 0402 (I2C pull-up)
R2 | 4.7k | Resistor_SMD:R_0402_1005Metric | RC0402FR-074K7L | 4.7k 0402 (I2C pull-up)
R3 | 4.7k | Resistor_SMD:R_0402_1005Metric | RC0402FR-074K7L | 4.7k 0402 (I2C pull-up)
R4 | 4.7k | Resistor_SMD:R_0402_1005Metric | RC0402FR-074K7L | 4.7k 0402 (I2C pull-up)
R5 | 5.1k | Resistor_SMD:R_0402_1005Metric | RC0402FR-075K1L | 5.1k 0402 (USB-C sink CC)
R6 | 5.1k | Resistor_SMD:R_0402_1005Metric | RC0402FR-075K1L | 5.1k 0402 (USB-C sink CC)
R7 | 100k | Resistor_SMD:R_0402_1005Metric | RC0402FR-07100KL | 100k 0402 (EN pull-up to VIN)
R8 | 1k | Resistor_SMD:R_0402_1005Metric | RC0402FR-071KL | 1k 0402
R11 | 887R 1% | Resistor_SMD:R_0402_1005Metric | RC0402FR-07887RL | 887 ohm 1% 0402 (TMDS current reference)
R12 | 10k | Resistor_SMD:R_0402_1005Metric | RC0402FR-0710KL | 10k 0402 (I2C address select)
R13 | 10k | Resistor_SMD:R_0402_1005Metric | RC0402FR-0710KL | 10k 0402 (INT pull-up)
R14 | 0R | Resistor_SMD:R_0402_1005Metric | RC0402FR-070RL | 0 ohm 0402
R21 | 887R 1% | Resistor_SMD:R_0402_1005Metric | RC0402FR-07887RL | 887 ohm 1% 0402 (TMDS current reference)
R22 | 10k | Resistor_SMD:R_0402_1005Metric | RC0402FR-0710KL | 10k 0402 (I2C address select)
R23 | 10k | Resistor_SMD:R_0402_1005Metric | RC0402FR-0710KL | 10k 0402 (INT pull-up)
R24 | 0R | Resistor_SMD:R_0402_1005Metric | RC0402FR-070RL | 0 ohm 0402
R31 | 887R 1% | Resistor_SMD:R_0402_1005Metric | RC0402FR-07887RL | 887 ohm 1% 0402 (TMDS current reference)
R32 | 10k | Resistor_SMD:R_0402_1005Metric | RC0402FR-0710KL | 10k 0402 (I2C address select)
R33 | 10k | Resistor_SMD:R_0402_1005Metric | RC0402FR-0710KL | 10k 0402 (INT pull-up)
R34 | 0R | Resistor_SMD:R_0402_1005Metric | RC0402FR-070RL | 0 ohm 0402
R41 | 887R 1% | Resistor_SMD:R_0402_1005Metric | RC0402FR-07887RL | 887 ohm 1% 0402 (TMDS current reference)
R42 | 10k | Resistor_SMD:R_0402_1005Metric | RC0402FR-0710KL | 10k 0402 (I2C address select)
R43 | 10k | Resistor_SMD:R_0402_1005Metric | RC0402FR-0710KL | 10k 0402 (INT pull-up)
R44 | 0R | Resistor_SMD:R_0402_1005Metric | RC0402FR-070RL | 0 ohm 0402
U5 | AP63203WU | Package_TO_SOT_SMD:TSOT-23-6 | AP63203WU-7 | 3.3 V 2 A synchronous buck, TSOT-23-6
U11 | ADV7513BSWZ | Package_QFP:LQFP-64-1EP_10x10mm_P0.5mm_EP5x5mm | ADV7513BSWZ | HDMI 1.4 transmitter, 165 MHz, LQFP-64 EP
U12 | TPD12S016PWR | Package_SO:TSSOP-24_4.4x7.8mm_P0.65mm | TPD12S016PWR | HDMI ESD/level shifter/5V load switch, TSSOP-24
U13 | TLV1117LV18DCYR | Package_TO_SOT_SMD:SOT-223-3_TabPin2 | TLV1117LV18DCYR | 1.8 V 1 A LDO, SOT-223 (AMS1117-1.8 pin compatible)
U21 | ADV7513BSWZ | Package_QFP:LQFP-64-1EP_10x10mm_P0.5mm_EP5x5mm | ADV7513BSWZ | HDMI 1.4 transmitter, 165 MHz, LQFP-64 EP
U22 | TPD12S016PWR | Package_SO:TSSOP-24_4.4x7.8mm_P0.65mm | TPD12S016PWR | HDMI ESD/level shifter/5V load switch, TSSOP-24
U23 | TLV1117LV18DCYR | Package_TO_SOT_SMD:SOT-223-3_TabPin2 | TLV1117LV18DCYR | 1.8 V 1 A LDO, SOT-223 (AMS1117-1.8 pin compatible)
U31 | ADV7513BSWZ | Package_QFP:LQFP-64-1EP_10x10mm_P0.5mm_EP5x5mm | ADV7513BSWZ | HDMI 1.4 transmitter, 165 MHz, LQFP-64 EP
U32 | TPD12S016PWR | Package_SO:TSSOP-24_4.4x7.8mm_P0.65mm | TPD12S016PWR | HDMI ESD/level shifter/5V load switch, TSSOP-24
U33 | TLV1117LV18DCYR | Package_TO_SOT_SMD:SOT-223-3_TabPin2 | TLV1117LV18DCYR | 1.8 V 1 A LDO, SOT-223 (AMS1117-1.8 pin compatible)
U41 | ADV7513BSWZ | Package_QFP:LQFP-64-1EP_10x10mm_P0.5mm_EP5x5mm | ADV7513BSWZ | HDMI 1.4 transmitter, 165 MHz, LQFP-64 EP
U42 | TPD12S016PWR | Package_SO:TSSOP-24_4.4x7.8mm_P0.65mm | TPD12S016PWR | HDMI ESD/level shifter/5V load switch, TSSOP-24
U43 | TLV1117LV18DCYR | Package_TO_SOT_SMD:SOT-223-3_TabPin2 | TLV1117LV18DCYR | 1.8 V 1 A LDO, SOT-223 (AMS1117-1.8 pin compatible)

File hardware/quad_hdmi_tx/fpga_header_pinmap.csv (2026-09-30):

Header | Pin | Signal | FPGA_pin(fill in) | Direction(FPGA)
J7 | 1 | CH1_D18 |  | out
J7 | 2 | CH1_D19 |  | out
J7 | 3 | CH1_D23 |  | out
J7 | 4 | CH1_D17 |  | out
J7 | 5 | CH1_D13 |  | out
J7 | 6 | CH1_D15 |  | out
J7 | 7 | CH1_D14 |  | out
J7 | 8 | GND
J7 | 9 | CH1_D22 |  | out
J7 | 10 | GND
J7 | 11 | CH1_D16 |  | out
J7 | 12 | GND
J7 | 13 | CH1_D20 |  | out
J7 | 14 | GND
J7 | 15 | CH1_D21 |  | out
J7 | 16 | CH1_D10 |  | out
J7 | 17 | CH1_D2 |  | out
J7 | 18 | CH1_D1 |  | out
J7 | 19 | CH1_D5 |  | out
J7 | 20 | CH1_D4 |  | out
J7 | 21 | CH2_D18 |  | out
J7 | 22 | CH2_D19 |  | out
J7 | 23 | CH2_D23 |  | out
J7 | 24 | CH2_D17 |  | out
J7 | 25 | CH2_D13 |  | out
J7 | 26 | CH2_D15 |  | out
J7 | 27 | CH2_D14 |  | out
J7 | 28 | GND
J7 | 29 | CH2_D22 |  | out
J7 | 30 | GND
J7 | 31 | CH2_D16 |  | out
J7 | 32 | GND
J7 | 33 | CH2_D20 |  | out
J7 | 34 | GND
J7 | 35 | CH2_D21 |  | out
J7 | 36 | CH2_D10 |  | out
J7 | 37 | CH2_D2 |  | out
J7 | 38 | CH2_D1 |  | out
J7 | 39 | CH2_D5 |  | out
J7 | 40 | CH2_D4 |  | out
J7 | 41 | CH3_D18 |  | out
J7 | 42 | CH3_D19 |  | out
J7 | 43 | CH3_D23 |  | out
J7 | 44 | CH3_D17 |  | out
J7 | 45 | CH3_D13 |  | out
J7 | 46 | CH3_D15 |  | out
J7 | 47 | CH3_D14 |  | out
J7 | 48 | GND
J7 | 49 | CH3_D22 |  | out
J7 | 50 | GND
J7 | 51 | CH3_D16 |  | out
J7 | 52 | GND
J7 | 53 | CH3_D20 |  | out
J7 | 54 | GND
J7 | 55 | CH3_D21 |  | out
J7 | 56 | CH3_D10 |  | out
J7 | 57 | CH3_D2 |  | out
J7 | 58 | CH3_D1 |  | out
J7 | 59 | CH3_D5 |  | out
J7 | 60 | CH3_D4 |  | out
J7 | 61 | CH4_D18 |  | out
J7 | 62 | CH4_D19 |  | out
J7 | 63 | CH4_D23 |  | out
J7 | 64 | CH4_D17 |  | out
J7 | 65 | CH4_D13 |  | out
J7 | 66 | CH4_D15 |  | out
J7 | 67 | CH4_D14 |  | out
J7 | 68 | GND
J7 | 69 | CH4_D22 |  | out
J7 | 70 | GND
J7 | 71 | CH4_D16 |  | out
J7 | 72 | GND
J7 | 73 | CH4_D20 |  | out
J7 | 74 | GND
J7 | 75 | CH4_D21 |  | out
J7 | 76 | CH4_D10 |  | out
J7 | 77 | CH4_D2 |  | out
J7 | 78 | CH4_D1 |  | out
J7 | 79 | CH4_D5 |  | out
J7 | 80 | CH4_D4 |  | out
J8 | 1 | CH1_D6 |  | out
J8 | 2 | CH1_D7 |  | out
J8 | 3 | CH1_CLK |  | out
J8 | 4 | CH1_D9 |  | out
J8 | 5 | CH1_INT |  | in
J8 | 6 | CH1_D12 |  | out
J8 | 7 | GND
J8 | 8 | CH1_D11 |  | out
J8 | 9 | GND
J8 | 10 | CH1_D8 |  | out
J8 | 11 | GND
J8 | 12 | CH1_D3 |  | out
J8 | 13 | GND
J8 | 14 | CH1_HS |  | out
J8 | 15 | CH1_HPD |  | in
J8 | 16 | CH1_VS |  | out
J8 | 17 | CH1_DE |  | out
J8 | 18 | CH1_D0 |  | out
J8 | 19 | I2C_A_SCL |  | out
J8 | 20 | I2C_A_SDA |  | inout
J8 | 21 | CH2_D6 |  | out
J8 | 22 | CH2_D7 |  | out
J8 | 23 | CH2_CLK |  | out
J8 | 24 | CH2_D9 |  | out
J8 | 25 | CH2_INT |  | in
J8 | 26 | CH2_D12 |  | out
J8 | 27 | GND
J8 | 28 | CH2_D11 |  | out
J8 | 29 | GND
J8 | 30 | CH2_D8 |  | out
J8 | 31 | GND
J8 | 32 | CH2_D3 |  | out
J8 | 33 | GND
J8 | 34 | CH2_HS |  | out
J8 | 35 | CH2_HPD |  | in
J8 | 36 | CH2_VS |  | out
J8 | 37 | CH2_DE |  | out
J8 | 38 | CH2_D0 |  | out
J8 | 39 | FPGA_5V
J8 | 40 | FPGA_5V
J8 | 41 | CH3_D6 |  | out
J8 | 42 | CH3_D7 |  | out
J8 | 43 | CH3_CLK |  | out
J8 | 44 | CH3_D9 |  | out
J8 | 45 | CH3_INT |  | in
J8 | 46 | CH3_D12 |  | out
J8 | 47 | GND
J8 | 48 | CH3_D11 |  | out
J8 | 49 | GND
J8 | 50 | CH3_D8 |  | out
J8 | 51 | GND
J8 | 52 | CH3_D3 |  | out
J8 | 53 | GND
J8 | 54 | CH3_HS |  | out
J8 | 55 | CH3_HPD |  | in
J8 | 56 | CH3_VS |  | out
J8 | 57 | CH3_DE |  | out
J8 | 58 | CH3_D0 |  | out
J8 | 59 | I2C_B_SCL |  | out
J8 | 60 | I2C_B_SDA |  | inout
J8 | 61 | CH4_D6 |  | out
J8 | 62 | CH4_D7 |  | out
J8 | 63 | CH4_CLK |  | out
J8 | 64 | CH4_D9 |  | out
J8 | 65 | CH4_INT |  | in
J8 | 66 | CH4_D12 |  | out
J8 | 67 | GND
J8 | 68 | CH4_D11 |  | out
J8 | 69 | GND
J8 | 70 | CH4_D8 |  | out
J8 | 71 | GND
J8 | 72 | CH4_D3 |  | out
J8 | 73 | GND
J8 | 74 | CH4_HS |  | out
J8 | 75 | CH4_HPD |  | in
J8 | 76 | CH4_VS |  | out
J8 | 77 | CH4_DE |  | out
J8 | 78 | CH4_D0 |  | out
J8 | 79 | GND
J8 | 80 | GND

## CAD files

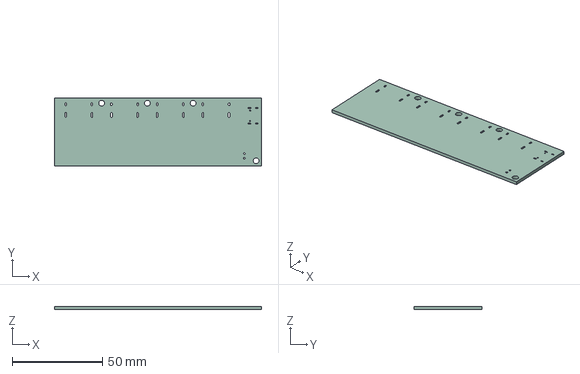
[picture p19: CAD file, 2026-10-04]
hardware/quad_hdmi_tx/3d/quad_hdmi_tx.step
115.0 x 38.0 x 1.60 mm

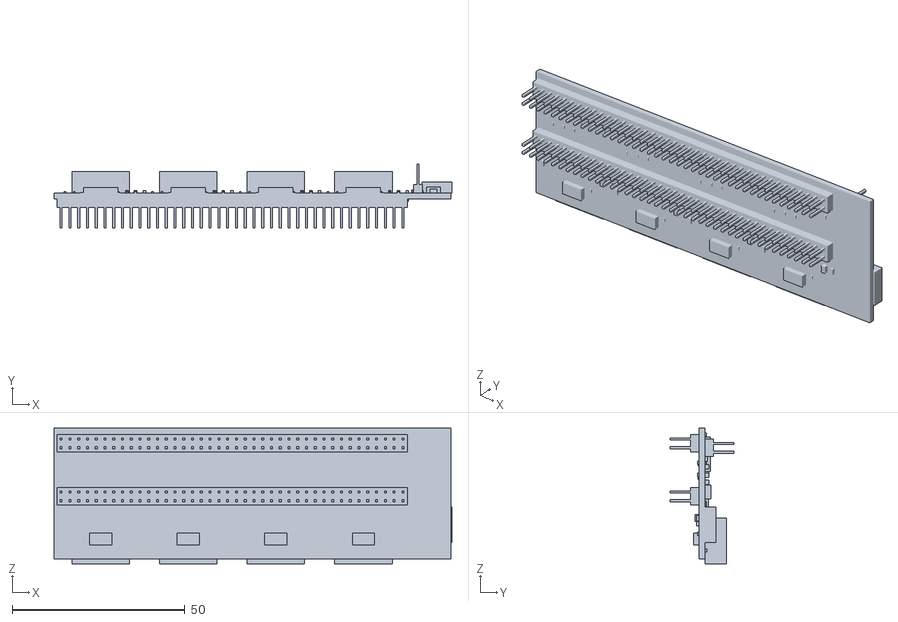
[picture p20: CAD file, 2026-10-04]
hardware/quad_hdmi_tx/3d/quad_hdmi_tx_simplified.obj
115.4 x 18.6 x 39.4

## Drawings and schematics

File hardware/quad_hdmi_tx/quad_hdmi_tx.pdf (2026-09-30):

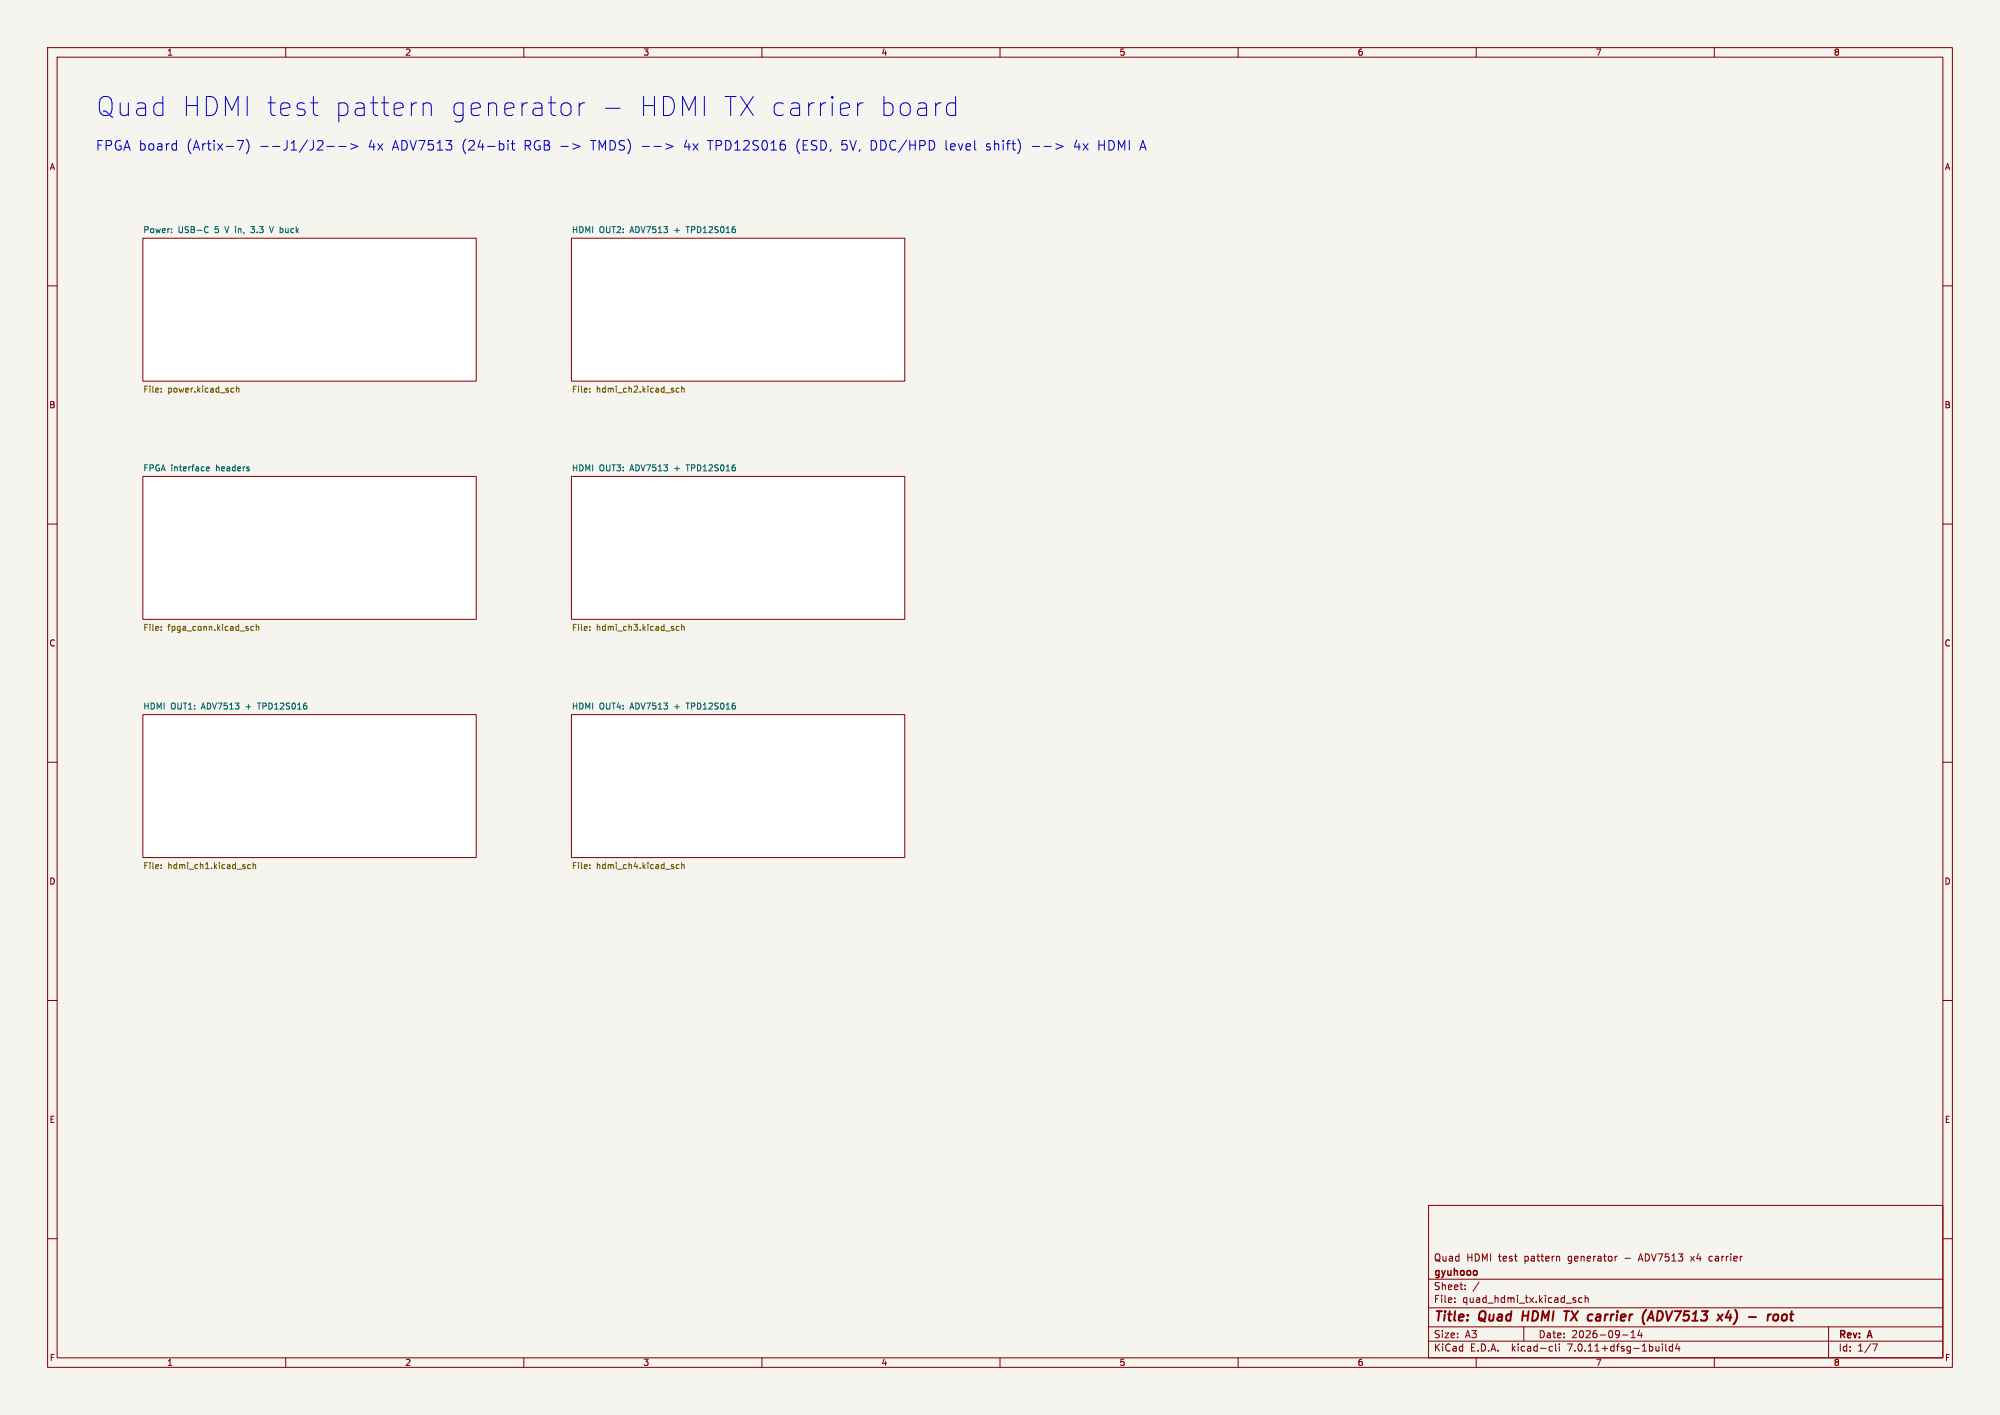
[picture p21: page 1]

Id: 1/7 Title: Quad HDMI TX carrier (ADV7513 x4) - root File: quad_hdmi_tx.kicad_sch Sheet: / gyuhooo

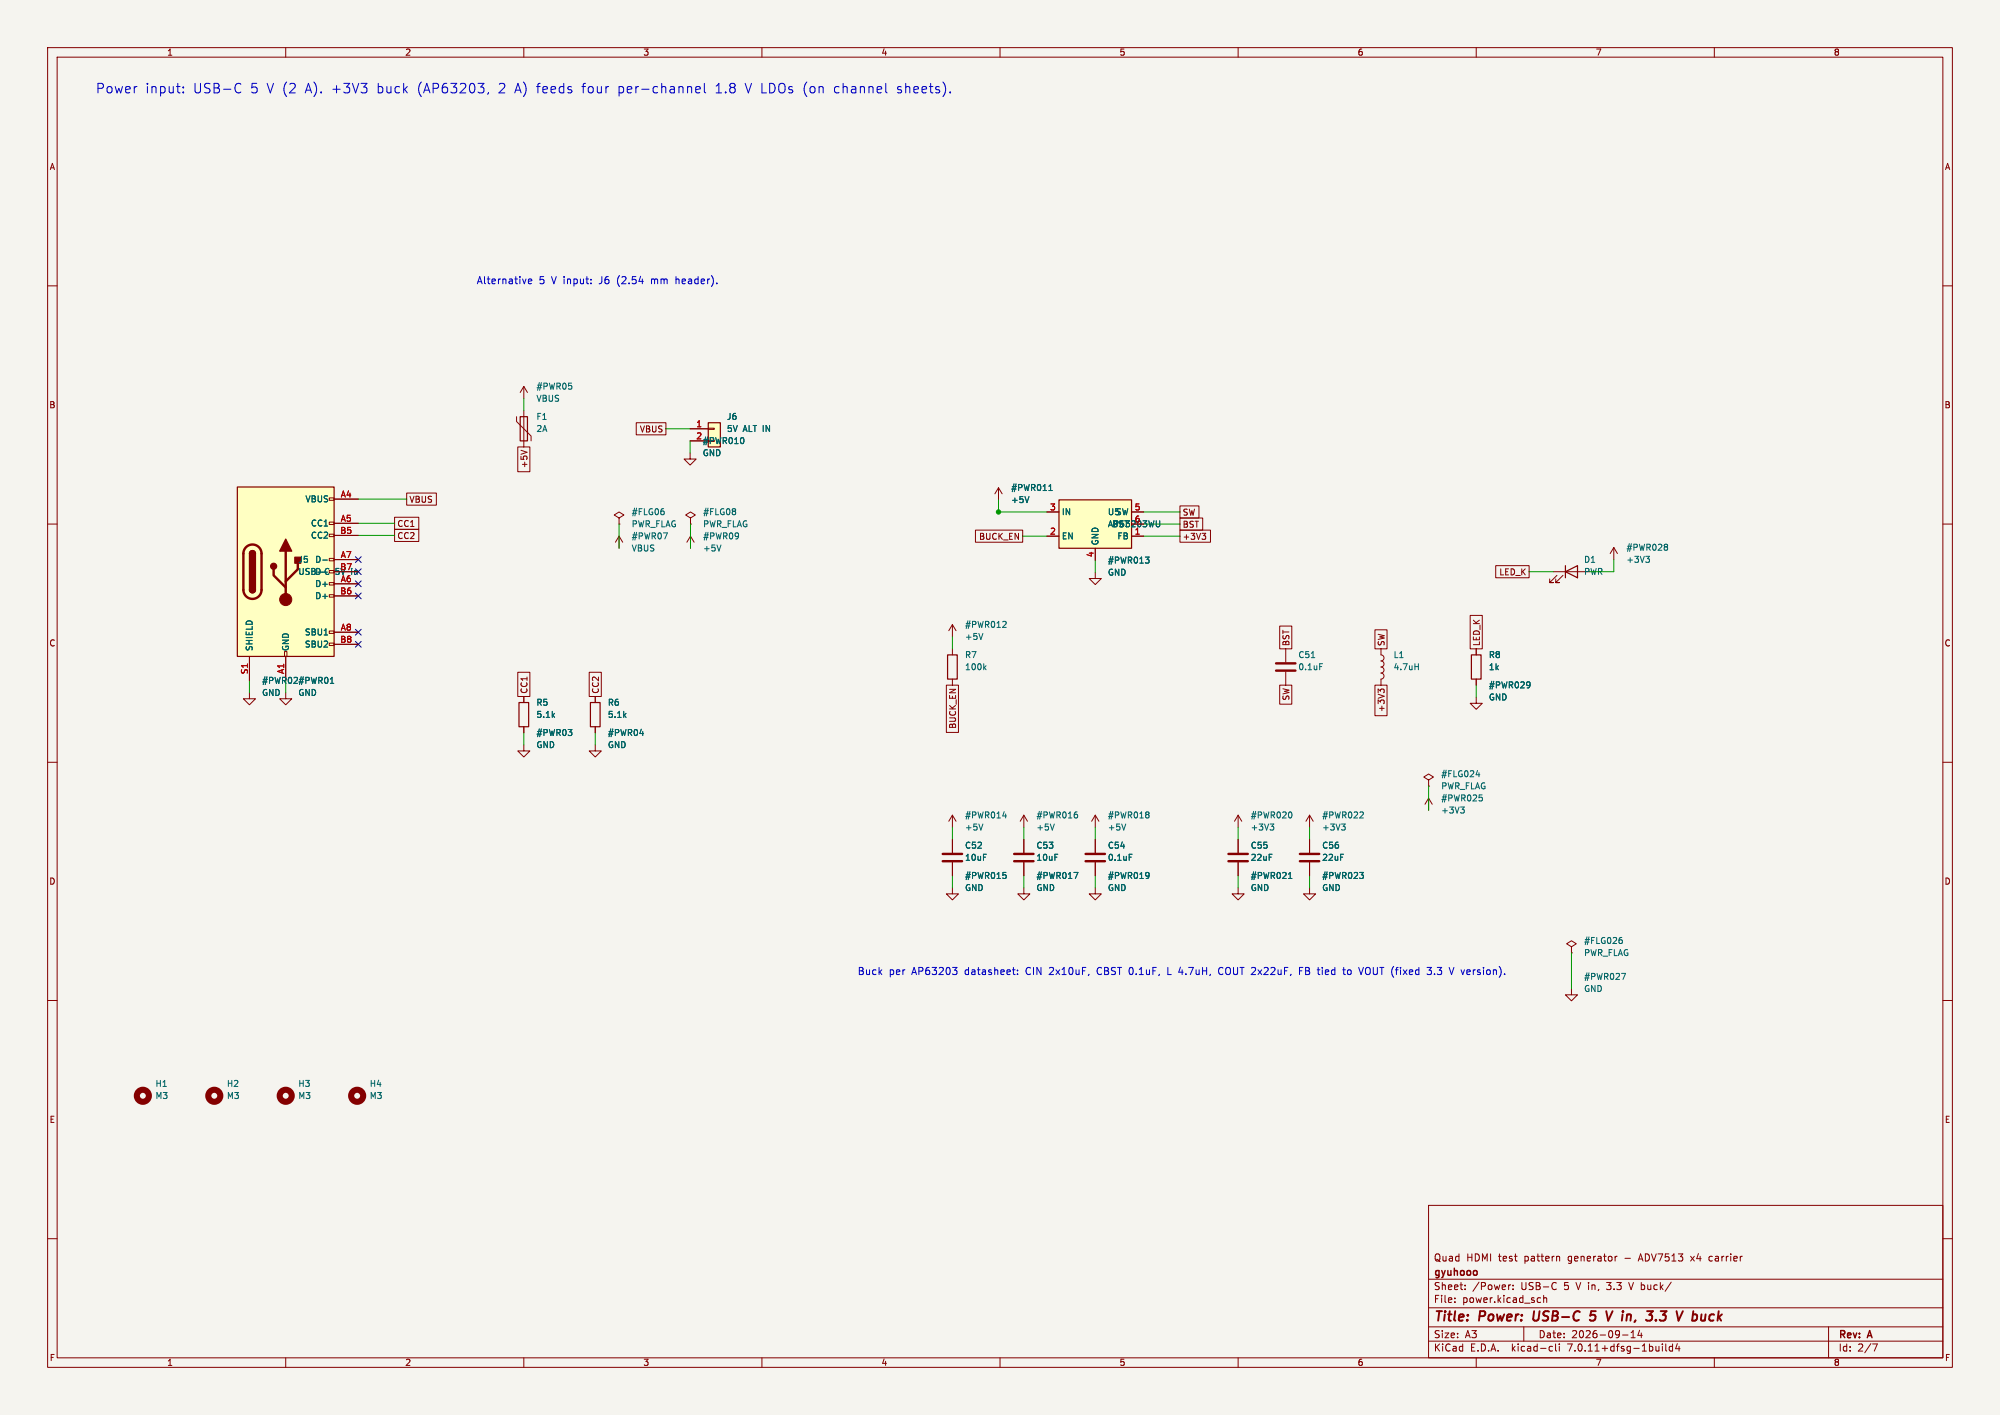
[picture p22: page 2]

Id: 2/7 Title: Power: USB-C 5 V in, 3.3 V buck

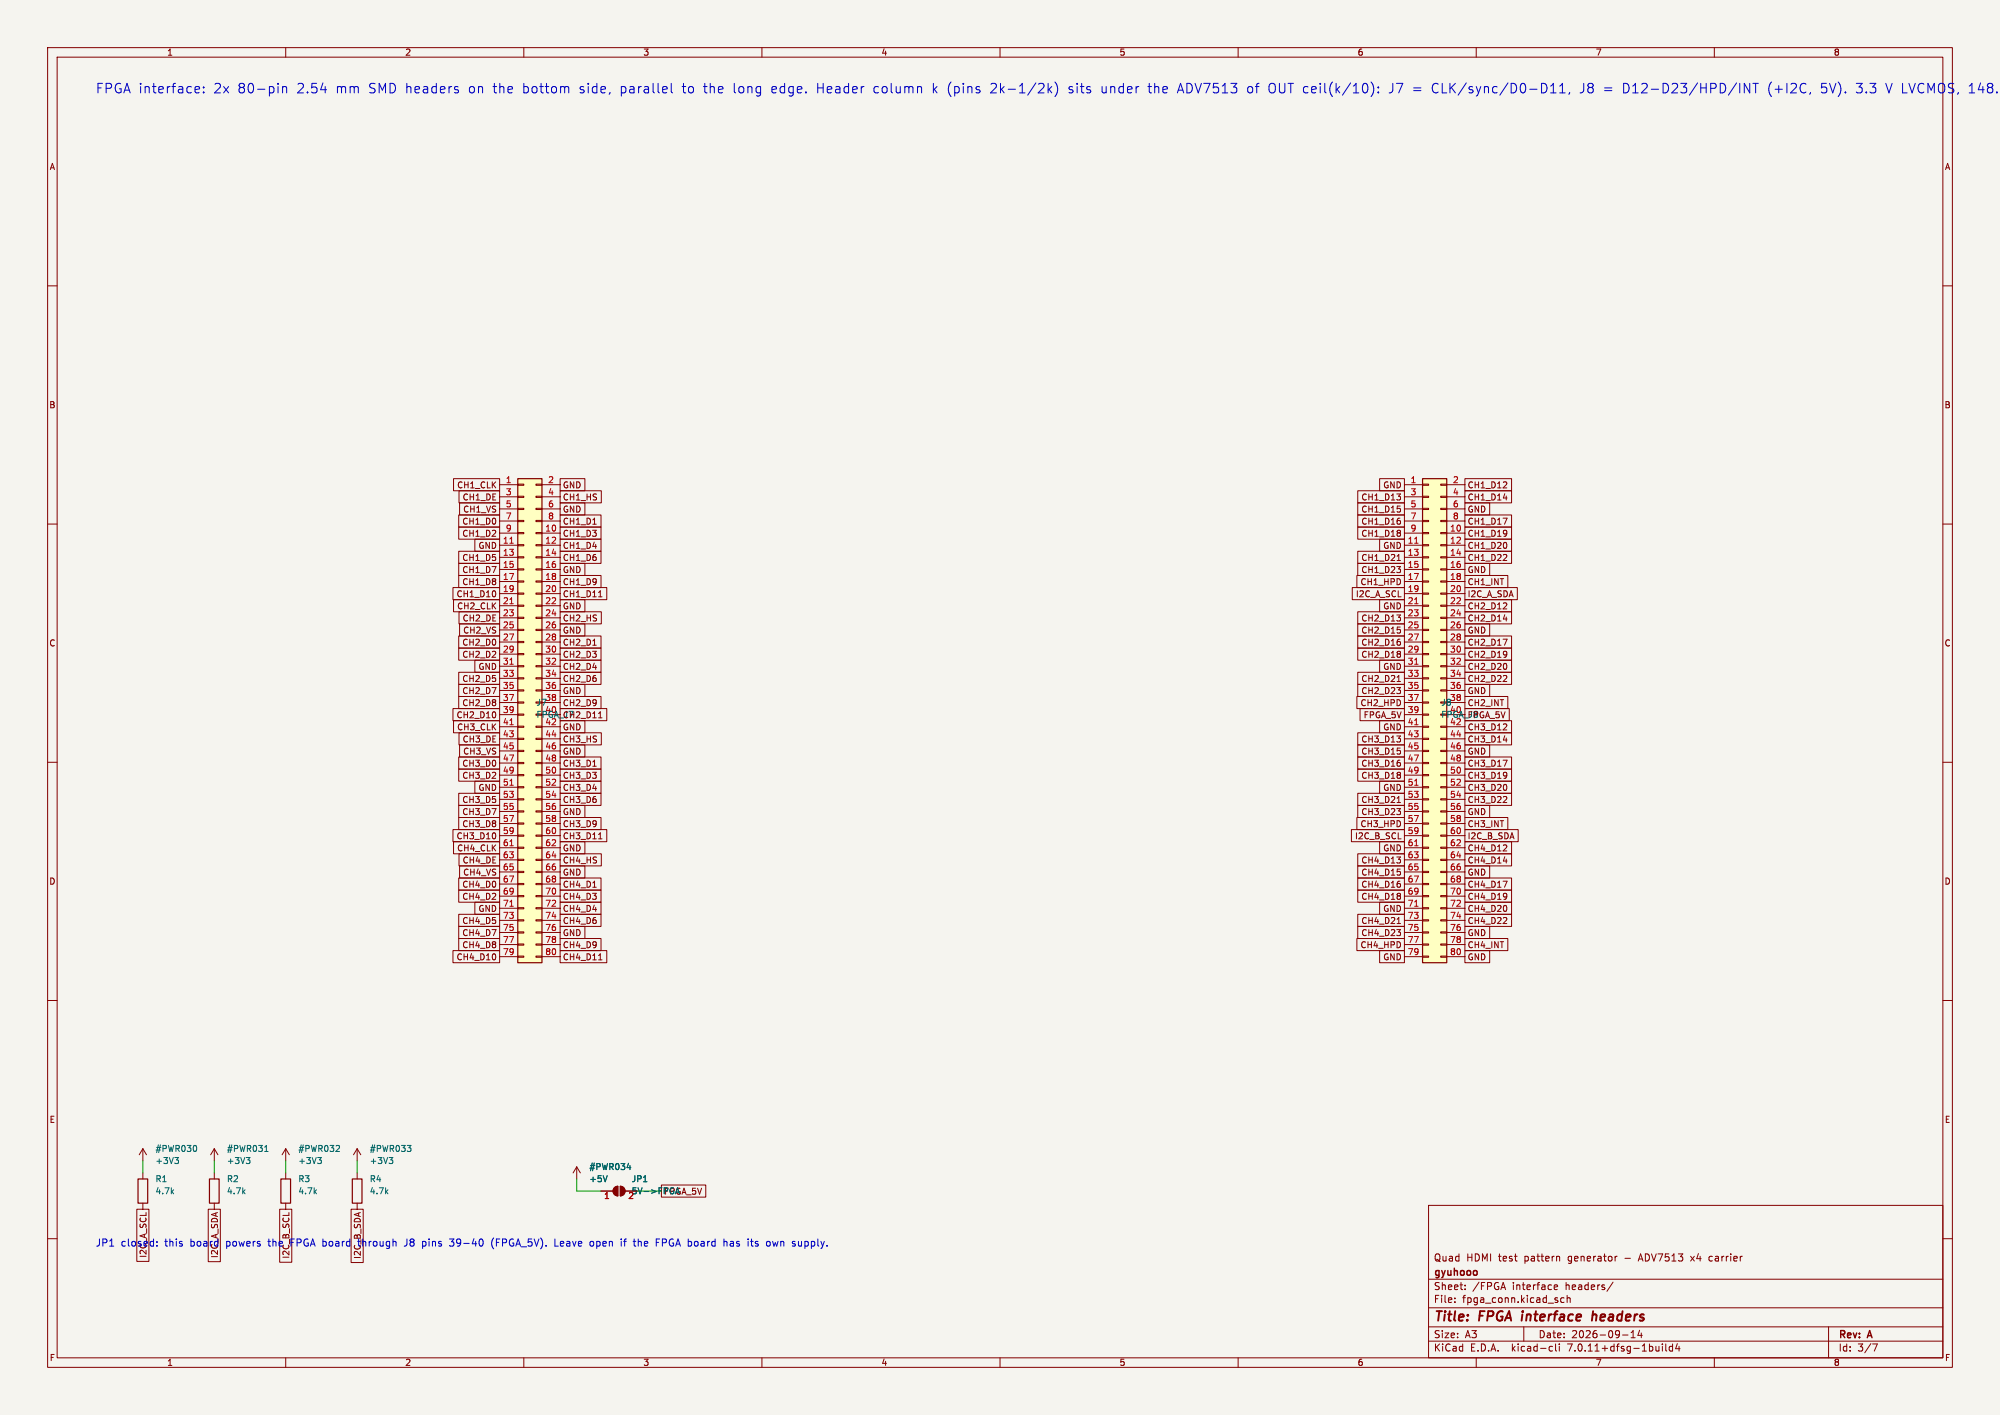
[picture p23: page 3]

Id: 3/7 Title: FPGA interface headers

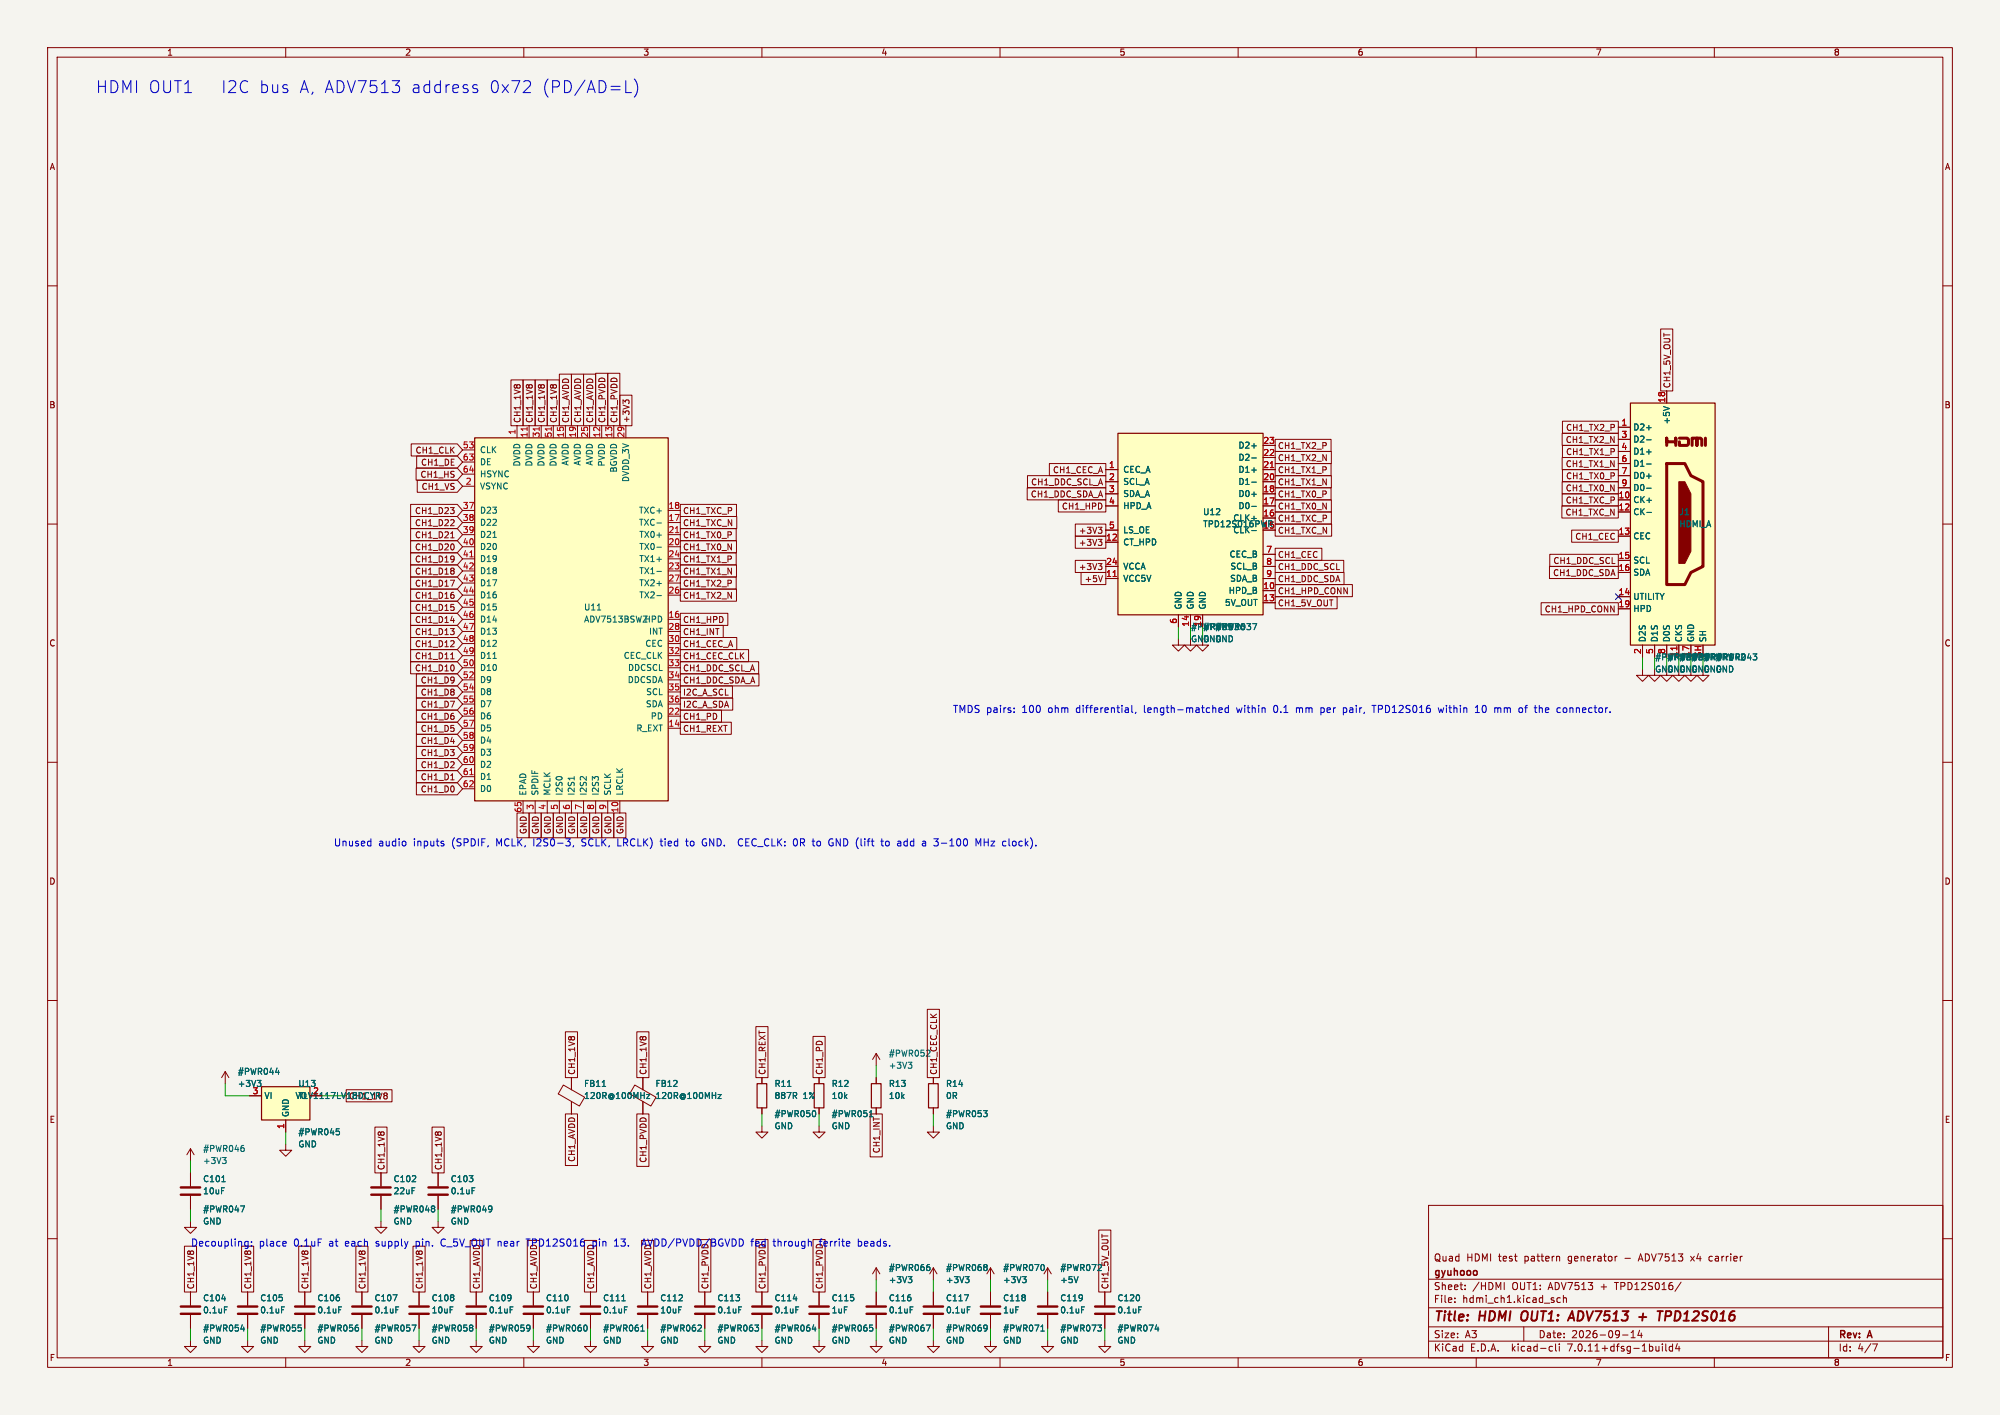
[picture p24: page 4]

3 CEC 30 DVDD 31 CEC_CLK 32 DDCSCL 33 DDCSDA 34 SCL 35 SDA 36 D23 37 D22 38 D21 39 MCLK

1 LRCLK 10 DVDD 11 PVDD 12 BGVDD 13 R_EXT 14 AVDD 15 HPD 16 TXC- 17 TXC+ 18 AVDD 19 VSYNC 2 TX0- 20 TX0+ 21 PD 22 TX1- 23 TX1+ 24 AVDD 25 TX2- 26 TX2+ 27

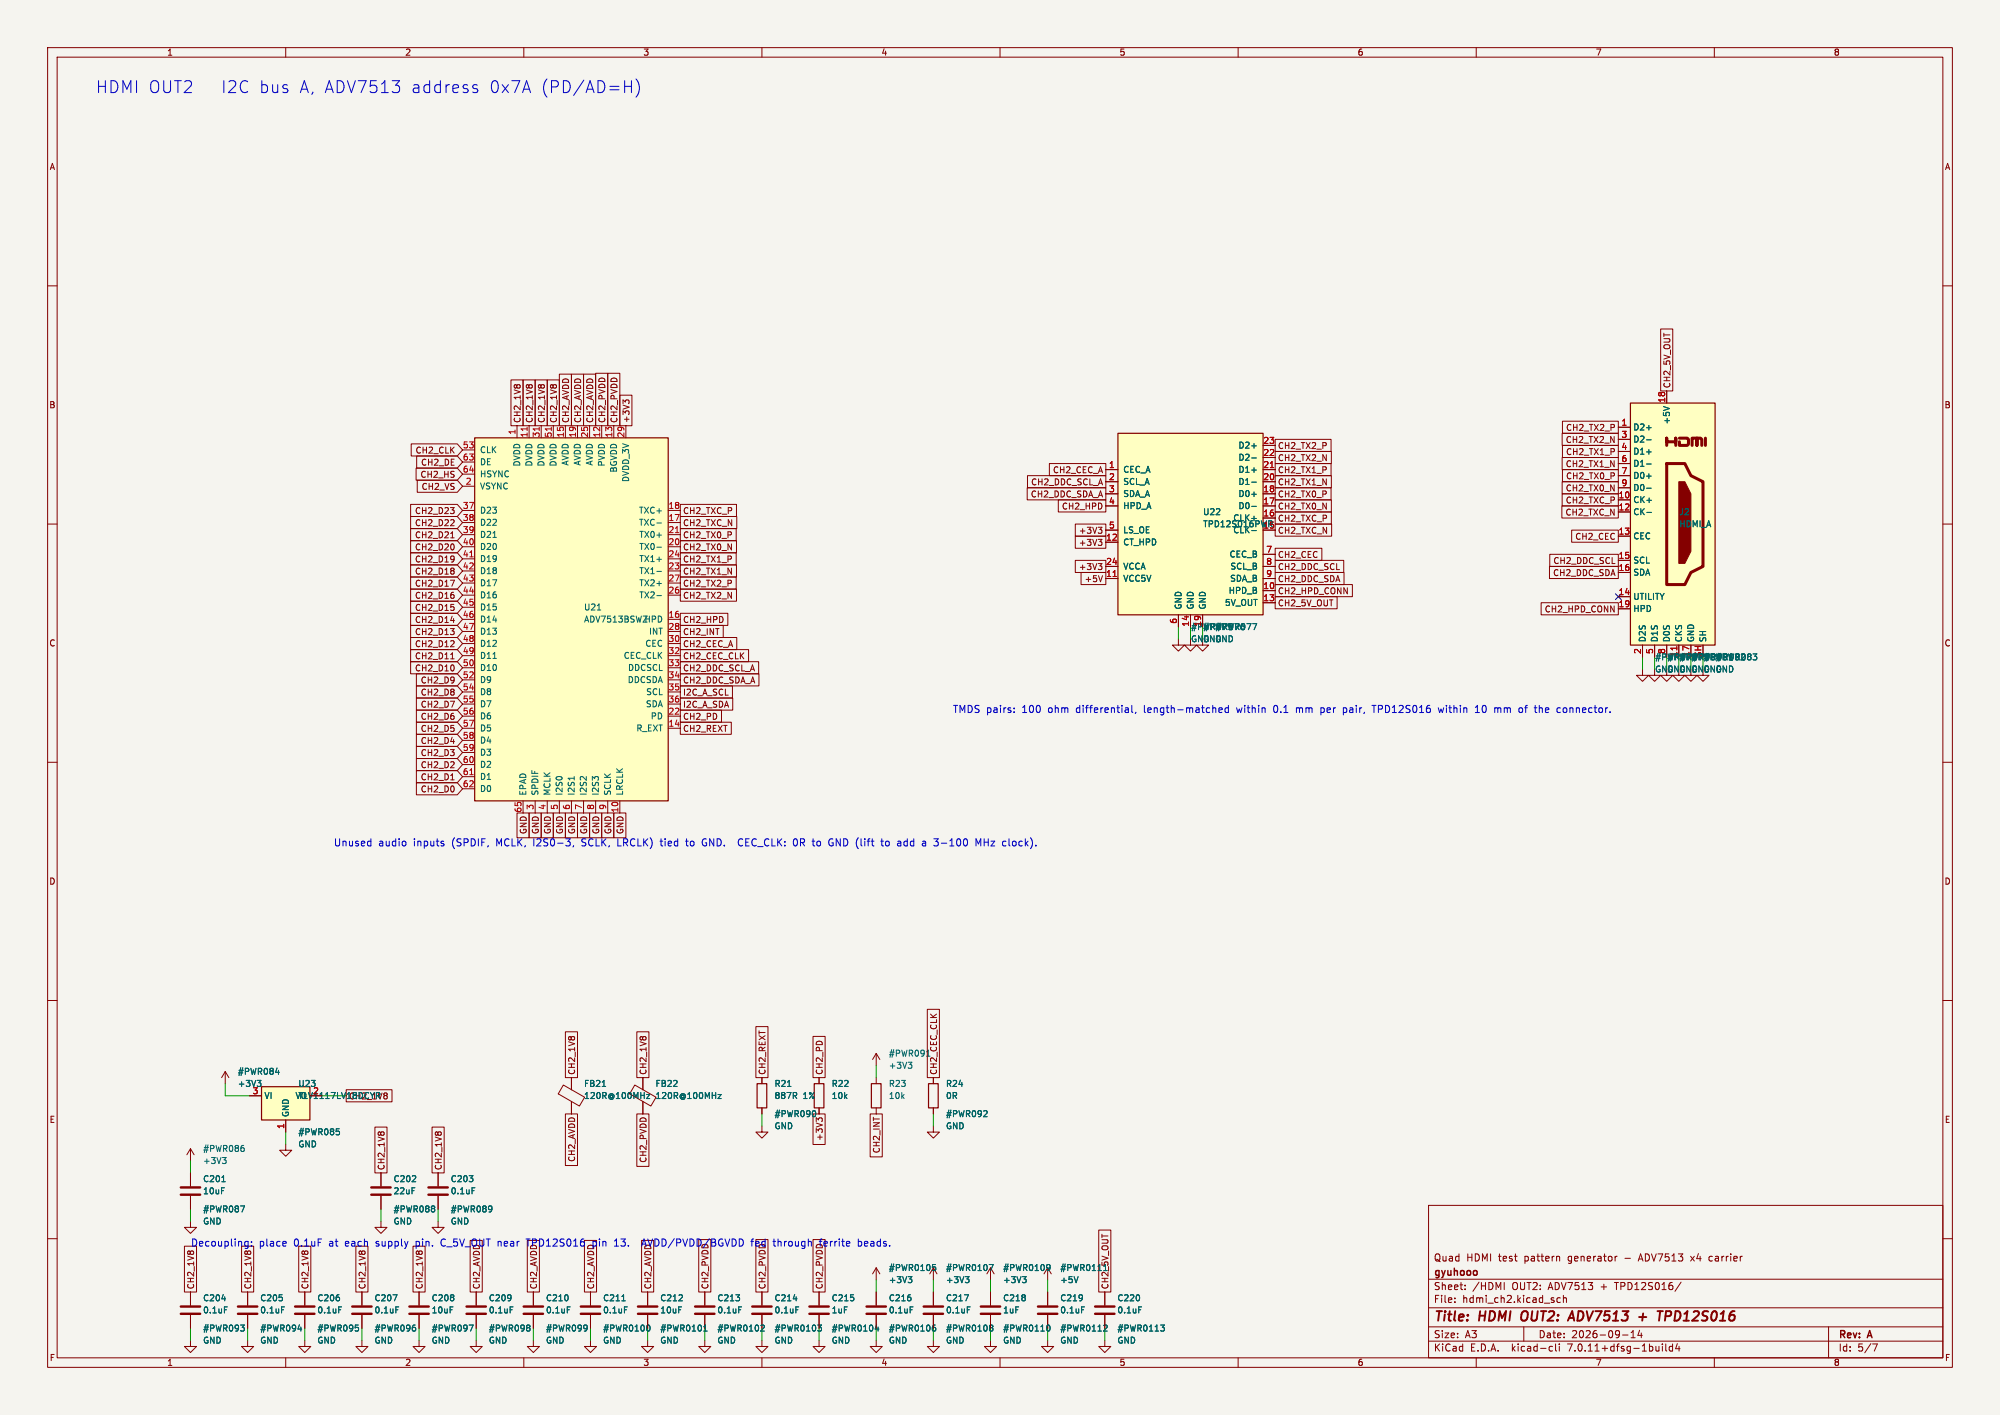
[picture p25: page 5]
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

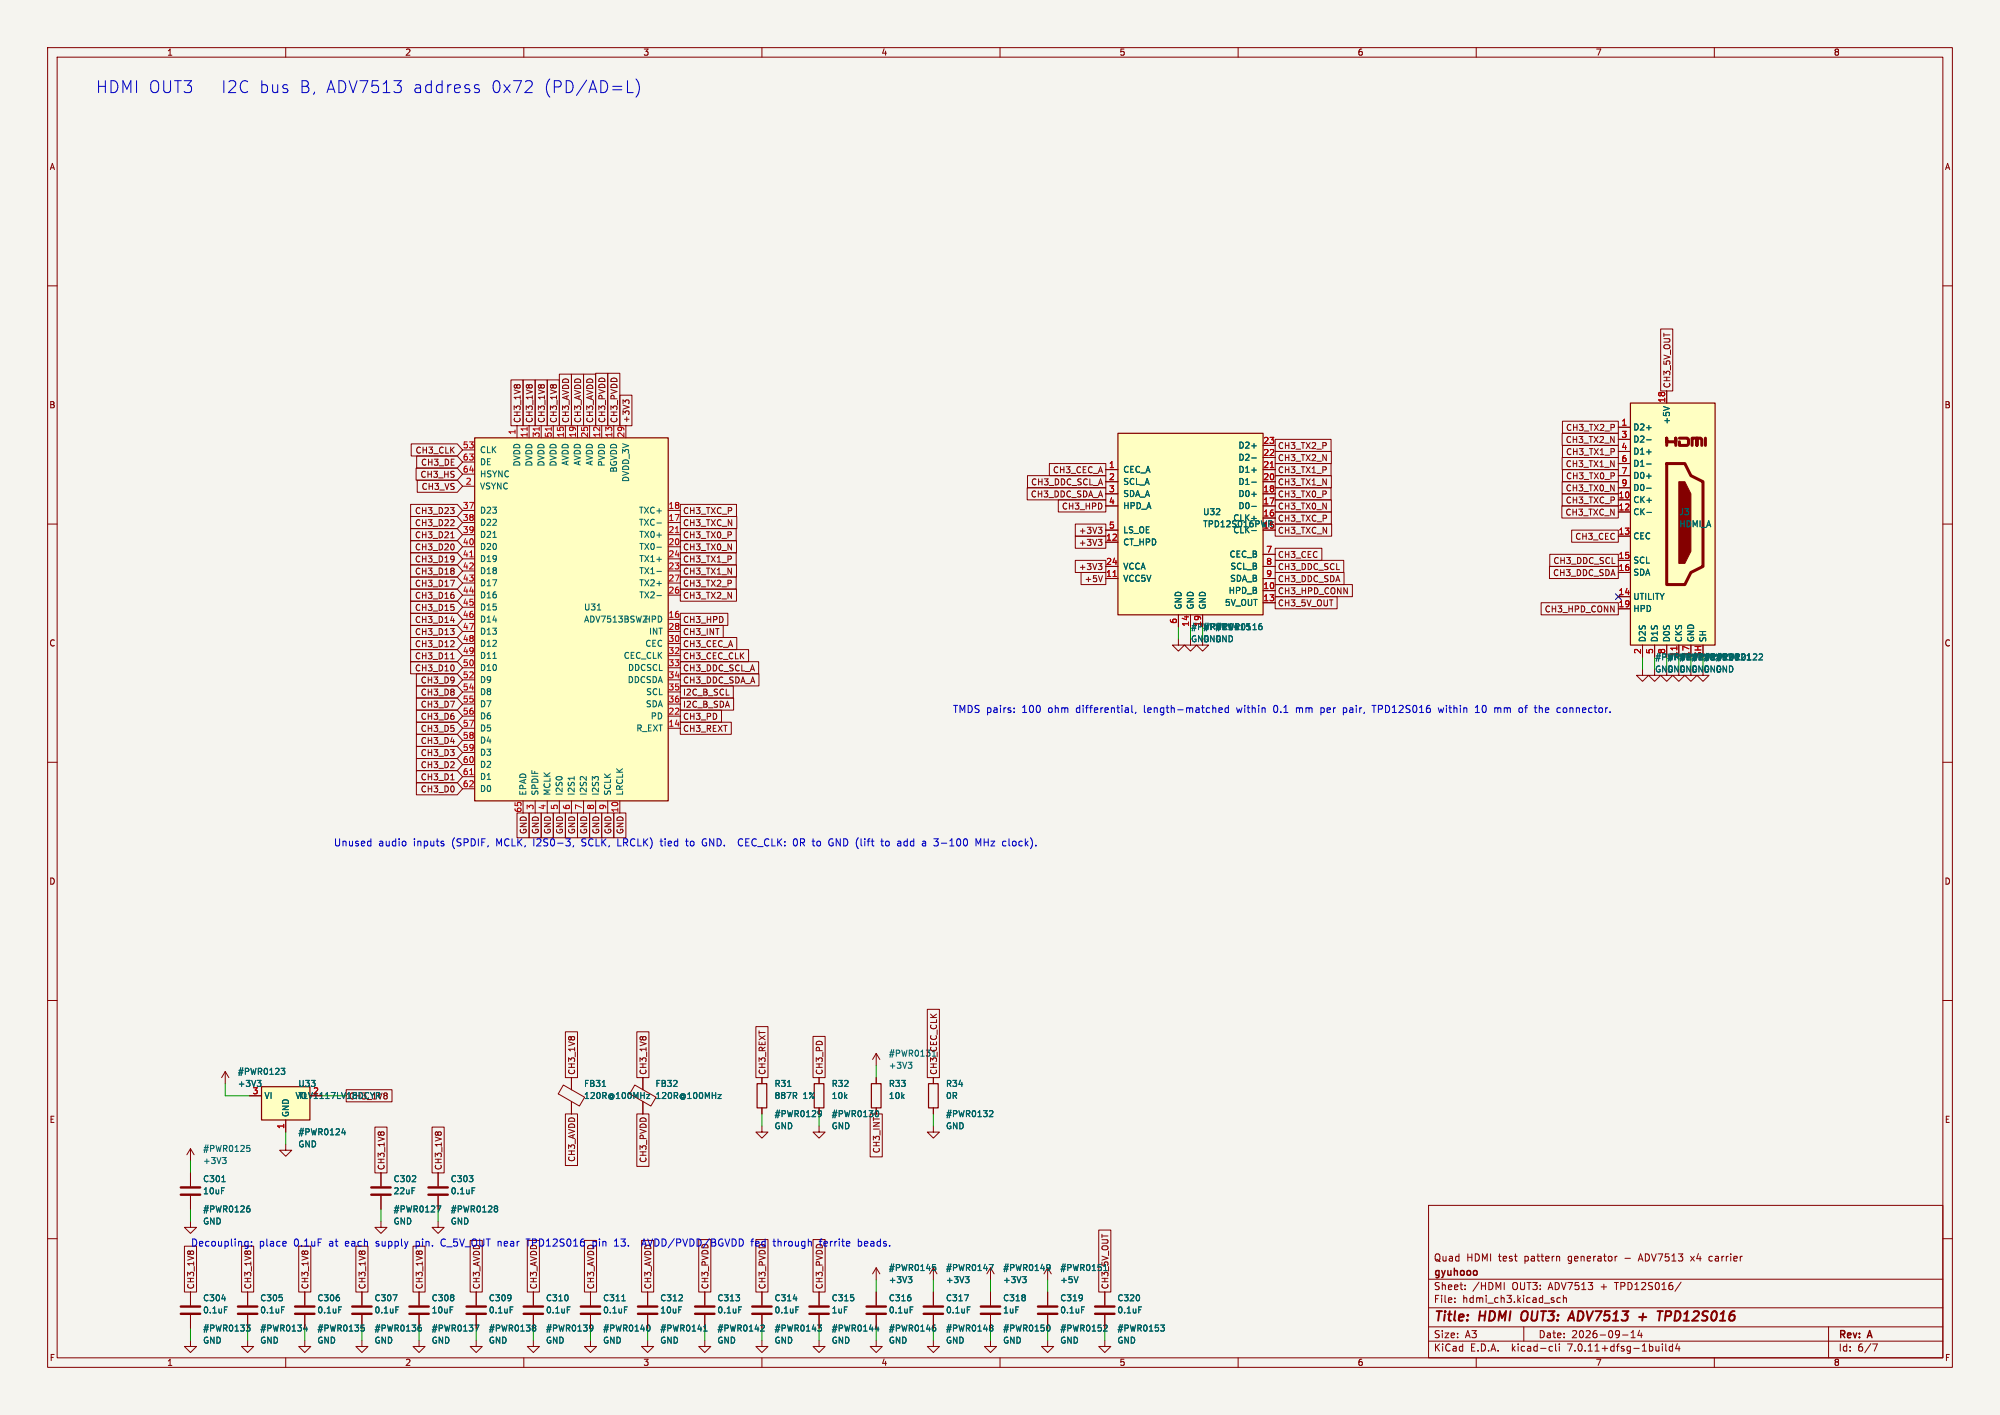
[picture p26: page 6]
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

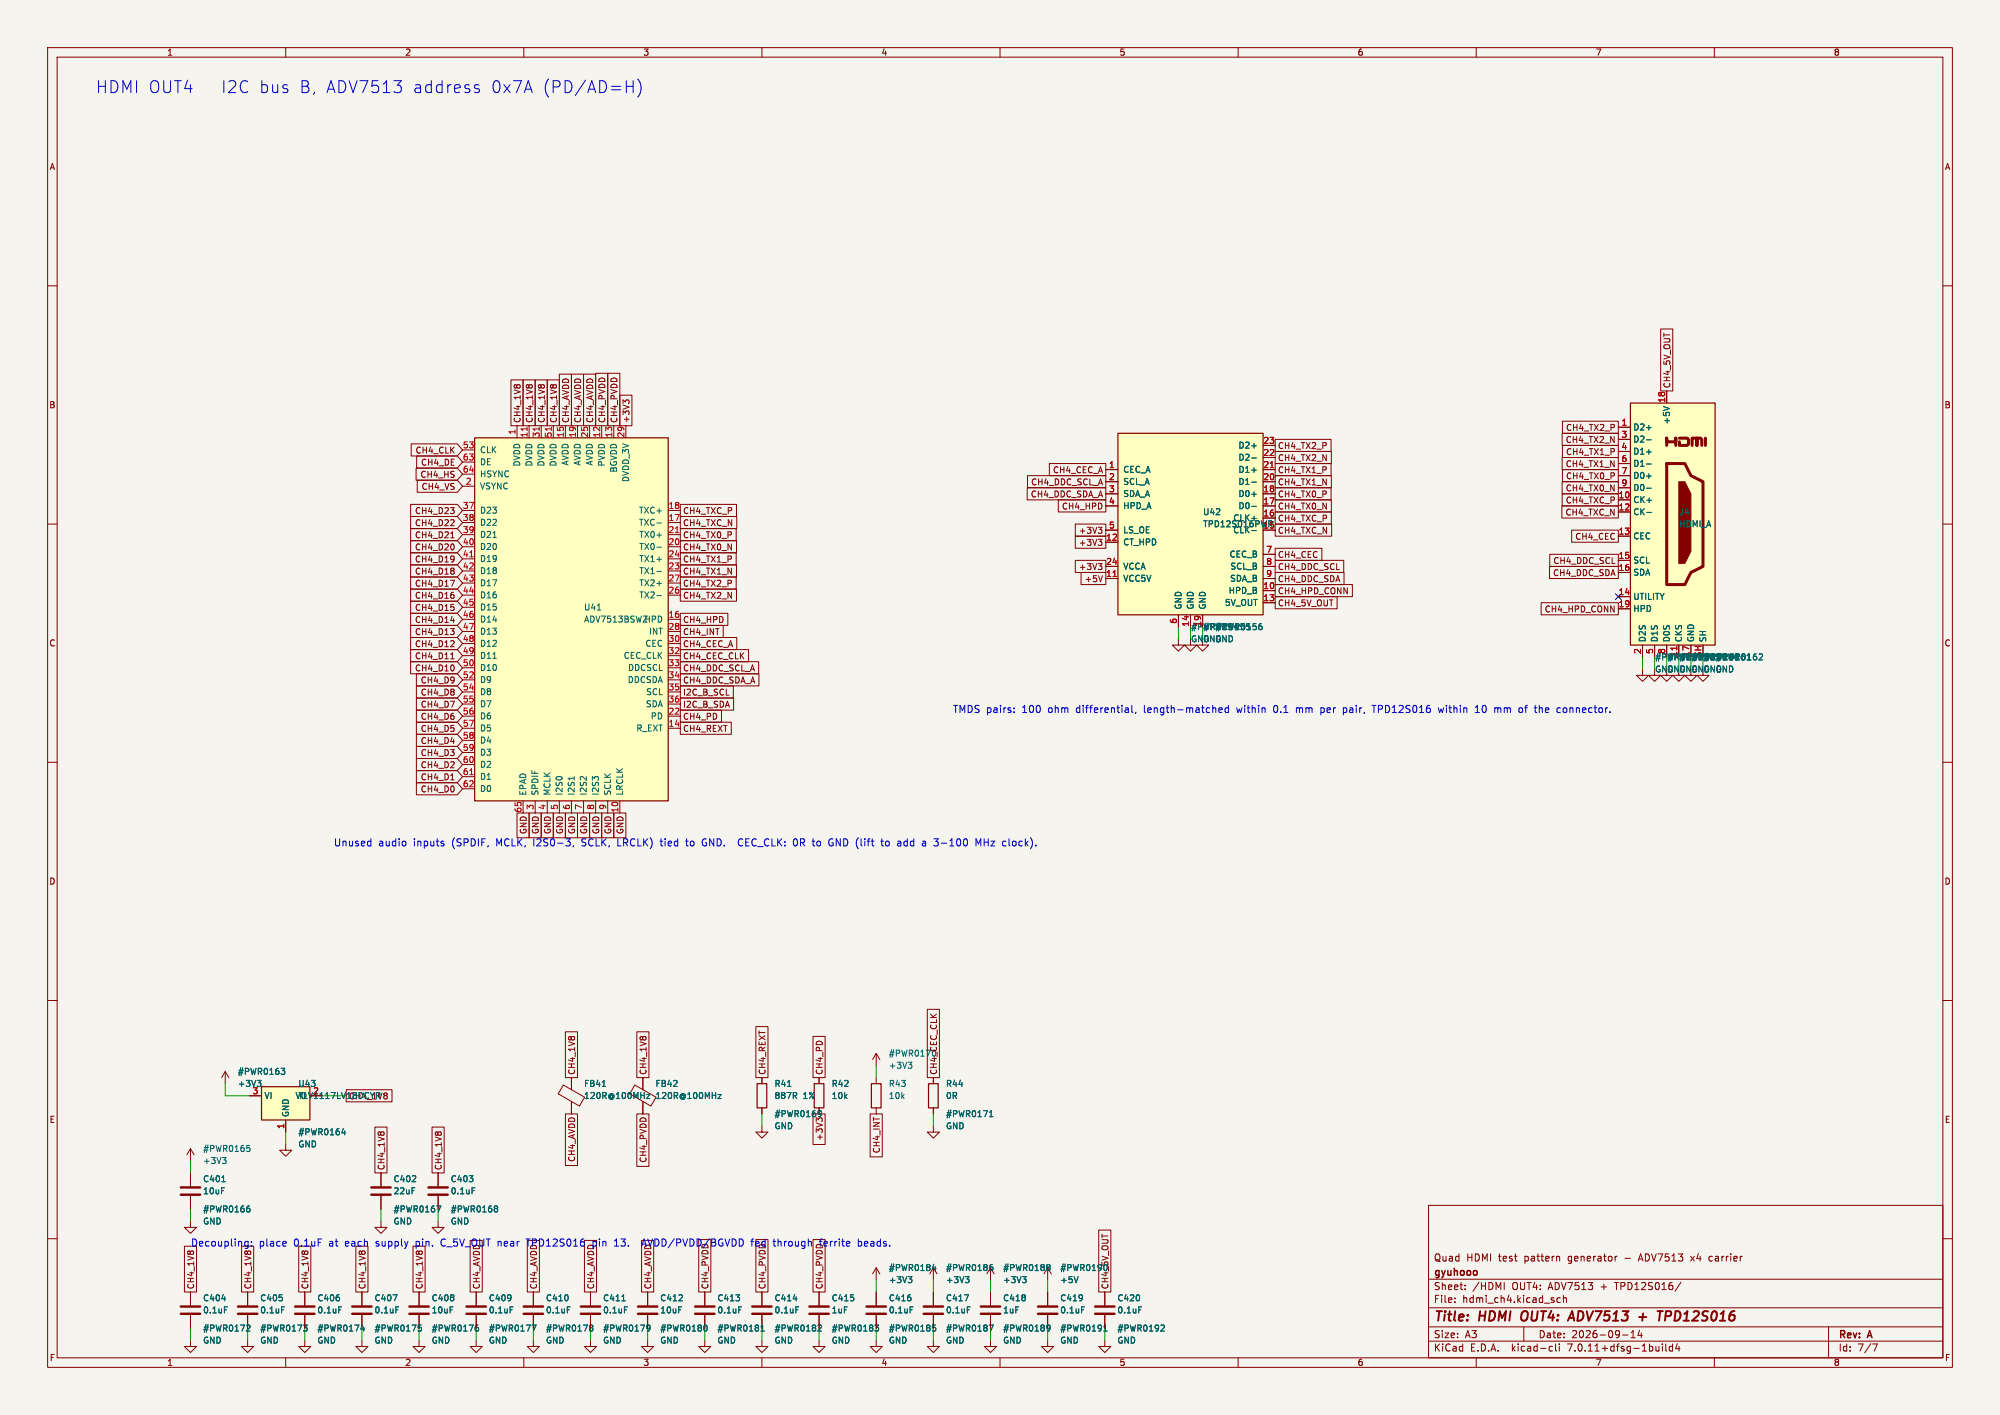
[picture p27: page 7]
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

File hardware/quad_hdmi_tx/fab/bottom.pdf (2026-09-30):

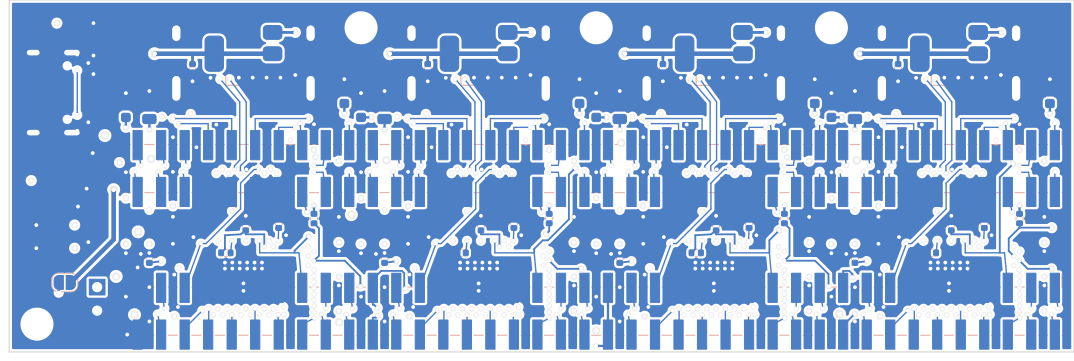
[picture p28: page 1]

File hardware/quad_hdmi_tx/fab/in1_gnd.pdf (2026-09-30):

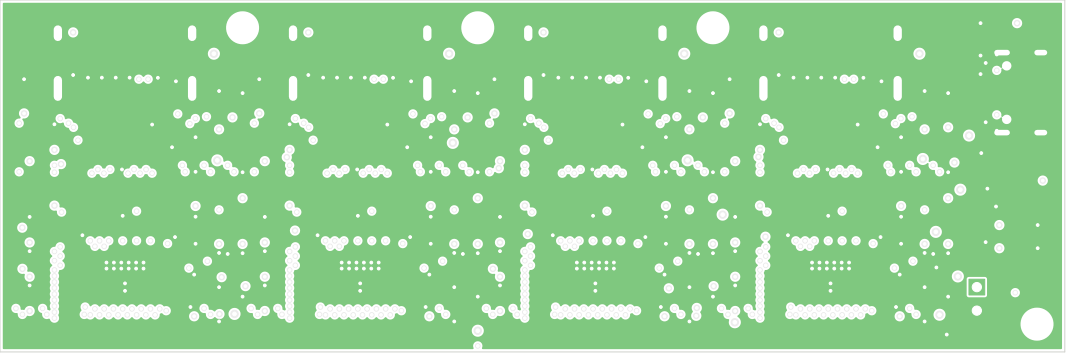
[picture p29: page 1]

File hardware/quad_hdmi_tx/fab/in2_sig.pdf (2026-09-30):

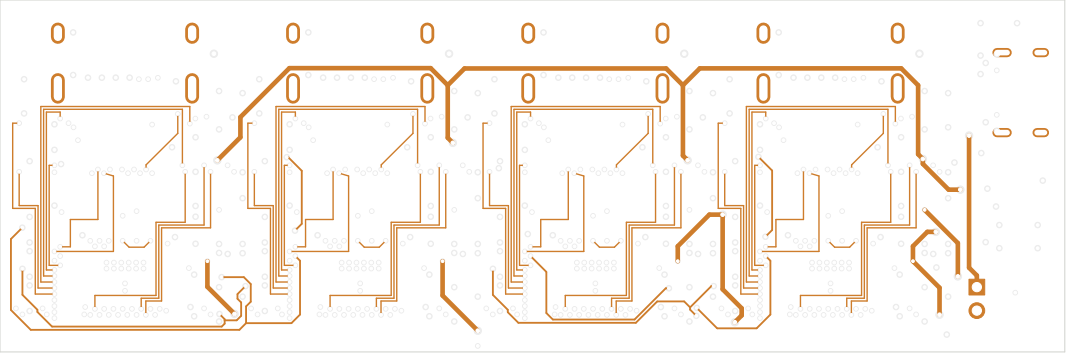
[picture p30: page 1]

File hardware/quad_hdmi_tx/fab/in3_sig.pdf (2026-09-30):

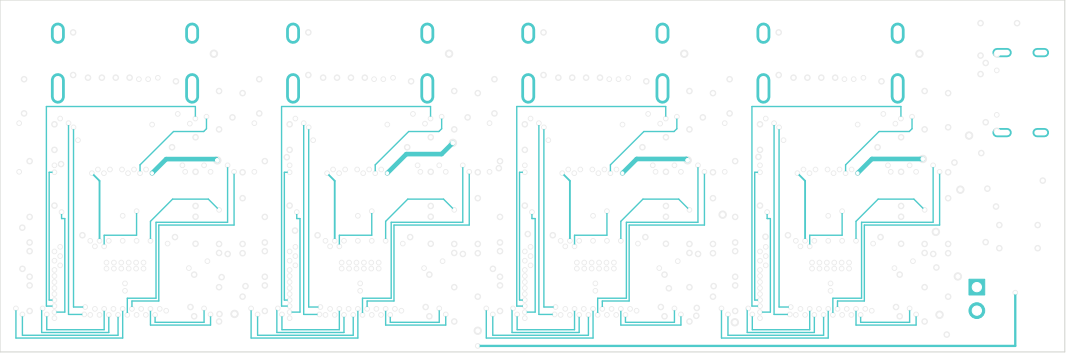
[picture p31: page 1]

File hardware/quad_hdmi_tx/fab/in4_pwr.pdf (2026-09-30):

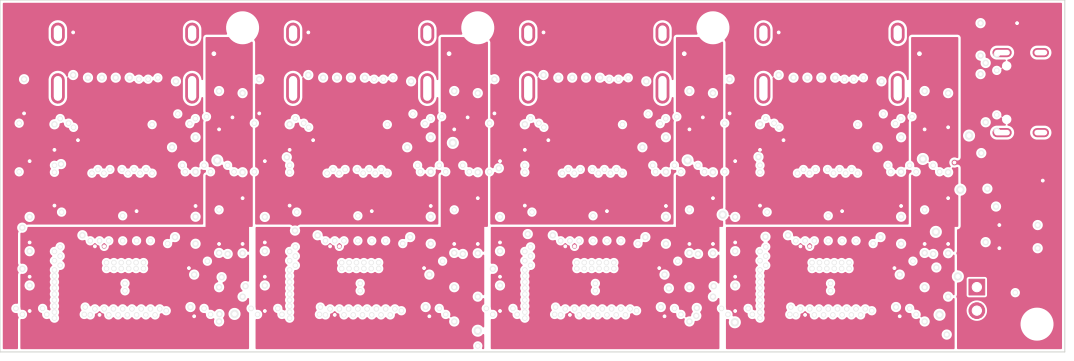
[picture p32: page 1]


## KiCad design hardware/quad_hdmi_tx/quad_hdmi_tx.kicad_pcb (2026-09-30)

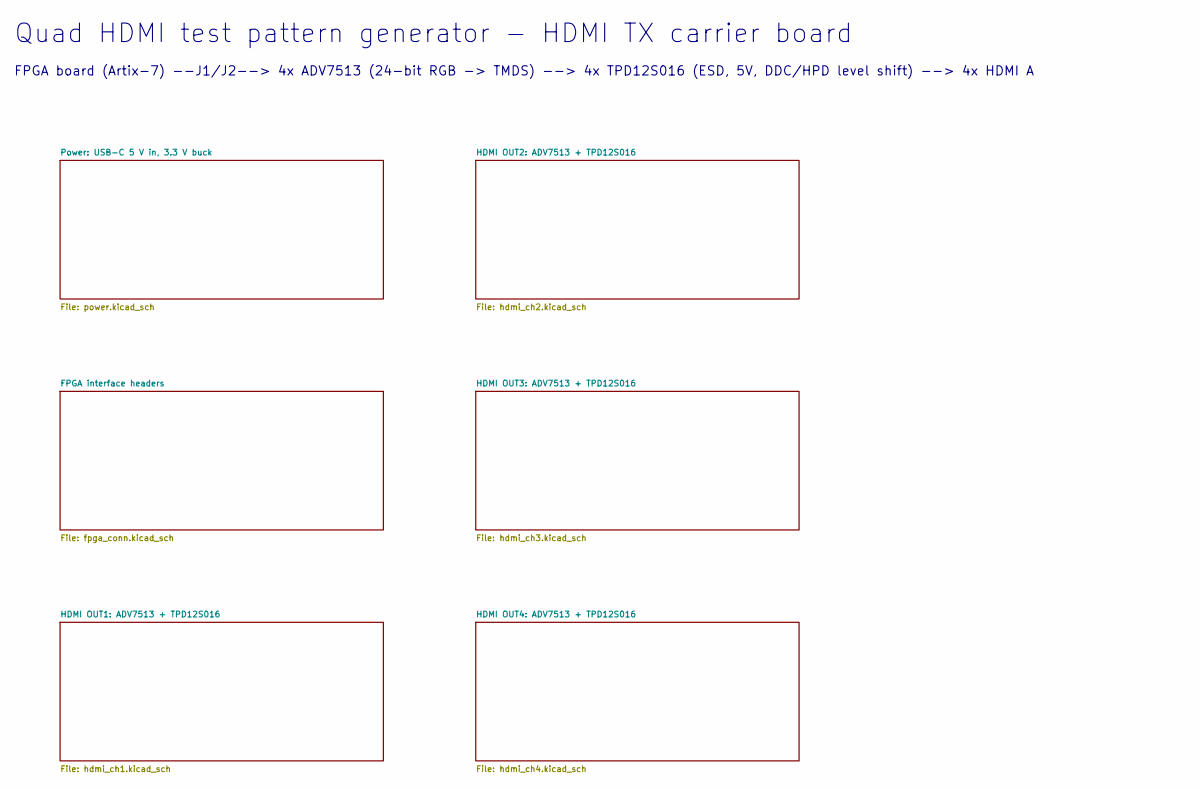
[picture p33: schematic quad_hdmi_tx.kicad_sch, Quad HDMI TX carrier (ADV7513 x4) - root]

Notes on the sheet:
Quad HDMI test pattern generator - HDMI TX carrier board
FPGA board (Artix-7) --J1/J2--> 4x ADV7513 (24-bit RGB -> TMDS) --> 4x TPD12S016 (ESD, 5V, DDC/HPD level shift) --> 4x HDMI A

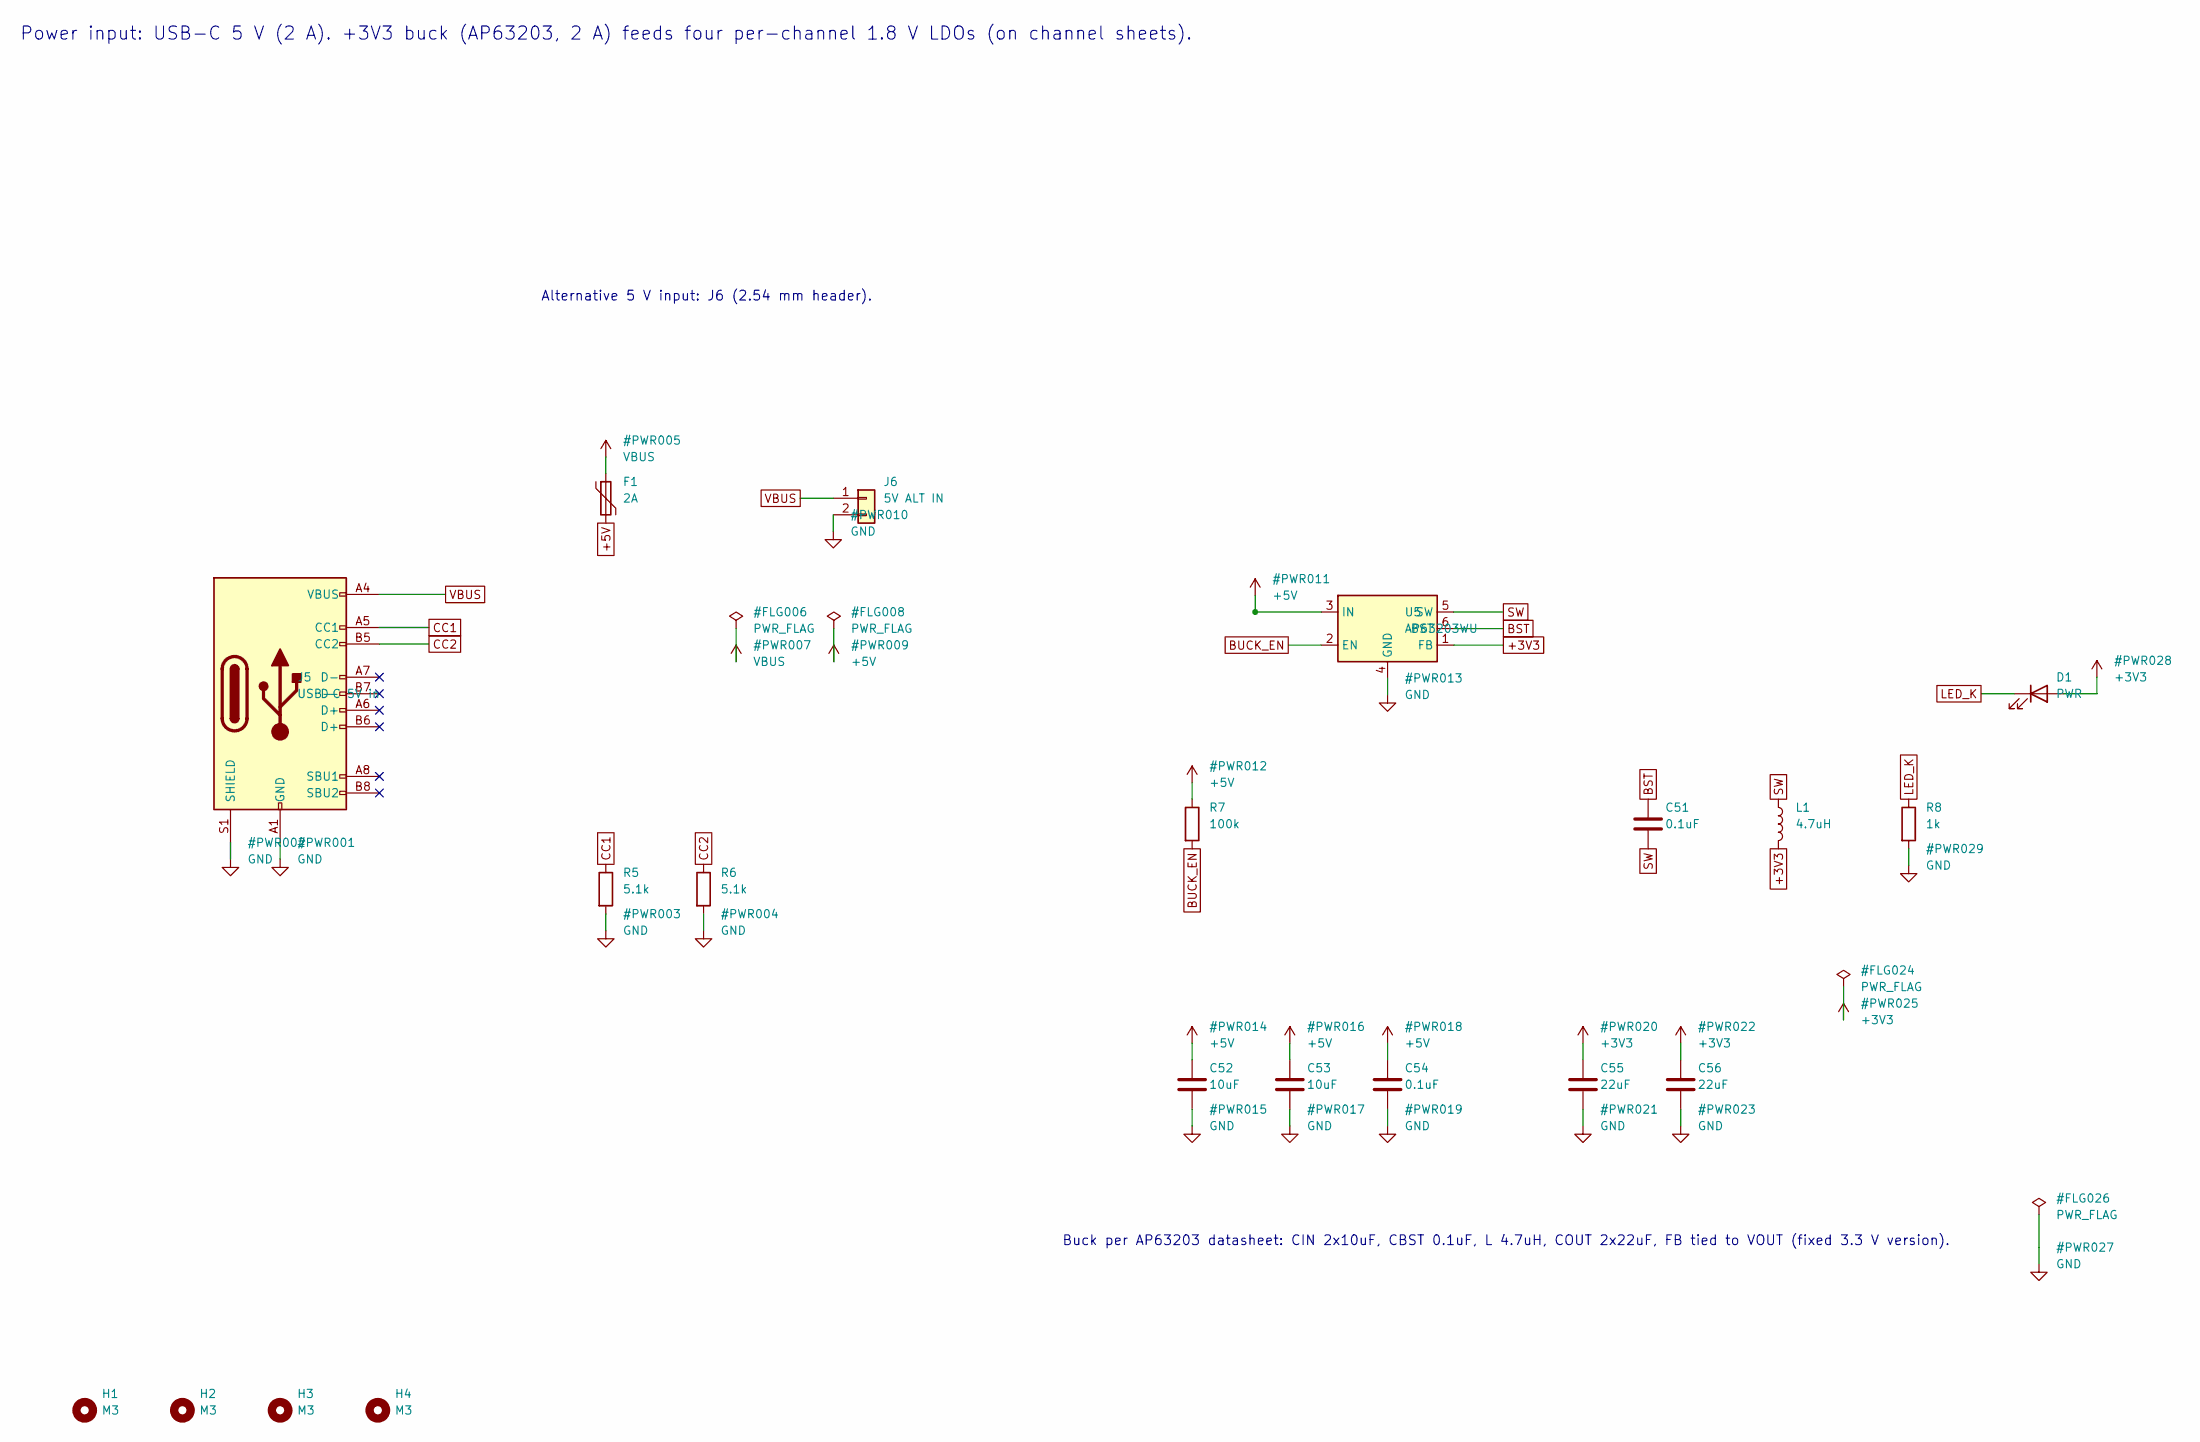
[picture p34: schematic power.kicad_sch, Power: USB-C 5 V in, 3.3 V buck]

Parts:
C51, C54: 0.1uF; C_0402_1005Metric; MPN GRM155R71C104KA88D
C52, C53: 10uF; C_0805_2012Metric; MPN GRM21BR61A106KE19L
C55, C56: 22uF; C_0805_2012Metric; MPN GRM21BR60J226ME39L
D1: PWR; LED_0603_1608Metric; MPN LTST-C193KGKT-5A
F1: 2A; Fuse_1206_3216Metric; MPN 1206L200/12SLYR
H1, H2, H3, H4: M3; MountingHole_3.2mm
J5: USB-C 5V in; USB_C_Receptacle_GCT_USB4105-xx-A_16P_TopMnt_Horizontal; MPN USB4105-GF-A
J6: 5V ALT IN; PinHeader_1x02_P2.54mm_Vertical
L1: 4.7uH; L_Taiyo-Yuden_NR-40xx; MPN NR4018T4R7M
R5, R6: 5.1k; R_0402_1005Metric; MPN RC0402FR-075K1L
R7: 100k; R_0402_1005Metric; MPN RC0402FR-07100KL
R8: 1k; R_0402_1005Metric; MPN RC0402FR-071KL
U5: AP63203WU; TSOT-23-6; MPN AP63203WU-7

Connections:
+3V3: C55.1, C56.1, D1.2 (A), L1.2, U5.1 (FB); also elsewhere on the board
+5V: C52.1, C53.1, C54.1, F1.2, R7.1, U5.3 (IN); also elsewhere on the board
BST: C51.1, U5.6 (BST)
BUCK_EN: R7.2, U5.2 (EN)
CC1: J5.A5 (CC1), R5.1
CC2: J5.B5 (CC2), R6.1
GND: C52.2, C53.2, C54.2, C55.2, C56.2, J5.A1 (GND), J5.A12 (GND), J5.B1 (GND), J5.B12 (GND), J5.S1 (SHIELD), J6.2, R5.2, R6.2, R8.2, U5.4 (GND); also elsewhere on the board
LED_K: D1.1 (K), R8.1
SW: C51.2, L1.1, U5.5 (SW)
VBUS: F1.1, J5.A4 (VBUS), J5.A9 (VBUS), J5.B4 (VBUS), J5.B9 (VBUS), J6.1

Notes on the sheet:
Power input: USB-C 5 V (2 A). +3V3 buck (AP63203, 2 A) feeds four per-channel 1.8 V LDOs (on channel sheets).
Alternative 5 V input: J6 (2.54 mm header).
Buck per AP63203 datasheet: CIN 2x10uF, CBST 0.1uF, L 4.7uH, COUT 2x22uF, FB tied to VOUT (fixed 3.3 V version).

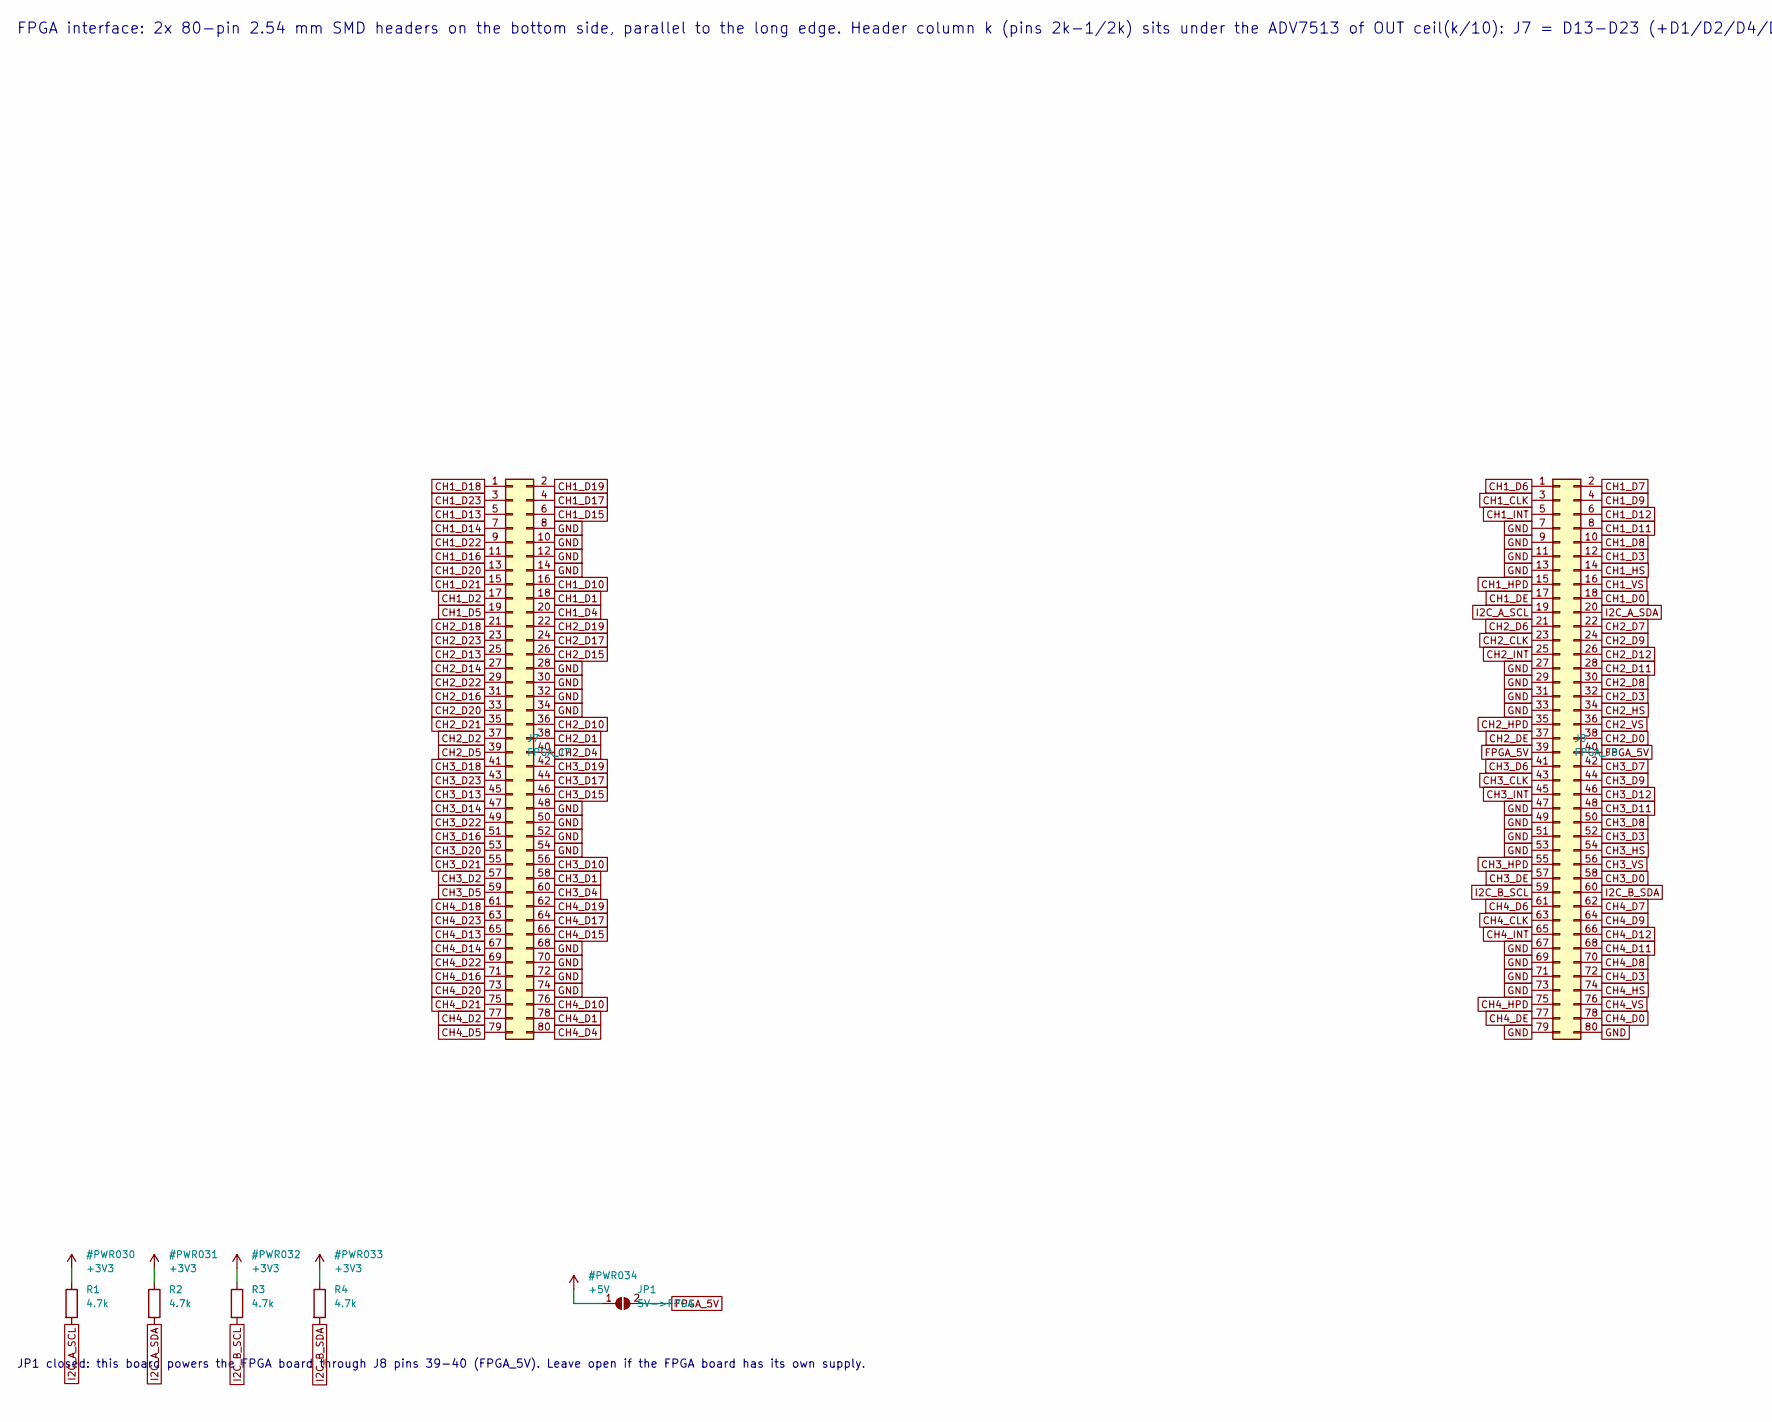
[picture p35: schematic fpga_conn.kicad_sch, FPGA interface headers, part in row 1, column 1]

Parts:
J7: FPGA_J7; PinHeader_2x40_P2.54mm_Vertical_SMD; MPN TSM-140-01-L-DV
J8: FPGA_J8; PinHeader_2x40_P2.54mm_Vertical_SMD; MPN TSM-140-01-L-DV
JP1: 5V->FPGA; SolderJumper-2_P1.3mm_Open_RoundedPad1.0x1.5mm
R1, R2, R3, R4: 4.7k; R_0402_1005Metric; MPN RC0402FR-074K7L

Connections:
+3V3: R1.1, R2.1, R3.1, R4.1; also elsewhere on the board
+5V: JP1.1 (A); also elsewhere on the board
CH1_CLK: J8.3; also elsewhere on the board
CH1_D0: J8.18; also elsewhere on the board
CH1_D1: J7.18; also elsewhere on the board
CH1_D2: J7.17; also elsewhere on the board
CH1_D3: J8.12; also elsewhere on the board
CH1_D4: J7.20; also elsewhere on the board
CH1_D5: J7.19; also elsewhere on the board
CH1_D6: J8.1; also elsewhere on the board
CH1_D7: J8.2; also elsewhere on the board
CH1_D8: J8.10; also elsewhere on the board
CH1_D9: J8.4; also elsewhere on the board
CH1_D10: J7.16; also elsewhere on the board
CH1_D11: J8.8; also elsewhere on the board
CH1_D12: J8.6; also elsewhere on the board
CH1_D13: J7.5; also elsewhere on the board
CH1_D14: J7.7; also elsewhere on the board
CH1_D15: J7.6; also elsewhere on the board
CH1_D16: J7.11; also elsewhere on the board
CH1_D17: J7.4; also elsewhere on the board
CH1_D18: J7.1; also elsewhere on the board
CH1_D19: J7.2; also elsewhere on the board
CH1_D20: J7.13; also elsewhere on the board
CH1_D21: J7.15; also elsewhere on the board
CH1_D22: J7.9; also elsewhere on the board
CH1_D23: J7.3; also elsewhere on the board
CH1_DE: J8.17; also elsewhere on the board
CH1_HPD: J8.15; also elsewhere on the board
CH1_HS: J8.14; also elsewhere on the board
CH1_INT: J8.5; also elsewhere on the board
CH1_VS: J8.16; also elsewhere on the board
CH2_CLK: J8.23; also elsewhere on the board
CH2_D0: J8.38; also elsewhere on the board
CH2_D1: J7.38; also elsewhere on the board
CH2_D2: J7.37; also elsewhere on the board
CH2_D3: J8.32; also elsewhere on the board
CH2_D4: J7.40; also elsewhere on the board
CH2_D5: J7.39; also elsewhere on the board
CH2_D6: J8.21; also elsewhere on the board
CH2_D7: J8.22; also elsewhere on the board
CH2_D8: J8.30; also elsewhere on the board
CH2_D9: J8.24; also elsewhere on the board
CH2_D10: J7.36; also elsewhere on the board
CH2_D11: J8.28; also elsewhere on the board
CH2_D12: J8.26; also elsewhere on the board
CH2_D13: J7.25; also elsewhere on the board
CH2_D14: J7.27; also elsewhere on the board
CH2_D15: J7.26; also elsewhere on the board
CH2_D16: J7.31; also elsewhere on the board
CH2_D17: J7.24; also elsewhere on the board
CH2_D18: J7.21; also elsewhere on the board
CH2_D19: J7.22; also elsewhere on the board
CH2_D20: J7.33; also elsewhere on the board
CH2_D21: J7.35; also elsewhere on the board
CH2_D22: J7.29; also elsewhere on the board
CH2_D23: J7.23; also elsewhere on the board
CH2_DE: J8.37; also elsewhere on the board
CH2_HPD: J8.35; also elsewhere on the board
CH2_HS: J8.34; also elsewhere on the board
CH2_INT: J8.25; also elsewhere on the board
CH2_VS: J8.36; also elsewhere on the board
CH3_CLK: J8.43; also elsewhere on the board
CH3_D0: J8.58; also elsewhere on the board
CH3_D1: J7.58; also elsewhere on the board
CH3_D2: J7.57; also elsewhere on the board
CH3_D3: J8.52; also elsewhere on the board
CH3_D4: J7.60; also elsewhere on the board
CH3_D5: J7.59; also elsewhere on the board
CH3_D6: J8.41; also elsewhere on the board
CH3_D7: J8.42; also elsewhere on the board
CH3_D8: J8.50; also elsewhere on the board
CH3_D9: J8.44; also elsewhere on the board
CH3_D10: J7.56; also elsewhere on the board
CH3_D11: J8.48; also elsewhere on the board
CH3_D12: J8.46; also elsewhere on the board
CH3_D13: J7.45; also elsewhere on the board
CH3_D14: J7.47; also elsewhere on the board
CH3_D15: J7.46; also elsewhere on the board
CH3_D16: J7.51; also elsewhere on the board
CH3_D17: J7.44; also elsewhere on the board
CH3_D18: J7.41; also elsewhere on the board
CH3_D19: J7.42; also elsewhere on the board
CH3_D20: J7.53; also elsewhere on the board
CH3_D21: J7.55; also elsewhere on the board
CH3_D22: J7.49; also elsewhere on the board
CH3_D23: J7.43; also elsewhere on the board
CH3_DE: J8.57; also elsewhere on the board
CH3_HPD: J8.55; also elsewhere on the board
CH3_HS: J8.54; also elsewhere on the board
CH3_INT: J8.45; also elsewhere on the board
CH3_VS: J8.56; also elsewhere on the board
CH4_CLK: J8.63; also elsewhere on the board
CH4_D0: J8.78; also elsewhere on the board
CH4_D1: J7.78; also elsewhere on the board
CH4_D2: J7.77; also elsewhere on the board
CH4_D3: J8.72; also elsewhere on the board
CH4_D4: J7.80; also elsewhere on the board
CH4_D5: J7.79; also elsewhere on the board
CH4_D6: J8.61; also elsewhere on the board
CH4_D7: J8.62; also elsewhere on the board
CH4_D8: J8.70; also elsewhere on the board
CH4_D9: J8.64; also elsewhere on the board
CH4_D10: J7.76; also elsewhere on the board
CH4_D11: J8.68; also elsewhere on the board
CH4_D12: J8.66; also elsewhere on the board
CH4_D13: J7.65; also elsewhere on the board
CH4_D14: J7.67; also elsewhere on the board
CH4_D15: J7.66; also elsewhere on the board
CH4_D16: J7.71; also elsewhere on the board
CH4_D17: J7.64; also elsewhere on the board
CH4_D18: J7.61; also elsewhere on the board
CH4_D19: J7.62; also elsewhere on the board
CH4_D20: J7.73; also elsewhere on the board
CH4_D21: J7.75; also elsewhere on the board
CH4_D22: J7.69; also elsewhere on the board
CH4_D23: J7.63; also elsewhere on the board
CH4_DE: J8.77; also elsewhere on the board
CH4_HPD: J8.75; also elsewhere on the board
CH4_HS: J8.74; also elsewhere on the board
CH4_INT: J8.65; also elsewhere on the board
CH4_VS: J8.76; also elsewhere on the board
FPGA_5V: J8.39, J8.40, JP1.2 (B)
GND: J7.8, J7.10, J7.12, J7.14, J7.28, J7.30, J7.32, J7.34, J7.48, J7.50, J7.52, J7.54, J7.68, J7.70, J7.72, J7.74, J8.7, J8.9, J8.11, J8.13, J8.27, J8.29, J8.31, J8.33, J8.47, J8.49, J8.51, J8.53, J8.67, J8.69, J8.71, J8.73, J8.79, J8.80; also elsewhere on the board
I2C_A_SCL: J8.19, R1.2; also elsewhere on the board
I2C_A_SDA: J8.20, R2.2; also elsewhere on the board
I2C_B_SCL: J8.59, R3.2; also elsewhere on the board
I2C_B_SDA: J8.60, R4.2; also elsewhere on the board

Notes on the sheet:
FPGA interface: 2x 80-pin 2.54 mm SMD headers on the bottom side, parallel to the long edge. Header column k (pins 2k-1/2k) sits under the ADV7513 of OUT ceil(k/10): J7 = D13-D23 (+D1/D2/D4/D5/D10), J8 = D0-D9/D11/D12/CLK/DE/HS/VS/HPD/INT (+I2C, 5V). 3.3 V LVCMOS, 148.5 MHz SDR: keep ribbon cables 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
JP1 closed: this board powers the FPGA board through J8 pins 39-40 (FPGA_5V). Leave open if the FPGA board has its own supply.

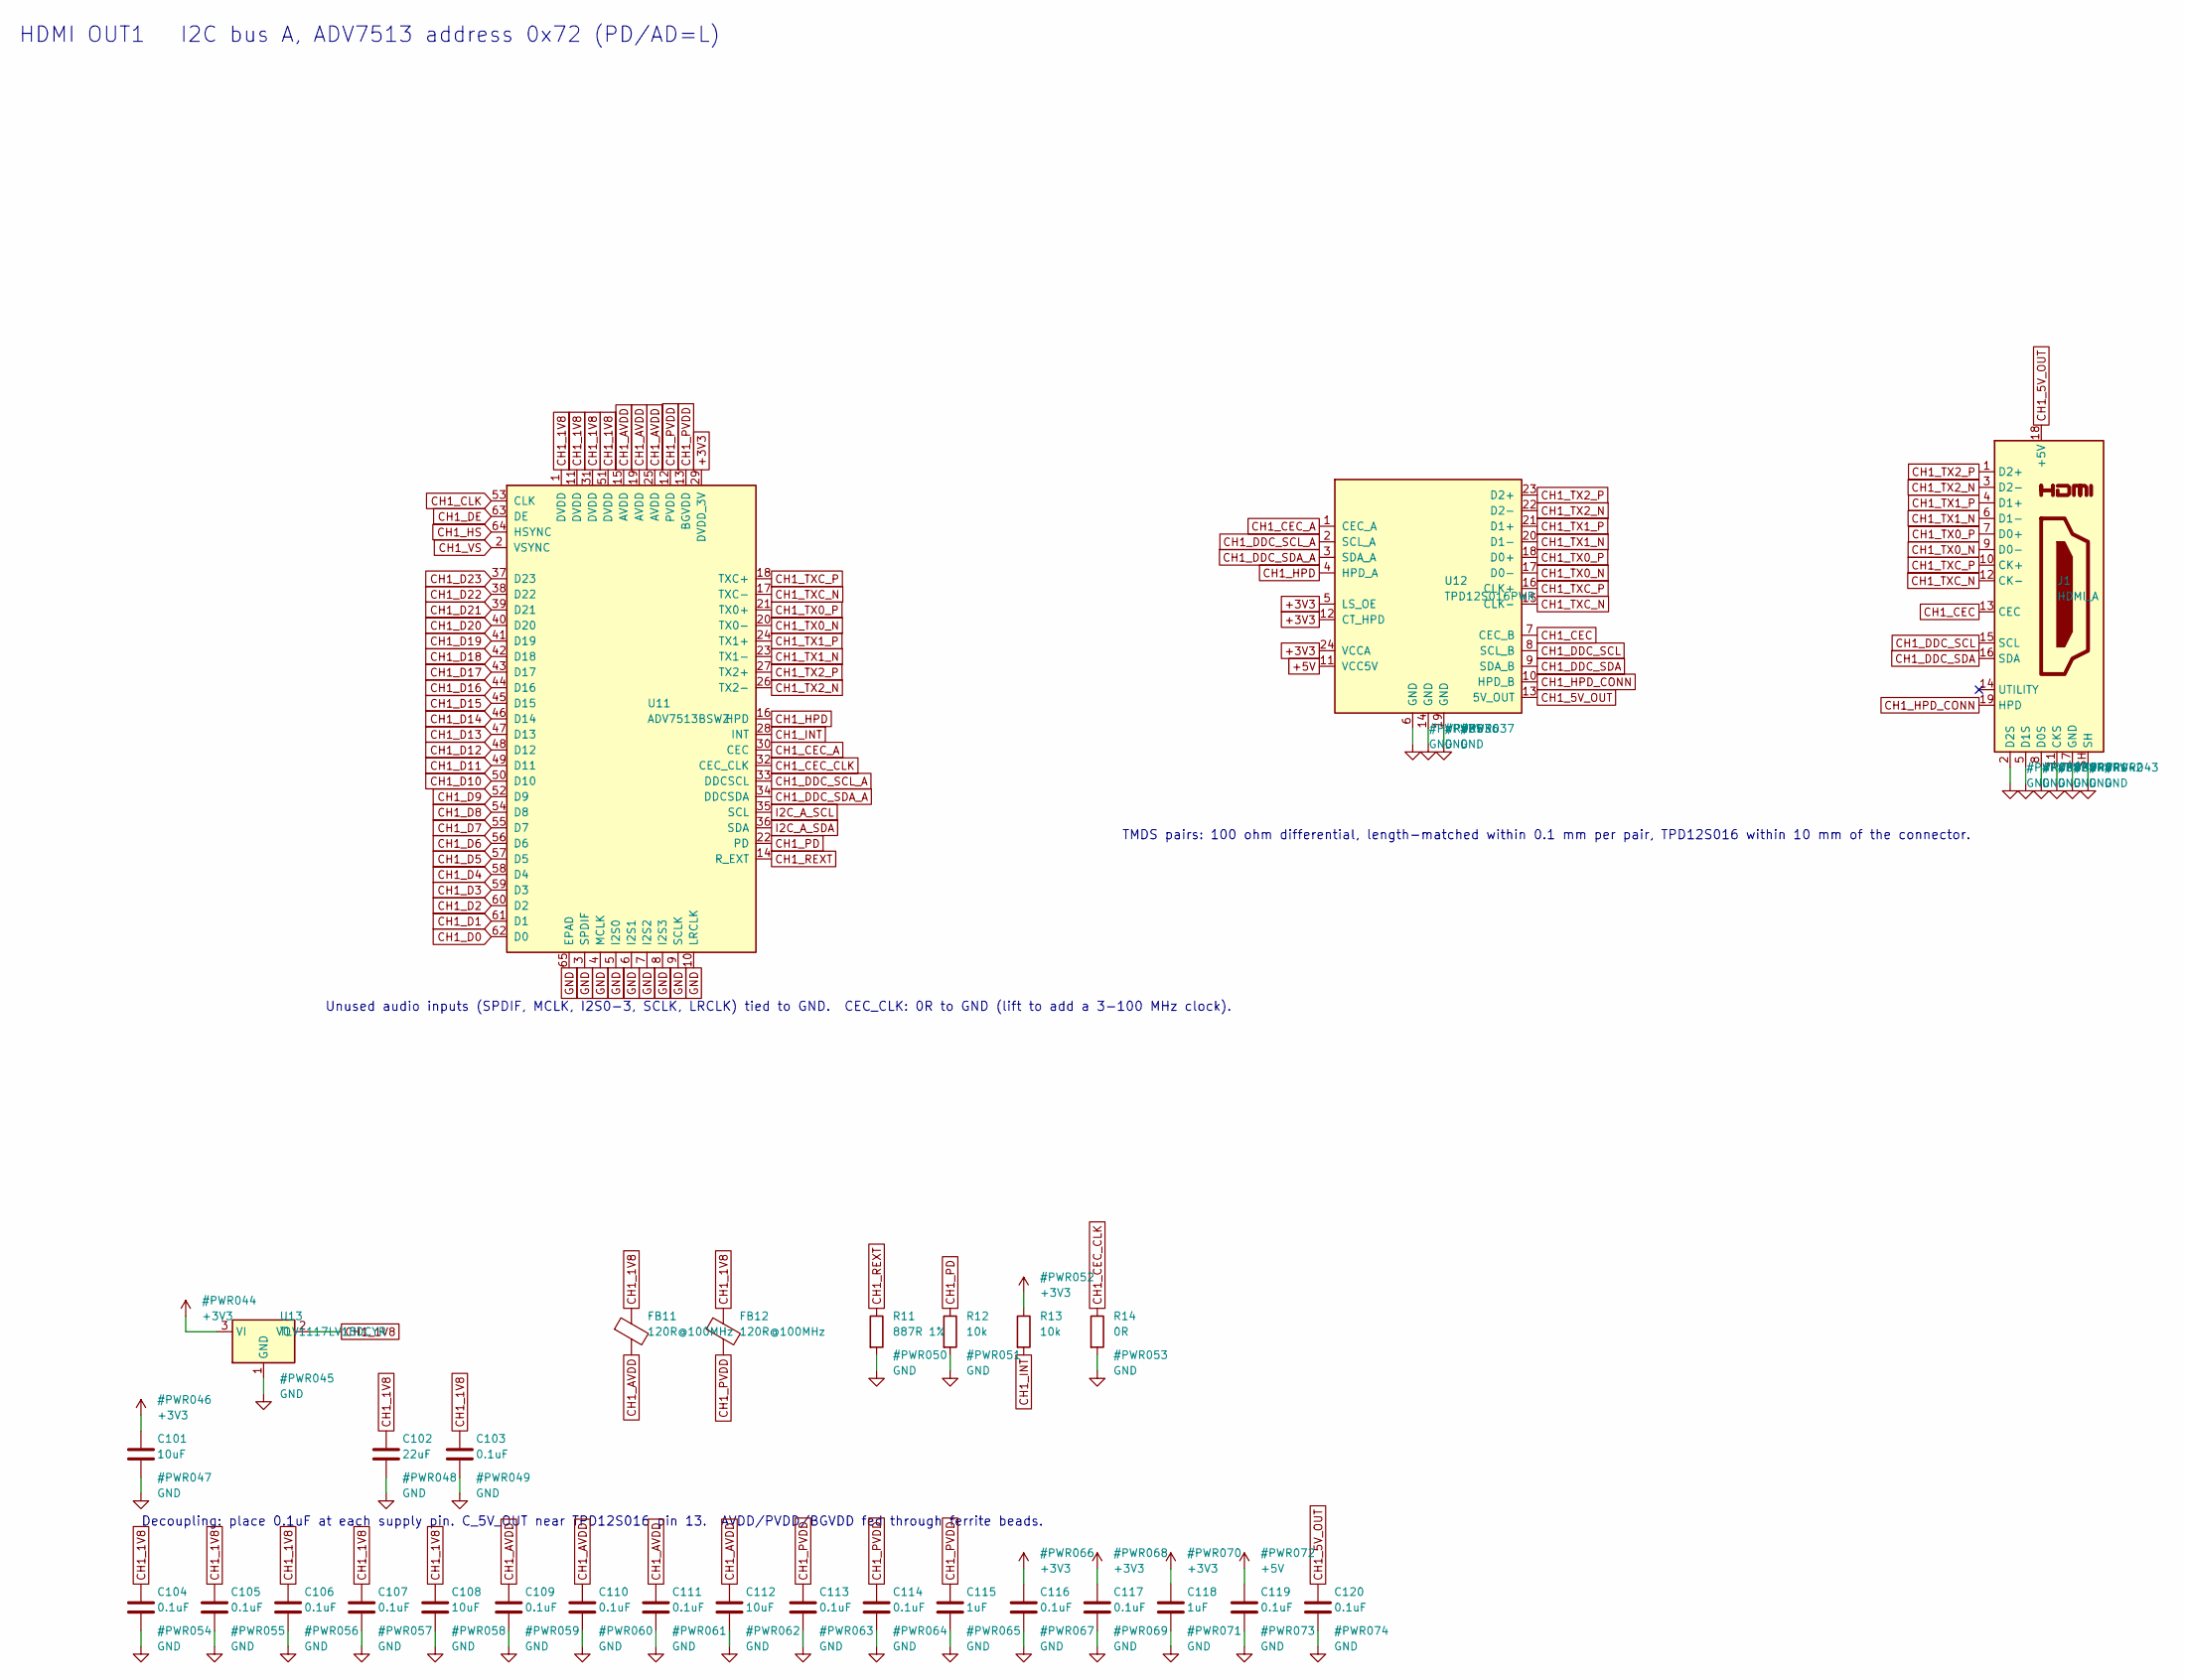
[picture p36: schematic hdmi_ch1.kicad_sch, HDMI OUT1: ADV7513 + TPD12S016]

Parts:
C101, C108, C112: 10uF; C_0603_1608Metric; MPN GRM188R60J106ME47D
C102: 22uF; C_0805_2012Metric; MPN GRM21BR60J226ME39L
C103, C104, C105, C106, C107, C109, C110, C111, C113, C114, C116, C117, C119, C120: 0.1uF; C_0402_1005Metric; MPN GRM155R71C104KA88D
C115, C118: 1uF; C_0603_1608Metric; MPN GRM188R61A105KA61D
FB11, FB12: 120R@100MHz; L_0603_1608Metric; MPN BLM18PG121SN1D
J1: HDMI_A; HDMI_A_Molex_208658-1001_Horizontal; MPN 208658-1001
R11: 887R 1%; R_0402_1005Metric; MPN RC0402FR-07887RL
R12, R13: 10k; R_0402_1005Metric; MPN RC0402FR-0710KL
R14: 0R; R_0402_1005Metric; MPN RC0402FR-070RL
U11: ADV7513BSWZ; LQFP-64-1EP_10x10mm_P0.5mm_EP5x5mm; MPN ADV7513BSWZ
U12: TPD12S016PWR; TSSOP-24_4.4x7.8mm_P0.65mm; MPN TPD12S016PWR
U13: TLV1117LV18DCYR; SOT-223-3_TabPin2; MPN TLV1117LV18DCYR

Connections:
+3V3: C101.1, C116.1, C117.1, C118.1, R13.1, U11.29 (DVDD_3V), U12.5 (LS_OE), U12.12 (CT_HPD), U12.24 (VCCA), U13.3 (VI); also elsewhere on the board
+5V: C119.1, U12.11 (VCC5V); also elsewhere on the board
CH1_1V8: C102.1, C103.1, C104.1, C105.1, C106.1, C107.1, C108.1, FB11.1, FB12.1, U11.1 (DVDD), U11.11 (DVDD), U11.31 (DVDD), U11.51 (DVDD), U13.2 (VO)
CH1_5V_OUT: C120.1, J1.18 (+5V), U12.13 (5V_OUT)
CH1_AVDD: C109.1, C110.1, C111.1, C112.1, FB11.2, U11.15 (AVDD), U11.19 (AVDD), U11.25 (AVDD)
CH1_CEC: J1.13 (CEC), U12.7 (CEC_B)
CH1_CEC_A: U11.30 (CEC), U12.1 (CEC_A)
CH1_CEC_CLK: R14.1, U11.32 (CEC_CLK)
CH1_CLK: U11.53 (CLK); also elsewhere on the board
CH1_D0: U11.62 (D0); also elsewhere on the board
CH1_D1: U11.61 (D1); also elsewhere on the board
CH1_D2: U11.60 (D2); also elsewhere on the board
CH1_D3: U11.59 (D3); also elsewhere on the board
CH1_D4: U11.58 (D4); also elsewhere on the board
CH1_D5: U11.57 (D5); also elsewhere on the board
CH1_D6: U11.56 (D6); also elsewhere on the board
CH1_D7: U11.55 (D7); also elsewhere on the board
CH1_D8: U11.54 (D8); also elsewhere on the board
CH1_D9: U11.52 (D9); also elsewhere on the board
CH1_D10: U11.50 (D10); also elsewhere on the board
CH1_D11: U11.49 (D11); also elsewhere on the board
CH1_D12: U11.48 (D12); also elsewhere on the board
CH1_D13: U11.47 (D13); also elsewhere on the board
CH1_D14: U11.46 (D14); also elsewhere on the board
CH1_D15: U11.45 (D15); also elsewhere on the board
CH1_D16: U11.44 (D16); also elsewhere on the board
CH1_D17: U11.43 (D17); also elsewhere on the board
CH1_D18: U11.42 (D18); also elsewhere on the board
CH1_D19: U11.41 (D19); also elsewhere on the board
CH1_D20: U11.40 (D20); also elsewhere on the board
CH1_D21: U11.39 (D21); also elsewhere on the board
CH1_D22: U11.38 (D22); also elsewhere on the board
CH1_D23: U11.37 (D23); also elsewhere on the board
CH1_DDC_SCL: J1.15 (SCL), U12.8 (SCL_B)
CH1_DDC_SCL_A: U11.33 (DDCSCL), U12.2 (SCL_A)
CH1_DDC_SDA: J1.16 (SDA), U12.9 (SDA_B)
CH1_DDC_SDA_A: U11.34 (DDCSDA), U12.3 (SDA_A)
CH1_DE: U11.63 (DE); also elsewhere on the board
CH1_HPD: U11.16 (HPD), U12.4 (HPD_A); also elsewhere on the board
CH1_HPD_CONN: J1.19 (HPD), U12.10 (HPD_B)
CH1_HS: U11.64 (HSYNC); also elsewhere on the board
CH1_INT: R13.2, U11.28 (INT); also elsewhere on the board
CH1_PD: R12.1, U11.22 (PD)
CH1_PVDD: C113.1, C114.1, C115.1, FB12.2, U11.12 (PVDD), U11.13 (BGVDD)
CH1_REXT: R11.1, U11.14 (R_EXT)
CH1_TX0_N: J1.9 (D0-), U11.20 (TX0-), U12.17 (D0-)
CH1_TX0_P: J1.7 (D0+), U11.21 (TX0+), U12.18 (D0+)
CH1_TX1_N: J1.6 (D1-), U11.23 (TX1-), U12.20 (D1-)
CH1_TX1_P: J1.4 (D1+), U11.24 (TX1+), U12.21 (D1+)
CH1_TX2_N: J1.3 (D2-), U11.26 (TX2-), U12.22 (D2-)
CH1_TX2_P: J1.1 (D2+), U11.27 (TX2+), U12.23 (D2+)
CH1_TXC_N: J1.12 (CK-), U11.17 (TXC-), U12.15 (CLK-)
CH1_TXC_P: J1.10 (CK+), U11.18 (TXC+), U12.16 (CLK+)
CH1_VS: U11.2 (VSYNC); also elsewhere on the board
GND: C101.2, C102.2, C103.2, C104.2, C105.2, C106.2, C107.2, C108.2, C109.2, C110.2, C111.2, C112.2, C113.2, C114.2, C115.2, C116.2, C117.2, C118.2, C119.2, C120.2, J1.2 (D2S), J1.5 (D1S), J1.8 (D0S), J1.11 (CKS), J1.17 (GND), J1.SH, R11.2, R12.2, R14.2, U11.3 (SPDIF), U11.4 (MCLK), U11.5 (I2S0), U11.6 (I2S1), U11.7 (I2S2), U11.8 (I2S3), U11.9 (SCLK), U11.10 (LRCLK), U11.65 (EPAD), U12.6 (GND), U12.14 (GND), U12.19 (GND), U13.1 (GND); also elsewhere on the board
I2C_A_SCL: U11.35 (SCL); also elsewhere on the board
I2C_A_SDA: U11.36 (SDA); also elsewhere on the board

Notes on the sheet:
HDMI OUT1 I2C bus A, ADV7513 address 0x72 (PD/AD=L)
Unused audio inputs (SPDIF, MCLK, I2S0-3, SCLK, LRCLK) tied to GND. CEC_CLK: 0R to GND (lift to add a 3-100 MHz clock).
Decoupling: place 0.1uF at each supply pin. C_5V_OUT near TPD12S016 pin 13. AVDD/PVDD/BGVDD fed through ferrite beads.
TMDS pairs: 100 ohm differential, length-matched within 0.1 mm per pair, TPD12S016 within 10 mm of the connector.

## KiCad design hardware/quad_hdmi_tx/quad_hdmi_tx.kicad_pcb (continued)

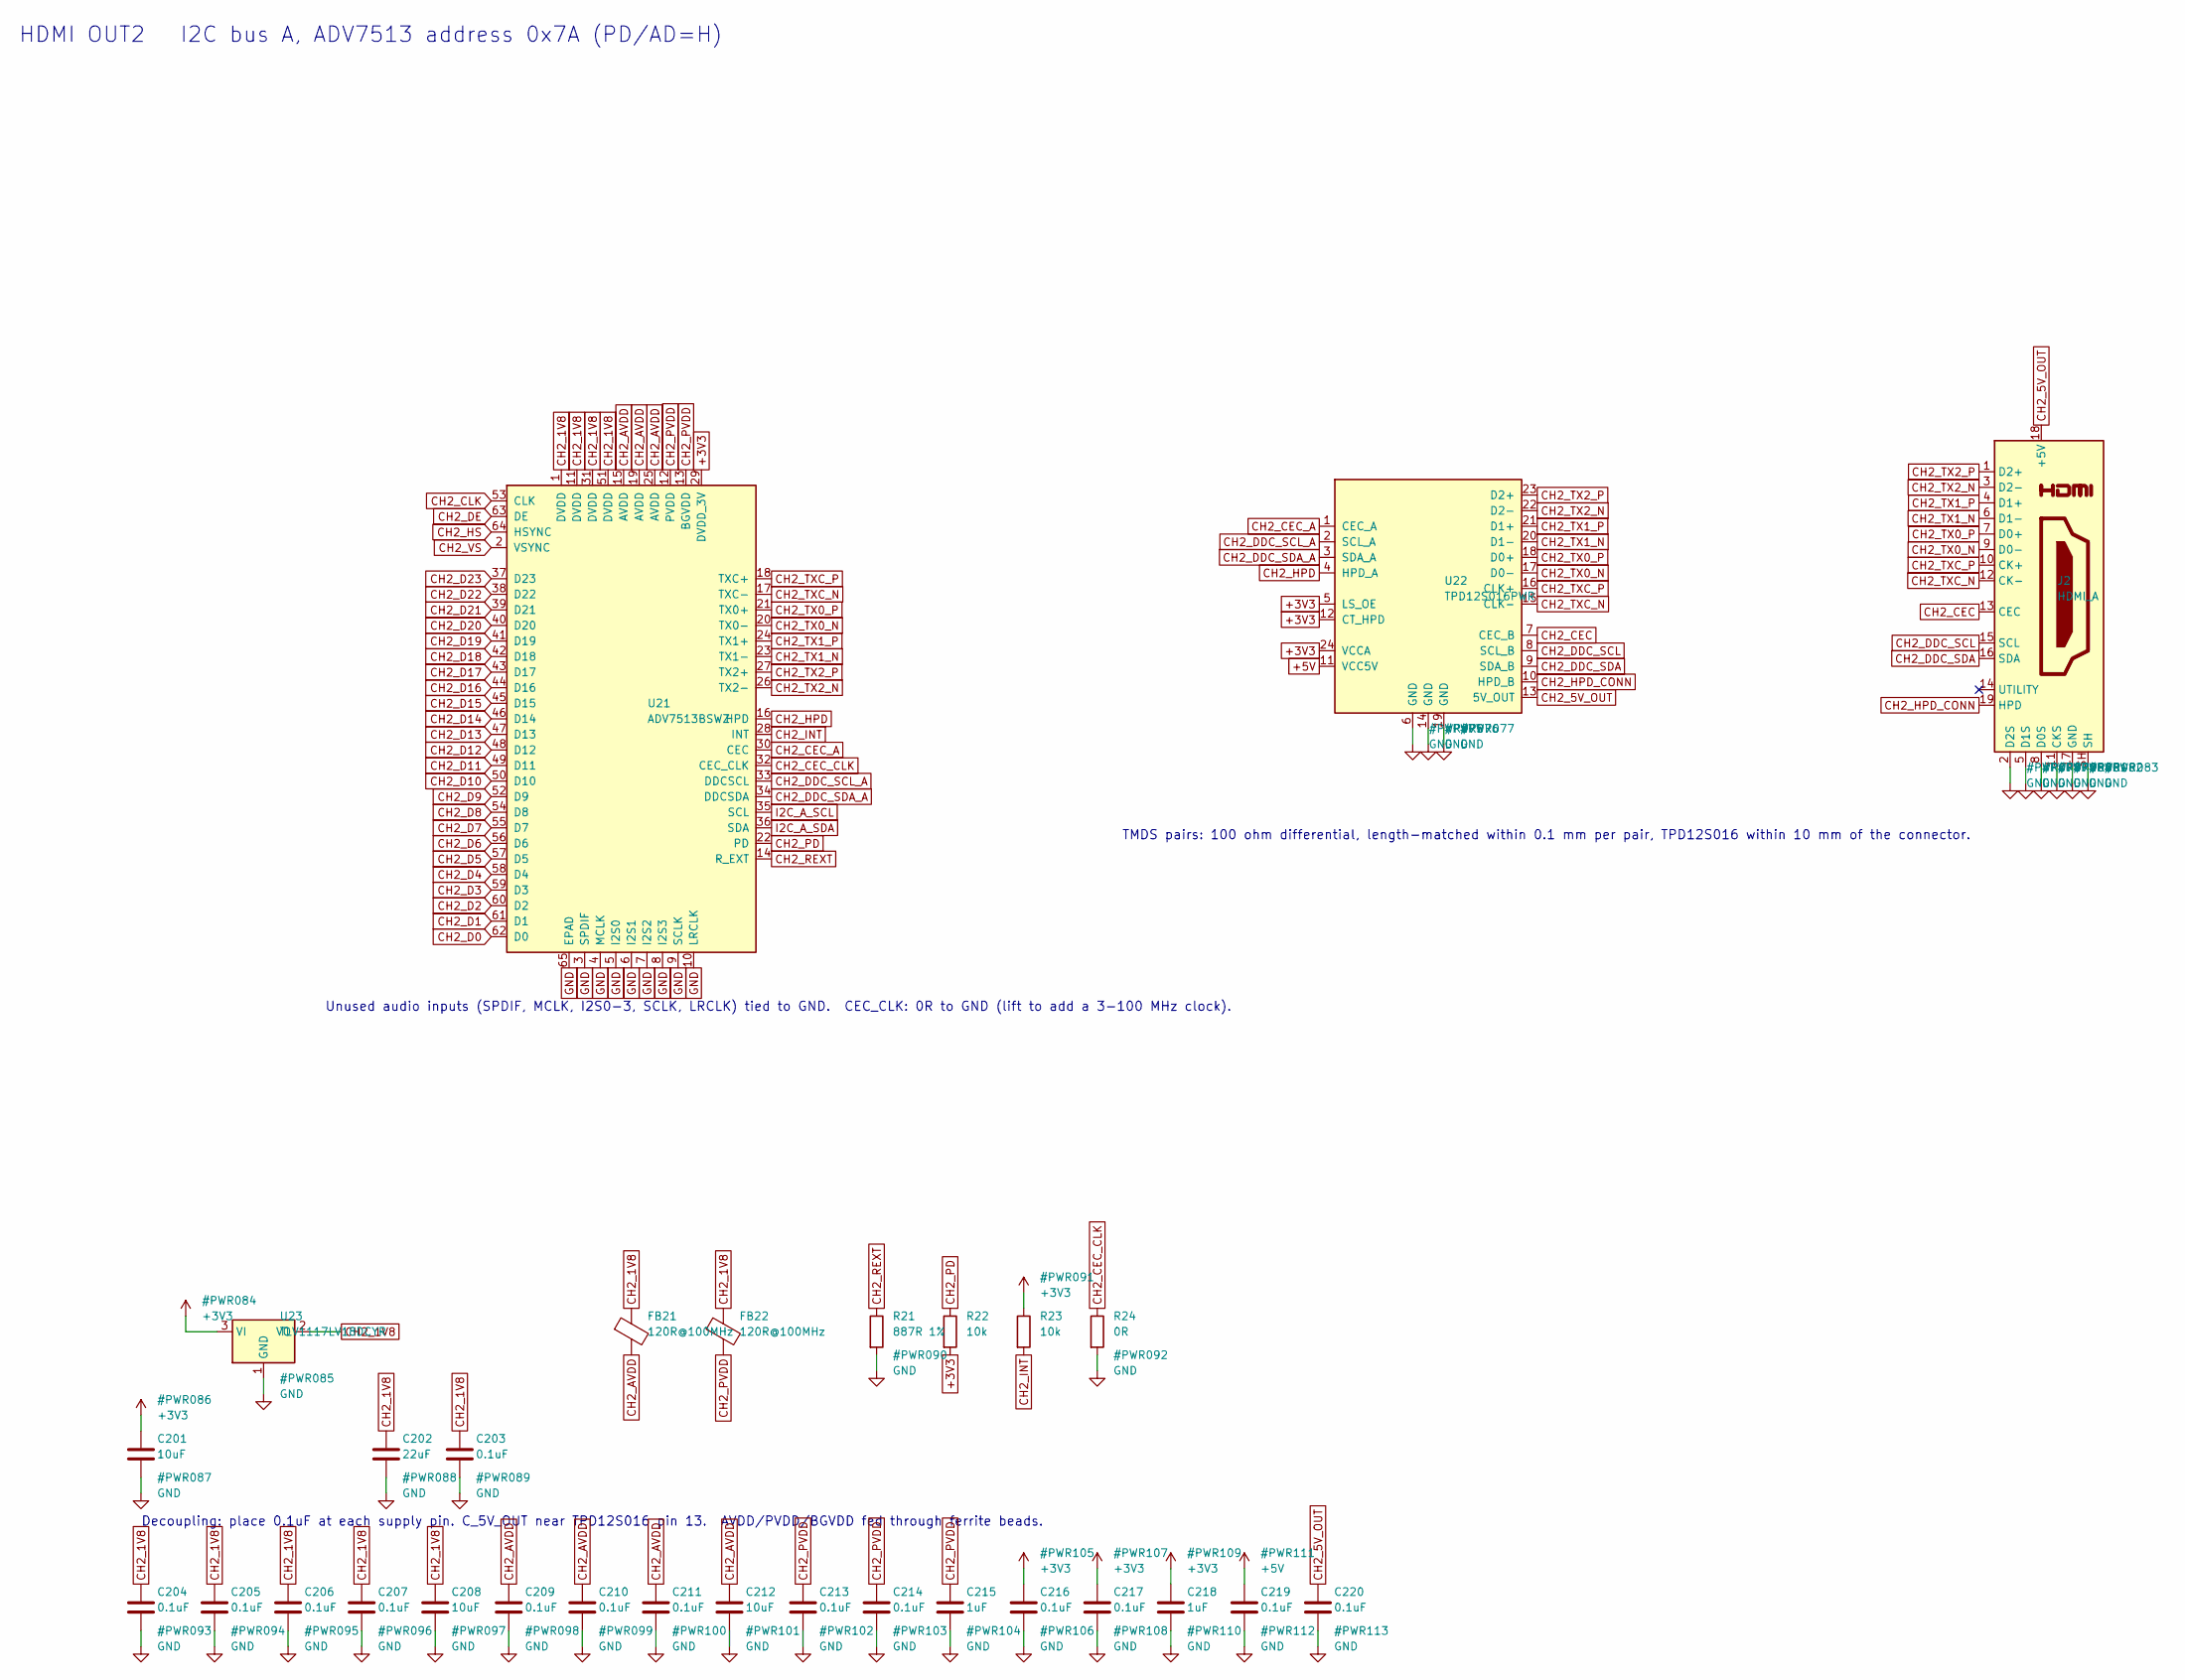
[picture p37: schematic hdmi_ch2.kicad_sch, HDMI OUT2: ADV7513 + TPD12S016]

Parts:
C201, C208, C212: 10uF; C_0603_1608Metric; MPN GRM188R60J106ME47D
C202: 22uF; C_0805_2012Metric; MPN GRM21BR60J226ME39L
C203, C204, C205, C206, C207, C209, C210, C211, C213, C214, C216, C217, C219, C220: 0.1uF; C_0402_1005Metric; MPN GRM155R71C104KA88D
C215, C218: 1uF; C_0603_1608Metric; MPN GRM188R61A105KA61D
FB21, FB22: 120R@100MHz; L_0603_1608Metric; MPN BLM18PG121SN1D
J2: HDMI_A; HDMI_A_Molex_208658-1001_Horizontal; MPN 208658-1001
R21: 887R 1%; R_0402_1005Metric; MPN RC0402FR-07887RL
R22, R23: 10k; R_0402_1005Metric; MPN RC0402FR-0710KL
R24: 0R; R_0402_1005Metric; MPN RC0402FR-070RL
U21: ADV7513BSWZ; LQFP-64-1EP_10x10mm_P0.5mm_EP5x5mm; MPN ADV7513BSWZ
U22: TPD12S016PWR; TSSOP-24_4.4x7.8mm_P0.65mm; MPN TPD12S016PWR
U23: TLV1117LV18DCYR; SOT-223-3_TabPin2; MPN TLV1117LV18DCYR

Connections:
+3V3: C201.1, C216.1, C217.1, C218.1, R22.2, R23.1, U21.29 (DVDD_3V), U22.5 (LS_OE), U22.12 (CT_HPD), U22.24 (VCCA), U23.3 (VI); also elsewhere on the board
+5V: C219.1, U22.11 (VCC5V); also elsewhere on the board
CH2_1V8: C202.1, C203.1, C204.1, C205.1, C206.1, C207.1, C208.1, FB21.1, FB22.1, U21.1 (DVDD), U21.11 (DVDD), U21.31 (DVDD), U21.51 (DVDD), U23.2 (VO)
CH2_5V_OUT: C220.1, J2.18 (+5V), U22.13 (5V_OUT)
CH2_AVDD: C209.1, C210.1, C211.1, C212.1, FB21.2, U21.15 (AVDD), U21.19 (AVDD), U21.25 (AVDD)
CH2_CEC: J2.13 (CEC), U22.7 (CEC_B)
CH2_CEC_A: U21.30 (CEC), U22.1 (CEC_A)
CH2_CEC_CLK: R24.1, U21.32 (CEC_CLK)
CH2_CLK: U21.53 (CLK); also elsewhere on the board
CH2_D0: U21.62 (D0); also elsewhere on the board
CH2_D1: U21.61 (D1); also elsewhere on the board
CH2_D2: U21.60 (D2); also elsewhere on the board
CH2_D3: U21.59 (D3); also elsewhere on the board
CH2_D4: U21.58 (D4); also elsewhere on the board
CH2_D5: U21.57 (D5); also elsewhere on the board
CH2_D6: U21.56 (D6); also elsewhere on the board
CH2_D7: U21.55 (D7); also elsewhere on the board
CH2_D8: U21.54 (D8); also elsewhere on the board
CH2_D9: U21.52 (D9); also elsewhere on the board
CH2_D10: U21.50 (D10); also elsewhere on the board
CH2_D11: U21.49 (D11); also elsewhere on the board
CH2_D12: U21.48 (D12); also elsewhere on the board
CH2_D13: U21.47 (D13); also elsewhere on the board
CH2_D14: U21.46 (D14); also elsewhere on the board
CH2_D15: U21.45 (D15); also elsewhere on the board
CH2_D16: U21.44 (D16); also elsewhere on the board
CH2_D17: U21.43 (D17); also elsewhere on the board
CH2_D18: U21.42 (D18); also elsewhere on the board
CH2_D19: U21.41 (D19); also elsewhere on the board
CH2_D20: U21.40 (D20); also elsewhere on the board
CH2_D21: U21.39 (D21); also elsewhere on the board
CH2_D22: U21.38 (D22); also elsewhere on the board
CH2_D23: U21.37 (D23); also elsewhere on the board
CH2_DDC_SCL: J2.15 (SCL), U22.8 (SCL_B)
CH2_DDC_SCL_A: U21.33 (DDCSCL), U22.2 (SCL_A)
CH2_DDC_SDA: J2.16 (SDA), U22.9 (SDA_B)
CH2_DDC_SDA_A: U21.34 (DDCSDA), U22.3 (SDA_A)
CH2_DE: U21.63 (DE); also elsewhere on the board
CH2_HPD: U21.16 (HPD), U22.4 (HPD_A); also elsewhere on the board
CH2_HPD_CONN: J2.19 (HPD), U22.10 (HPD_B)
CH2_HS: U21.64 (HSYNC); also elsewhere on the board
CH2_INT: R23.2, U21.28 (INT); also elsewhere on the board
CH2_PD: R22.1, U21.22 (PD)
CH2_PVDD: C213.1, C214.1, C215.1, FB22.2, U21.12 (PVDD), U21.13 (BGVDD)
CH2_REXT: R21.1, U21.14 (R_EXT)
CH2_TX0_N: J2.9 (D0-), U21.20 (TX0-), U22.17 (D0-)
CH2_TX0_P: J2.7 (D0+), U21.21 (TX0+), U22.18 (D0+)
CH2_TX1_N: J2.6 (D1-), U21.23 (TX1-), U22.20 (D1-)
CH2_TX1_P: J2.4 (D1+), U21.24 (TX1+), U22.21 (D1+)
CH2_TX2_N: J2.3 (D2-), U21.26 (TX2-), U22.22 (D2-)
CH2_TX2_P: J2.1 (D2+), U21.27 (TX2+), U22.23 (D2+)
CH2_TXC_N: J2.12 (CK-), U21.17 (TXC-), U22.15 (CLK-)
CH2_TXC_P: J2.10 (CK+), U21.18 (TXC+), U22.16 (CLK+)
CH2_VS: U21.2 (VSYNC); also elsewhere on the board
GND: C201.2, C202.2, C203.2, C204.2, C205.2, C206.2, C207.2, C208.2, C209.2, C210.2, C211.2, C212.2, C213.2, C214.2, C215.2, C216.2, C217.2, C218.2, C219.2, C220.2, J2.2 (D2S), J2.5 (D1S), J2.8 (D0S), J2.11 (CKS), J2.17 (GND), J2.SH, R21.2, R24.2, U21.3 (SPDIF), U21.4 (MCLK), U21.5 (I2S0), U21.6 (I2S1), U21.7 (I2S2), U21.8 (I2S3), U21.9 (SCLK), U21.10 (LRCLK), U21.65 (EPAD), U22.6 (GND), U22.14 (GND), U22.19 (GND), U23.1 (GND); also elsewhere on the board
I2C_A_SCL: U21.35 (SCL); also elsewhere on the board
I2C_A_SDA: U21.36 (SDA); also elsewhere on the board

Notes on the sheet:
HDMI OUT2 I2C bus A, ADV7513 address 0x7A (PD/AD=H)
Unused audio inputs (SPDIF, MCLK, I2S0-3, SCLK, LRCLK) tied to GND. CEC_CLK: 0R to GND (lift to add a 3-100 MHz clock).
Decoupling: place 0.1uF at each supply pin. C_5V_OUT near TPD12S016 pin 13. AVDD/PVDD/BGVDD fed through ferrite beads.
TMDS pairs: 100 ohm differential, length-matched within 0.1 mm per pair, TPD12S016 within 10 mm of the connector.

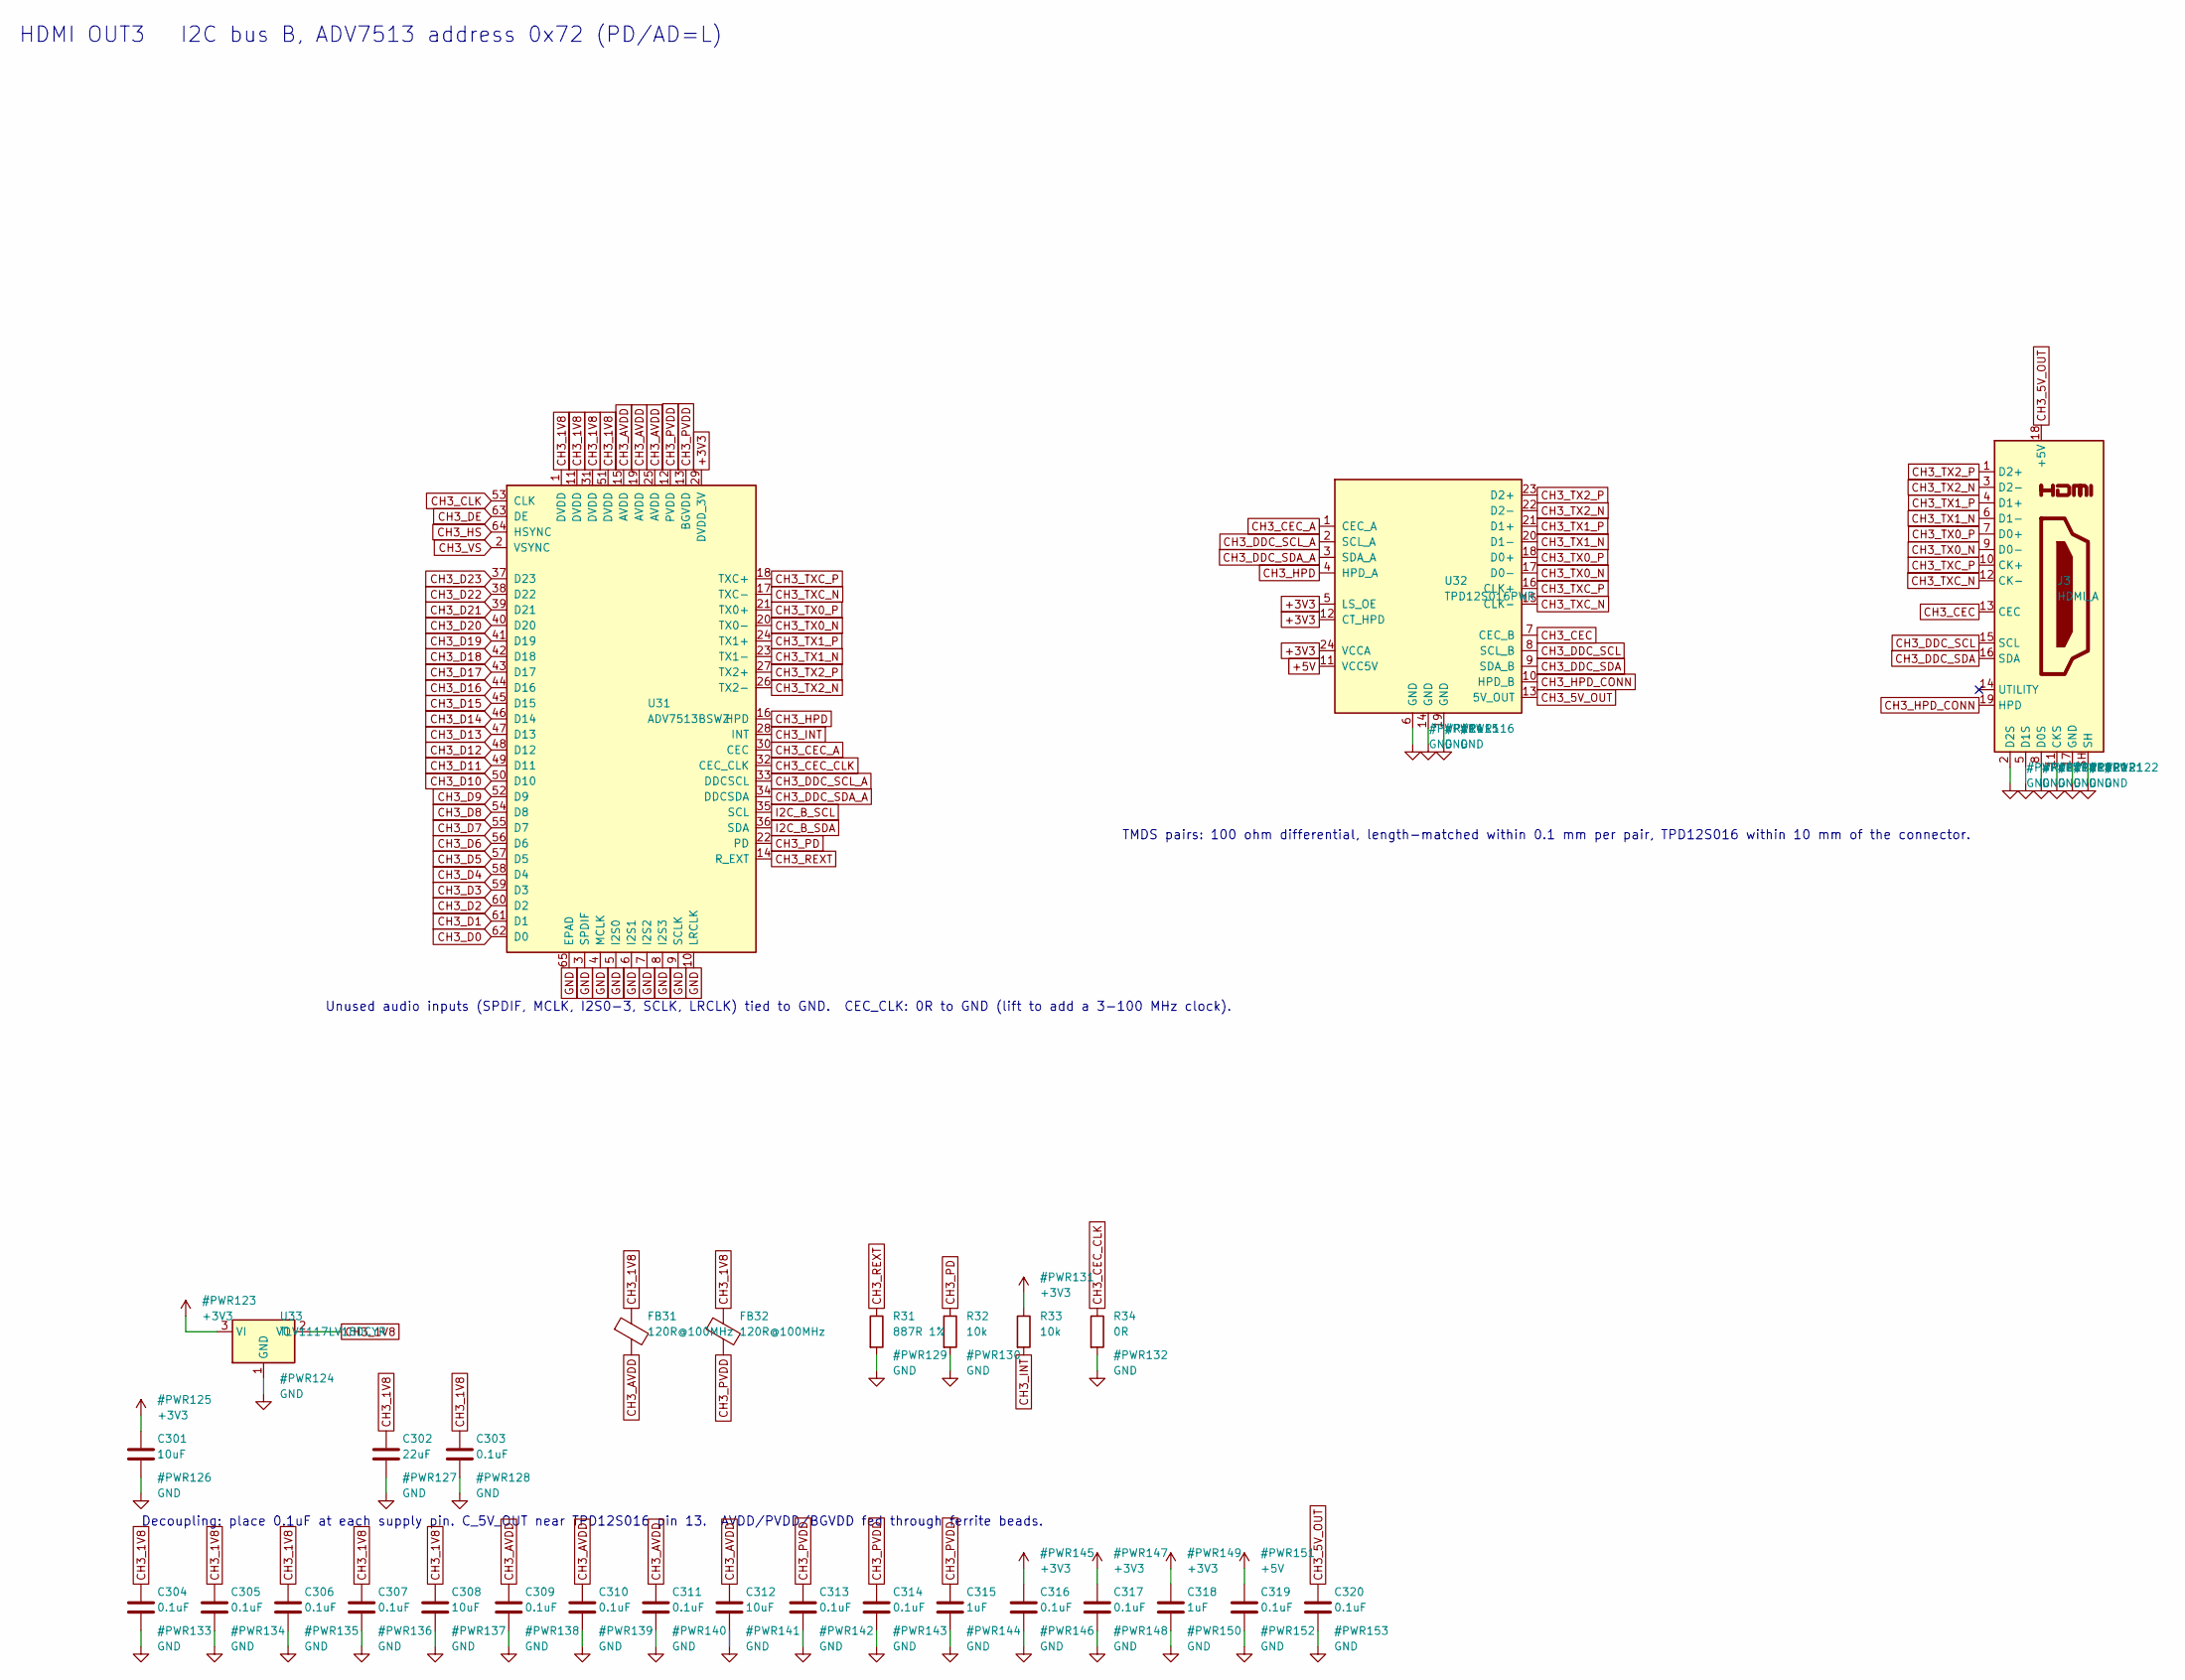
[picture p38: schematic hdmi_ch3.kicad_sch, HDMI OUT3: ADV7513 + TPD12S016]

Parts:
C301, C308, C312: 10uF; C_0603_1608Metric; MPN GRM188R60J106ME47D
C302: 22uF; C_0805_2012Metric; MPN GRM21BR60J226ME39L
C303, C304, C305, C306, C307, C309, C310, C311, C313, C314, C316, C317, C319, C320: 0.1uF; C_0402_1005Metric; MPN GRM155R71C104KA88D
C315, C318: 1uF; C_0603_1608Metric; MPN GRM188R61A105KA61D
FB31, FB32: 120R@100MHz; L_0603_1608Metric; MPN BLM18PG121SN1D
J3: HDMI_A; HDMI_A_Molex_208658-1001_Horizontal; MPN 208658-1001
R31: 887R 1%; R_0402_1005Metric; MPN RC0402FR-07887RL
R32, R33: 10k; R_0402_1005Metric; MPN RC0402FR-0710KL
R34: 0R; R_0402_1005Metric; MPN RC0402FR-070RL
U31: ADV7513BSWZ; LQFP-64-1EP_10x10mm_P0.5mm_EP5x5mm; MPN ADV7513BSWZ
U32: TPD12S016PWR; TSSOP-24_4.4x7.8mm_P0.65mm; MPN TPD12S016PWR
U33: TLV1117LV18DCYR; SOT-223-3_TabPin2; MPN TLV1117LV18DCYR

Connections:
+3V3: C301.1, C316.1, C317.1, C318.1, R33.1, U31.29 (DVDD_3V), U32.5 (LS_OE), U32.12 (CT_HPD), U32.24 (VCCA), U33.3 (VI); also elsewhere on the board
+5V: C319.1, U32.11 (VCC5V); also elsewhere on the board
CH3_1V8: C302.1, C303.1, C304.1, C305.1, C306.1, C307.1, C308.1, FB31.1, FB32.1, U31.1 (DVDD), U31.11 (DVDD), U31.31 (DVDD), U31.51 (DVDD), U33.2 (VO)
CH3_5V_OUT: C320.1, J3.18 (+5V), U32.13 (5V_OUT)
CH3_AVDD: C309.1, C310.1, C311.1, C312.1, FB31.2, U31.15 (AVDD), U31.19 (AVDD), U31.25 (AVDD)
CH3_CEC: J3.13 (CEC), U32.7 (CEC_B)
CH3_CEC_A: U31.30 (CEC), U32.1 (CEC_A)
CH3_CEC_CLK: R34.1, U31.32 (CEC_CLK)
CH3_CLK: U31.53 (CLK); also elsewhere on the board
CH3_D0: U31.62 (D0); also elsewhere on the board
CH3_D1: U31.61 (D1); also elsewhere on the board
CH3_D2: U31.60 (D2); also elsewhere on the board
CH3_D3: U31.59 (D3); also elsewhere on the board
CH3_D4: U31.58 (D4); also elsewhere on the board
CH3_D5: U31.57 (D5); also elsewhere on the board
CH3_D6: U31.56 (D6); also elsewhere on the board
CH3_D7: U31.55 (D7); also elsewhere on the board
CH3_D8: U31.54 (D8); also elsewhere on the board
CH3_D9: U31.52 (D9); also elsewhere on the board
CH3_D10: U31.50 (D10); also elsewhere on the board
CH3_D11: U31.49 (D11); also elsewhere on the board
CH3_D12: U31.48 (D12); also elsewhere on the board
CH3_D13: U31.47 (D13); also elsewhere on the board
CH3_D14: U31.46 (D14); also elsewhere on the board
CH3_D15: U31.45 (D15); also elsewhere on the board
CH3_D16: U31.44 (D16); also elsewhere on the board
CH3_D17: U31.43 (D17); also elsewhere on the board
CH3_D18: U31.42 (D18); also elsewhere on the board
CH3_D19: U31.41 (D19); also elsewhere on the board
CH3_D20: U31.40 (D20); also elsewhere on the board
CH3_D21: U31.39 (D21); also elsewhere on the board
CH3_D22: U31.38 (D22); also elsewhere on the board
CH3_D23: U31.37 (D23); also elsewhere on the board
CH3_DDC_SCL: J3.15 (SCL), U32.8 (SCL_B)
CH3_DDC_SCL_A: U31.33 (DDCSCL), U32.2 (SCL_A)
CH3_DDC_SDA: J3.16 (SDA), U32.9 (SDA_B)
CH3_DDC_SDA_A: U31.34 (DDCSDA), U32.3 (SDA_A)
CH3_DE: U31.63 (DE); also elsewhere on the board
CH3_HPD: U31.16 (HPD), U32.4 (HPD_A); also elsewhere on the board
CH3_HPD_CONN: J3.19 (HPD), U32.10 (HPD_B)
CH3_HS: U31.64 (HSYNC); also elsewhere on the board
CH3_INT: R33.2, U31.28 (INT); also elsewhere on the board
CH3_PD: R32.1, U31.22 (PD)
CH3_PVDD: C313.1, C314.1, C315.1, FB32.2, U31.12 (PVDD), U31.13 (BGVDD)
CH3_REXT: R31.1, U31.14 (R_EXT)
CH3_TX0_N: J3.9 (D0-), U31.20 (TX0-), U32.17 (D0-)
CH3_TX0_P: J3.7 (D0+), U31.21 (TX0+), U32.18 (D0+)
CH3_TX1_N: J3.6 (D1-), U31.23 (TX1-), U32.20 (D1-)
CH3_TX1_P: J3.4 (D1+), U31.24 (TX1+), U32.21 (D1+)
CH3_TX2_N: J3.3 (D2-), U31.26 (TX2-), U32.22 (D2-)
CH3_TX2_P: J3.1 (D2+), U31.27 (TX2+), U32.23 (D2+)
CH3_TXC_N: J3.12 (CK-), U31.17 (TXC-), U32.15 (CLK-)
CH3_TXC_P: J3.10 (CK+), U31.18 (TXC+), U32.16 (CLK+)
CH3_VS: U31.2 (VSYNC); also elsewhere on the board
GND: C301.2, C302.2, C303.2, C304.2, C305.2, C306.2, C307.2, C308.2, C309.2, C310.2, C311.2, C312.2, C313.2, C314.2, C315.2, C316.2, C317.2, C318.2, C319.2, C320.2, J3.2 (D2S), J3.5 (D1S), J3.8 (D0S), J3.11 (CKS), J3.17 (GND), J3.SH, R31.2, R32.2, R34.2, U31.3 (SPDIF), U31.4 (MCLK), U31.5 (I2S0), U31.6 (I2S1), U31.7 (I2S2), U31.8 (I2S3), U31.9 (SCLK), U31.10 (LRCLK), U31.65 (EPAD), U32.6 (GND), U32.14 (GND), U32.19 (GND), U33.1 (GND); also elsewhere on the board
I2C_B_SCL: U31.35 (SCL); also elsewhere on the board
I2C_B_SDA: U31.36 (SDA); also elsewhere on the board

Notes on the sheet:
HDMI OUT3 I2C bus B, ADV7513 address 0x72 (PD/AD=L)
Unused audio inputs (SPDIF, MCLK, I2S0-3, SCLK, LRCLK) tied to GND. CEC_CLK: 0R to GND (lift to add a 3-100 MHz clock).
Decoupling: place 0.1uF at each supply pin. C_5V_OUT near TPD12S016 pin 13. AVDD/PVDD/BGVDD fed through ferrite beads.
TMDS pairs: 100 ohm differential, length-matched within 0.1 mm per pair, TPD12S016 within 10 mm of the connector.

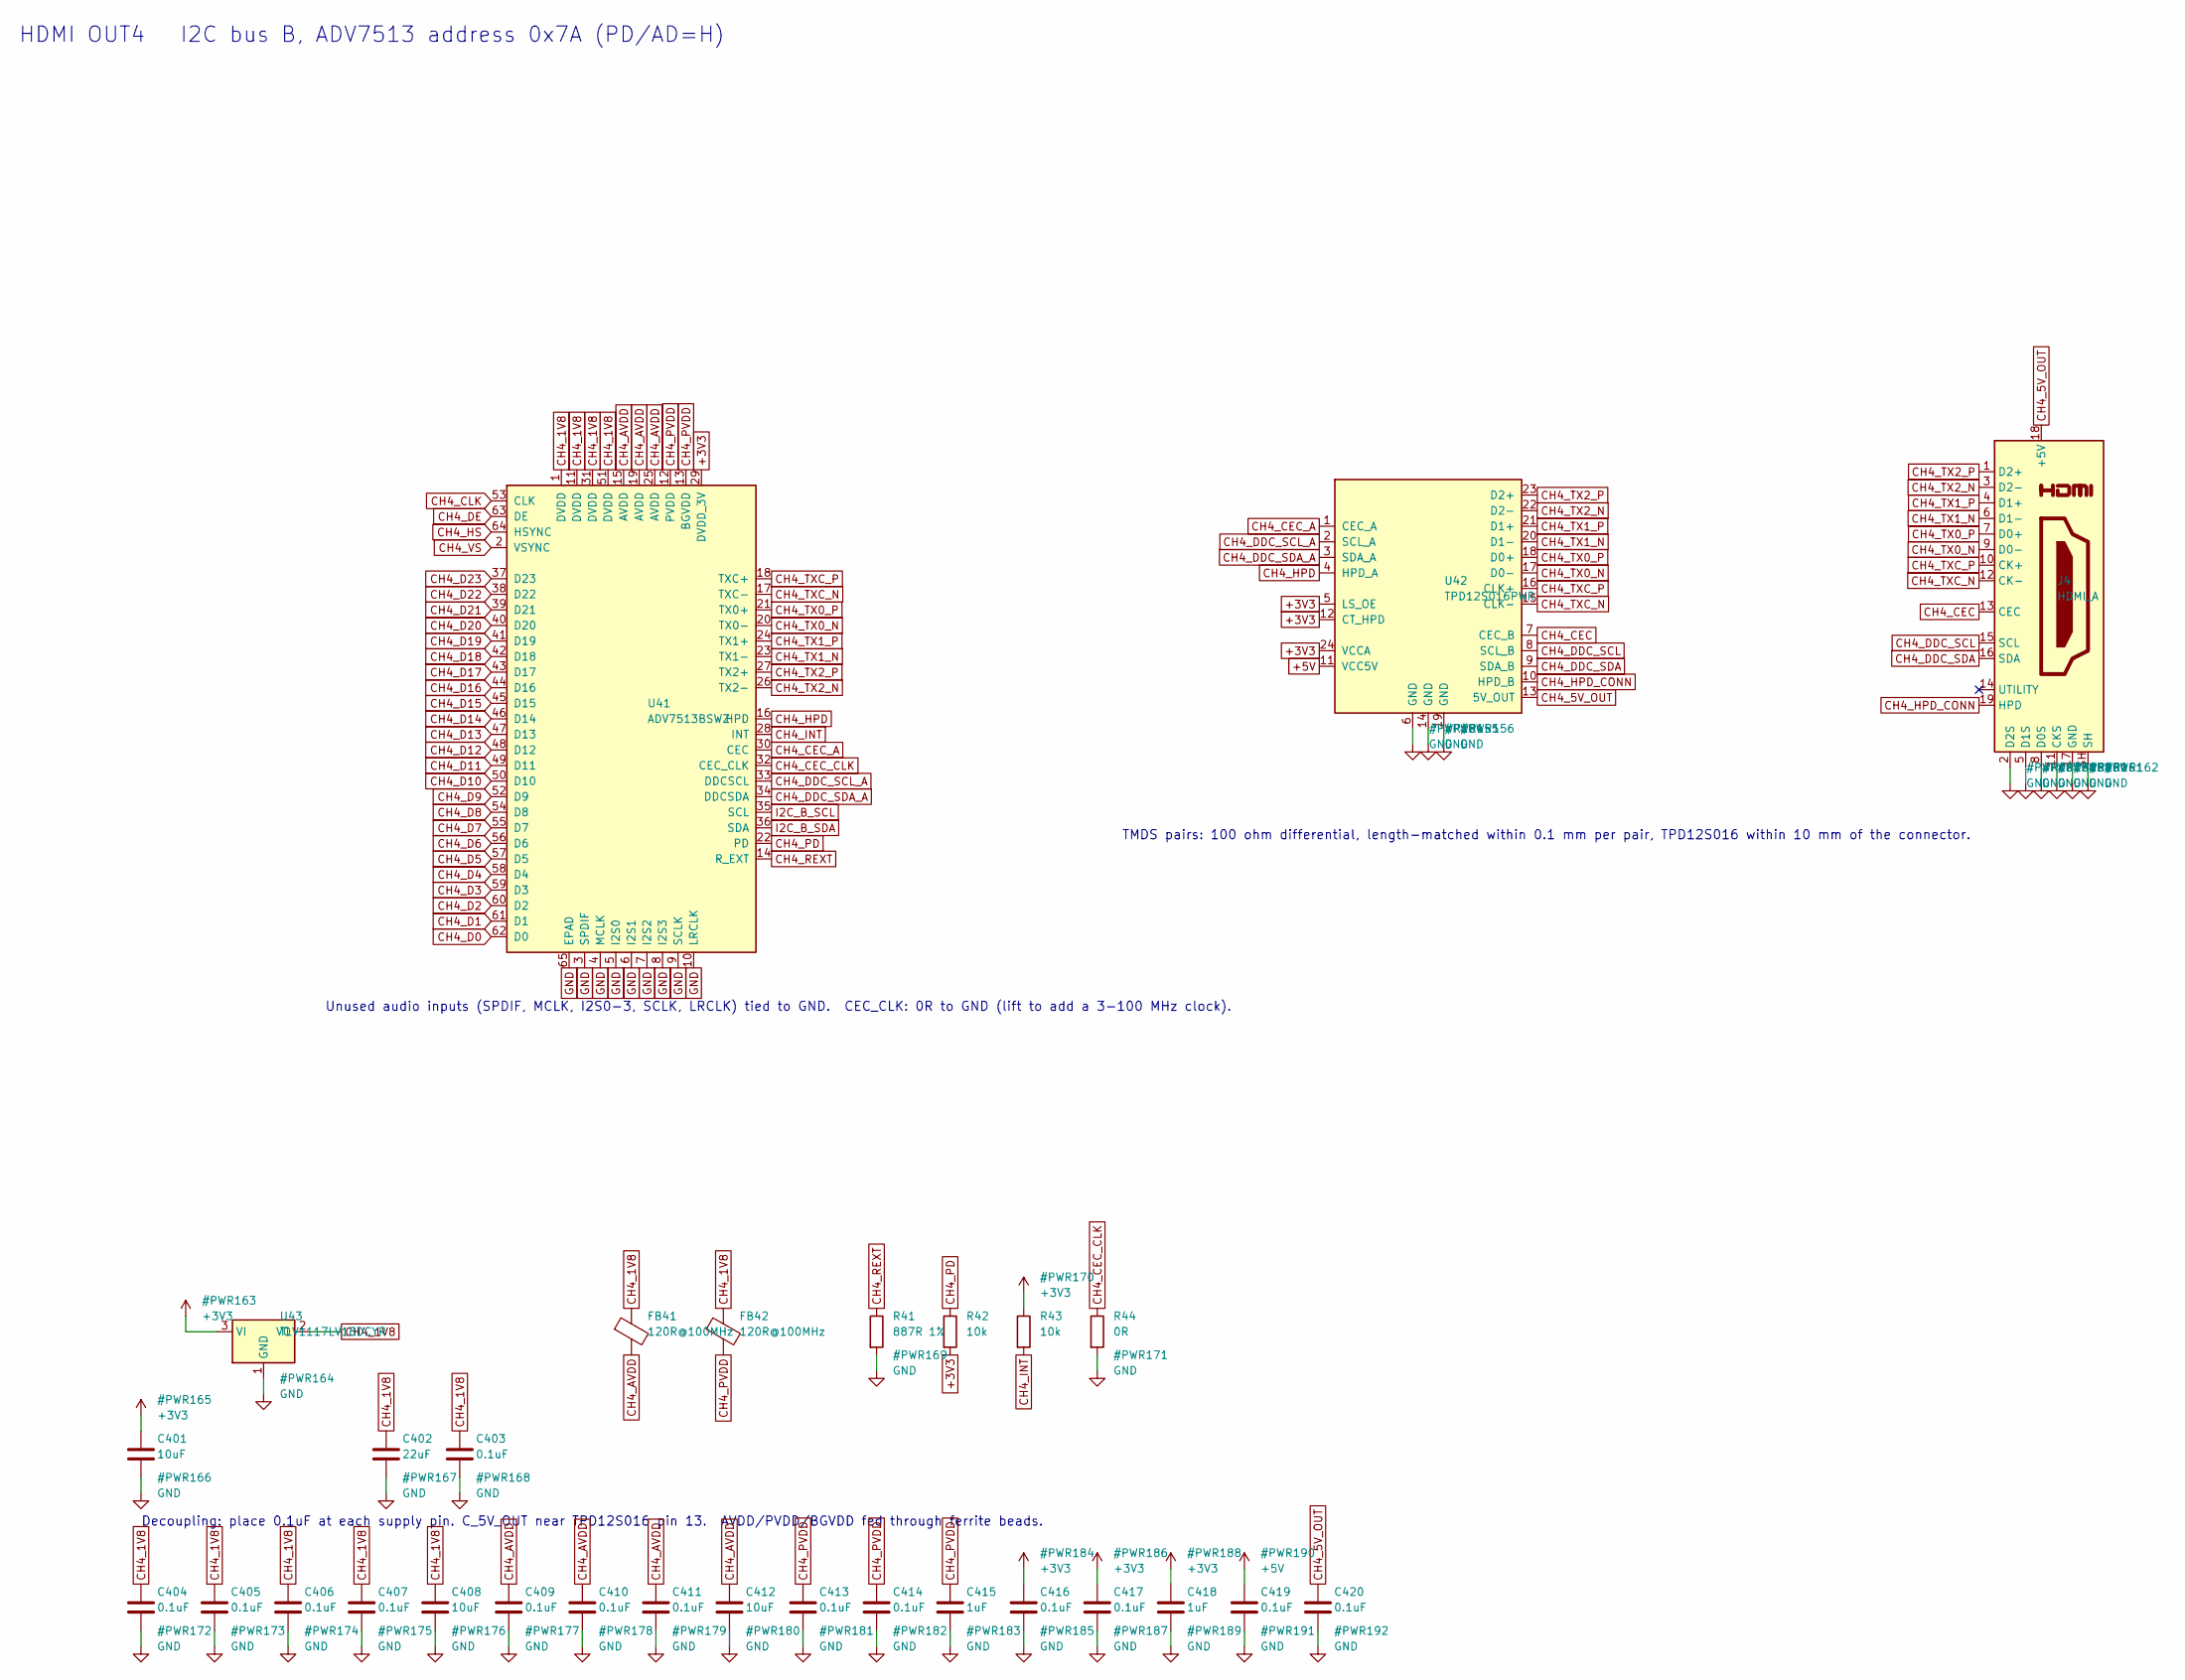
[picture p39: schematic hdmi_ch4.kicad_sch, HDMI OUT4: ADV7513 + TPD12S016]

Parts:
C401, C408, C412: 10uF; C_0603_1608Metric; MPN GRM188R60J106ME47D
C402: 22uF; C_0805_2012Metric; MPN GRM21BR60J226ME39L
C403, C404, C405, C406, C407, C409, C410, C411, C413, C414, C416, C417, C419, C420: 0.1uF; C_0402_1005Metric; MPN GRM155R71C104KA88D
C415, C418: 1uF; C_0603_1608Metric; MPN GRM188R61A105KA61D
FB41, FB42: 120R@100MHz; L_0603_1608Metric; MPN BLM18PG121SN1D
J4: HDMI_A; HDMI_A_Molex_208658-1001_Horizontal; MPN 208658-1001
R41: 887R 1%; R_0402_1005Metric; MPN RC0402FR-07887RL
R42, R43: 10k; R_0402_1005Metric; MPN RC0402FR-0710KL
R44: 0R; R_0402_1005Metric; MPN RC0402FR-070RL
U41: ADV7513BSWZ; LQFP-64-1EP_10x10mm_P0.5mm_EP5x5mm; MPN ADV7513BSWZ
U42: TPD12S016PWR; TSSOP-24_4.4x7.8mm_P0.65mm; MPN TPD12S016PWR
U43: TLV1117LV18DCYR; SOT-223-3_TabPin2; MPN TLV1117LV18DCYR

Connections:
+3V3: C401.1, C416.1, C417.1, C418.1, R42.2, R43.1, U41.29 (DVDD_3V), U42.5 (LS_OE), U42.12 (CT_HPD), U42.24 (VCCA), U43.3 (VI); also elsewhere on the board
+5V: C419.1, U42.11 (VCC5V); also elsewhere on the board
CH4_1V8: C402.1, C403.1, C404.1, C405.1, C406.1, C407.1, C408.1, FB41.1, FB42.1, U41.1 (DVDD), U41.11 (DVDD), U41.31 (DVDD), U41.51 (DVDD), U43.2 (VO)
CH4_5V_OUT: C420.1, J4.18 (+5V), U42.13 (5V_OUT)
CH4_AVDD: C409.1, C410.1, C411.1, C412.1, FB41.2, U41.15 (AVDD), U41.19 (AVDD), U41.25 (AVDD)
CH4_CEC: J4.13 (CEC), U42.7 (CEC_B)
CH4_CEC_A: U41.30 (CEC), U42.1 (CEC_A)
CH4_CEC_CLK: R44.1, U41.32 (CEC_CLK)
CH4_CLK: U41.53 (CLK); also elsewhere on the board
CH4_D0: U41.62 (D0); also elsewhere on the board
CH4_D1: U41.61 (D1); also elsewhere on the board
CH4_D2: U41.60 (D2); also elsewhere on the board
CH4_D3: U41.59 (D3); also elsewhere on the board
CH4_D4: U41.58 (D4); also elsewhere on the board
CH4_D5: U41.57 (D5); also elsewhere on the board
CH4_D6: U41.56 (D6); also elsewhere on the board
CH4_D7: U41.55 (D7); also elsewhere on the board
CH4_D8: U41.54 (D8); also elsewhere on the board
CH4_D9: U41.52 (D9); also elsewhere on the board
CH4_D10: U41.50 (D10); also elsewhere on the board
CH4_D11: U41.49 (D11); also elsewhere on the board
CH4_D12: U41.48 (D12); also elsewhere on the board
CH4_D13: U41.47 (D13); also elsewhere on the board
CH4_D14: U41.46 (D14); also elsewhere on the board
CH4_D15: U41.45 (D15); also elsewhere on the board
CH4_D16: U41.44 (D16); also elsewhere on the board
CH4_D17: U41.43 (D17); also elsewhere on the board
CH4_D18: U41.42 (D18); also elsewhere on the board
CH4_D19: U41.41 (D19); also elsewhere on the board
CH4_D20: U41.40 (D20); also elsewhere on the board
CH4_D21: U41.39 (D21); also elsewhere on the board
CH4_D22: U41.38 (D22); also elsewhere on the board
CH4_D23: U41.37 (D23); also elsewhere on the board
CH4_DDC_SCL: J4.15 (SCL), U42.8 (SCL_B)
CH4_DDC_SCL_A: U41.33 (DDCSCL), U42.2 (SCL_A)
CH4_DDC_SDA: J4.16 (SDA), U42.9 (SDA_B)
CH4_DDC_SDA_A: U41.34 (DDCSDA), U42.3 (SDA_A)
CH4_DE: U41.63 (DE); also elsewhere on the board
CH4_HPD: U41.16 (HPD), U42.4 (HPD_A); also elsewhere on the board
CH4_HPD_CONN: J4.19 (HPD), U42.10 (HPD_B)
CH4_HS: U41.64 (HSYNC); also elsewhere on the board
CH4_INT: R43.2, U41.28 (INT); also elsewhere on the board
CH4_PD: R42.1, U41.22 (PD)
CH4_PVDD: C413.1, C414.1, C415.1, FB42.2, U41.12 (PVDD), U41.13 (BGVDD)
CH4_REXT: R41.1, U41.14 (R_EXT)
CH4_TX0_N: J4.9 (D0-), U41.20 (TX0-), U42.17 (D0-)
CH4_TX0_P: J4.7 (D0+), U41.21 (TX0+), U42.18 (D0+)
CH4_TX1_N: J4.6 (D1-), U41.23 (TX1-), U42.20 (D1-)
CH4_TX1_P: J4.4 (D1+), U41.24 (TX1+), U42.21 (D1+)
CH4_TX2_N: J4.3 (D2-), U41.26 (TX2-), U42.22 (D2-)
CH4_TX2_P: J4.1 (D2+), U41.27 (TX2+), U42.23 (D2+)
CH4_TXC_N: J4.12 (CK-), U41.17 (TXC-), U42.15 (CLK-)
CH4_TXC_P: J4.10 (CK+), U41.18 (TXC+), U42.16 (CLK+)
CH4_VS: U41.2 (VSYNC); also elsewhere on the board
GND: C401.2, C402.2, C403.2, C404.2, C405.2, C406.2, C407.2, C408.2, C409.2, C410.2, C411.2, C412.2, C413.2, C414.2, C415.2, C416.2, C417.2, C418.2, C419.2, C420.2, J4.2 (D2S), J4.5 (D1S), J4.8 (D0S), J4.11 (CKS), J4.17 (GND), J4.SH, R41.2, R44.2, U41.3 (SPDIF), U41.4 (MCLK), U41.5 (I2S0), U41.6 (I2S1), U41.7 (I2S2), U41.8 (I2S3), U41.9 (SCLK), U41.10 (LRCLK), U41.65 (EPAD), U42.6 (GND), U42.14 (GND), U42.19 (GND), U43.1 (GND); also elsewhere on the board
I2C_B_SCL: U41.35 (SCL); also elsewhere on the board
I2C_B_SDA: U41.36 (SDA); also elsewhere on the board

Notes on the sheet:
HDMI OUT4 I2C bus B, ADV7513 address 0x7A (PD/AD=H)
Unused audio inputs (SPDIF, MCLK, I2S0-3, SCLK, LRCLK) tied to GND. CEC_CLK: 0R to GND (lift to add a 3-100 MHz clock).
Decoupling: place 0.1uF at each supply pin. C_5V_OUT near TPD12S016 pin 13. AVDD/PVDD/BGVDD fed through ferrite beads.
TMDS pairs: 100 ohm differential, length-matched within 0.1 mm per pair, TPD12S016 within 10 mm of the connector.

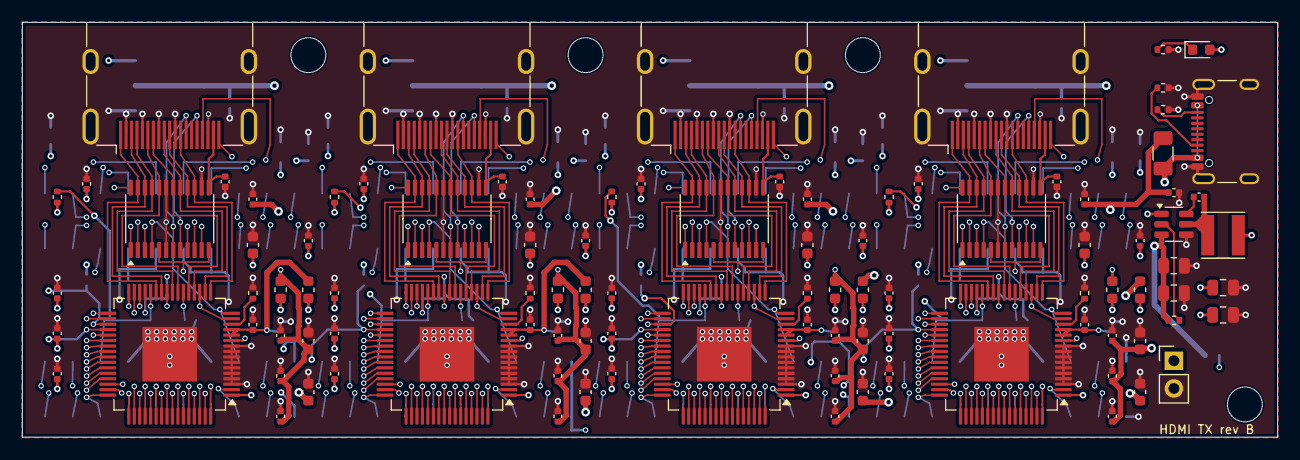
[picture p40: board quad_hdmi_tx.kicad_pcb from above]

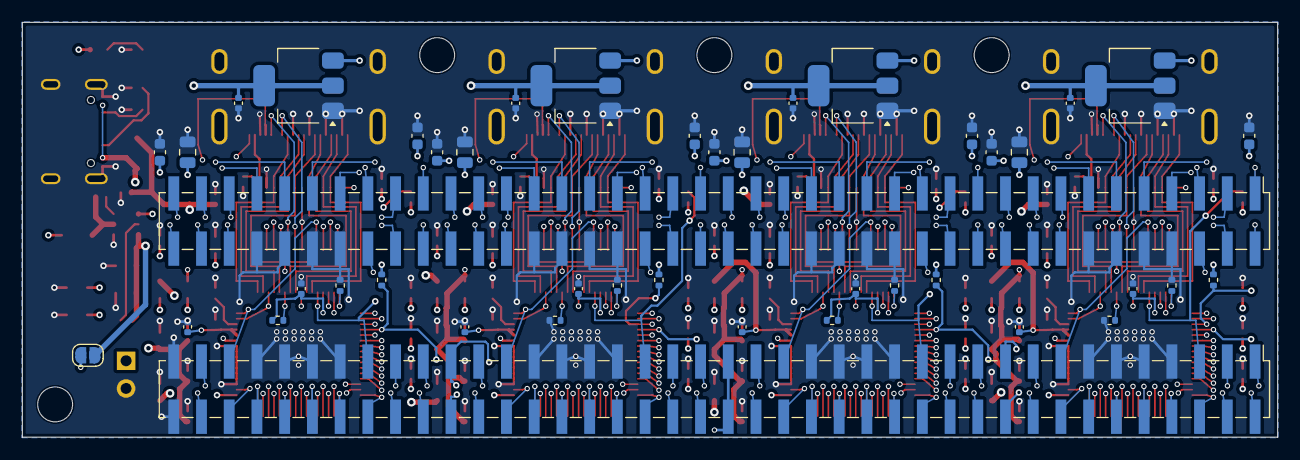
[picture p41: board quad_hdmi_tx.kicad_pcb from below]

Board: 6 copper layers, 115.0 x 38.0 mm, 147 parts (43 on the bottom side), 223 nets.

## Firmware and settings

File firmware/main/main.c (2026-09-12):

#include "lt86104.h"
#include "esp_log.h"
#include "freertos/FreeRTOS.h"
#include "freertos/task.h"

static const char *TAG = "app";

void app_main(void)
{
    ESP_ERROR_CHECK(lt86104_bus_init());
    lt86104_hw_reset();

    uint8_t found[8];
    int n = lt86104_scan(found, 8);
    ESP_LOGI(TAG, "%d I2C device(s) found", n);

    for (int i = 0; i < n; i++) {
        esp_err_t r = lt86104_init(found[i]);
        ESP_LOGI(TAG, "init 0x%02X -> %s", found[i], esp_err_to_name(r));
    }

    while (1) {
        // TODO: INT ピン監視、状態の Wi-Fi 公開
        vTaskDelay(pdMS_TO_TICKS(1000));
    }
}

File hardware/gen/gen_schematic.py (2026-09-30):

#!/usr/bin/env python3
"""4 出力 HDMI 送信基板 (ADV7513 x4 + TPD12S016 x4) の KiCad 7 回路図を生成する。

出力: hardware/quad_hdmi_tx/*.kicad_sch, *.kicad_pro, bom.csv, fpga_header_pinmap.csv
"""
import os, uuid, csv, sys
from sexp import Sym, dump, find, find1
from kicad_lib import get_symbol, pins as lib_pins, footprint as lib_fp

PROJECT = "quad_hdmi_tx"
OUT = os.path.join(os.path.dirname(__file__), "..", PROJECT)
ROOT_UUID = "9c8f0a10-0000-4000-8000-000000000001"

def U():
    return str(uuid.uuid4())

# ---------------------------------------------------------------- 部品表
BOM = {}   # ref -> dict
def bom_add(ref, value, footprint, mpn, desc, lib_id):
    BOM[ref] = dict(ref=ref, value=value, footprint=footprint, mpn=mpn, desc=desc, lib_id=lib_id)

# ---------------------------------------------------------------- カスタムシンボル
def make_symbol(name, ref_prefix, value, fp, left, right, top, bottom, half_w, half_h, datasheet="~"):
    """left/right/top/bottom: [(number, name, type)] または None (空き)。ピン間隔 2.54。"""
    def pin(num, nm, typ, x, y, ang):
        return [Sym("pin"), Sym(typ), Sym("line"), [Sym("at"), x, y, ang], [Sym("length"), 2.54],
                [Sym("name"), nm, [Sym("effects"), [Sym("font"), [Sym("size"), 1.27, 1.27]]]],
                [Sym("number"), num, [Sym("effects"), [Sym("font"), [Sym("size"), 1.27, 1.27]]]]]
    unit_pins = [Sym("symbol"), f"{name}_1_1"]
    def col(items, x, ang):
        n = len(items); y0 = (n - 1) / 2 * 2.54
        for i, it in enumerate(items):
            if it: unit_pins.append(pin(it[0], it[1], it[2], x, round(y0 - i * 2.54, 2), ang))
    def row(items, y, ang):
        n = len(items); x0 = -(n - 1) / 2 * 2.54
        for i, it in enumerate(items):
            if it: unit_pins.append(pin(it[0], it[1], it[2], round(x0 + i * 2.54, 2), y, ang))
    col(left, -(half_w + 2.54), 0); col(right, half_w + 2.54, 180)
    row(top, half_h + 2.54, 270); row(bottom, -(half_h + 2.54), 90)
    body = [Sym("symbol"), f"{name}_0_1",
            [Sym("rectangle"), [Sym("start"), -half_w, half_h], [Sym("end"), half_w, -half_h],
             [Sym("stroke"), [Sym("width"), 0.254], [Sym("type"), Sym("default")]],
             [Sym("fill"), [Sym("type"), Sym("background")]]]]
    def prop(k, v, hide=False):
        e = [Sym("effects"), [Sym("font"), [Sym("size"), 1.27, 1.27]]]
        if hide: e.append(Sym("hide"))
        return [Sym("property"), k, v, [Sym("at"), 0, 0, 0], e]
    return [Sym("symbol"), name, [Sym("pin_names"), [Sym("offset"), 1.016]], [Sym("in_bom"), Sym("yes")], [Sym("on_board"), Sym("yes")],
            prop("Reference", ref_prefix), prop("Value", value), prop("Footprint", fp, True), prop("Datasheet", datasheet, True),
            body, unit_pins]

# D0=62 ... D8=54, D9=52, D10=50 ... D23=37
def adv_dpin(i):
    return 62 - i if i <= 8 else (52 if i == 9 else 50 - (i - 10))
ADV_LEFT = [("53", "CLK", "input"), ("63", "DE", "input"), ("64", "HSYNC", "input"), ("2", "VSYNC", "input"), None] + \
           [(str(adv_dpin(i)), f"D{i}", "input") for i in range(23, -1, -1)]
ADV_RIGHT = [("18", "TXC+", "output"), ("17", "TXC-", "output"), ("21", "TX0+", "output"), ("20", "TX0-", "output"),
             ("24", "TX1+", "output"), ("23", "TX1-", "output"), ("27", "TX2+", "output"), ("26", "TX2-", "output"), None,
             ("16", "HPD", "input"), ("28", "INT", "output"), ("30", "CEC", "bidirectional"), ("32", "CEC_CLK", "input"),
             ("33", "DDCSCL", "open_collector"), ("34", "DDCSDA", "bidirectional"), ("35", "SCL", "input"), ("36", "SDA", "bidirectional"),
             ("22", "PD", "input"), ("14", "R_EXT", "passive")]
ADV_TOP = [("1", "DVDD", "power_in"), ("11", "DVDD", "power_in"), ("31", "DVDD", "power_in"), ("51", "DVDD", "power_in"),
           ("15", "AVDD", "power_in"), ("19", "AVDD", "power_in"), ("25", "AVDD", "power_in"),
           ("12", "PVDD", "power_in"), ("13", "BGVDD", "power_in"), ("29", "DVDD_3V", "power_in")]
ADV_BOTTOM = [("65", "EPAD", "power_in"), ("3", "SPDIF", "input"), ("4", "MCLK", "input"), ("5", "I2S0", "input"),
              ("6", "I2S1", "input"), ("7", "I2S2", "input"), ("8", "I2S3", "input"), ("9", "SCLK", "input"), ("10", "LRCLK", "input")]
ADV_FP = "Package_QFP:LQFP-64-1EP_10x10mm_P0.5mm_EP5x5mm"   # EP のサーマルビアは gen_pcb.py が裏面ヘッダのパッドを避けて打つ
ADV_SYM = make_symbol("ADV7513", "U", "ADV7513BSWZ", ADV_FP, ADV_LEFT, ADV_RIGHT, ADV_TOP, ADV_BOTTOM, 20.32, 38.1,
                      "https://www.analog.com/media/en/technical-documentation/data-sheets/ADV7513.pdf")

TPD_LEFT = [("1", "CEC_A", "bidirectional"), ("2", "SCL_A", "bidirectional"), ("3", "SDA_A", "bidirectional"), ("4", "HPD_A", "output"), None,
            ("5", "LS_OE", "input"), ("12", "CT_HPD", "input"), None, ("24", "VCCA", "power_in"), ("11", "VCC5V", "power_in")]
TPD_RIGHT = [("23", "D2+", "passive"), ("22", "D2-", "passive"), ("21", "D1+", "passive"), ("20", "D1-", "passive"),
             ("18", "D0+", "passive"), ("17", "D0-", "passive"), ("16", "CLK+", "passive"), ("15", "CLK-", "passive"), None,
             ("7", "CEC_B", "bidirectional"), ("8", "SCL_B", "bidirectional"), ("9", "SDA_B", "bidirectional"), ("10", "HPD_B", "input"),
             ("13", "5V_OUT", "power_out")]
TPD_BOTTOM = [("6", "GND", "power_in"), ("14", "GND", "power_in"), ("19", "GND", "power_in")]
TPD_FP = "Package_SO:TSSOP-24_4.4x7.8mm_P0.65mm"
TPD_SYM = make_symbol("TPD12S016PW", "U", "TPD12S016PWR", TPD_FP, TPD_LEFT, TPD_RIGHT, [], TPD_BOTTOM, 15.24, 19.05,
                      "https://www.ti.com/lit/ds/symlink/tpd12s016.pdf")

CUSTOM = {"QuadHDMI:ADV7513": ADV_SYM, "QuadHDMI:TPD12S016PW": TPD_SYM}
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

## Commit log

2026-09-12 ESP32 + LT86104SX 構成の実現可否検討と設計情報を追加
2026-09-12 映像ソース(生成・再生)に必要な構成とスクリプトを追加
2026-09-13 方針を自己完結型(デバイス内で生成し HDMI 4 本出力)に変更、RK3588 を推奨
    Claude-Session: https://claude.ai/code/session_01JGo25NCpKCcdkj7JC5mDdQ
2026-09-13 FPGA 4 出力テストパターン発生器に方針変更: HDL 一式、シミュレーション、設計文書を追加
    - Artix-7 + ADV7513 x4 で 1080p/720p/480p x 29.97/59.94/30/60p を出力ごとに独立生成
    - MMCM 設定を総当たりで求め、6 種のピクセルクロックを 1 ppm 以内で生成
    - カラーバー、動くボックス、グレースケール、ラベル、フレームカウンタ、タイムコードを重畳
    - iverilog テストベンチで 1 フレームを PPM 出力 (480p/1080p の結果画像を docs/images に格納)
    - ADV7513 の I2C 初期化シーケンサ、制約ファイル例、フォント ROM 生成スクリプト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
2026-09-14 キャリア基板の回路図 (KiCad 7) を追加: ADV7513 x4 + TPD12S016 x4 + HDMI x4 + 電源
    - hardware/gen/gen_schematic.py で回路図・BOM・J7/J8 ピン割り当てを生成
    - ADV7513 (LQFP-64 EP) と TPD12S016 (TSSOP-24) のピン配置はデータシートから転記
    - kicad-cli でネットリスト/PDF を書き出し、check_netlist.py で全ピン接続とネットごとのピン数を検証
    - USB-C 5 V 入力、AP63203 3.3 V バック、チャネルごとの 1.8 V LDO
    - hardware/README.md に構成、検証状況、発注前チェックリスト、レイアウト指針
    Claude-Session: https://claude.ai/code/session_0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
    [bom.csv, bom_grouped.csv, fpga_conn.kicad_sch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]
2026-09-14 基板レイアウトの生成パイプラインを追加: 配置・外形・プレーン生成、自動配線、DRC、製造データ出力
    - gen_pcb.py: ネットリストから 4 層基板 (115x110 mm) を生成。HDMI 上辺、TPD/ADV の向きを TMDS が交差しないよう配置
    - route_pcb.py: DSN 書き出し / SES 取り込み、外層 GND ベタ、ゾーン塗り、DRC
    - layout_report.py: 配線長、ビア数、TMDS ペア長差、DRC 集計
    - export_fab.sh: ガーバー、ドリル、CPL、各層 PDF
    - J7 = OUT1/OUT3、J8 = OUT2/OUT4 にヘッダ割り当てを変更 (回路図・ネットリスト再生成)
    - README にレイアウト節 (配置図、層構成、ルール、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
    [fpga_conn.kicad_sch, fpga_header_pinmap.csv, hdmi_ch1.kicad_sch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]
2026-09-14 FreeRouting のログディレクトリを無視
    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
2026-09-14 レイアウト: プレーン系ネットのファンアウトビア生成、SES 取り込みの修正、チャネルピッチ 24 mm に変更
    - FreeRouting は内層プレーンへのビアを作らないため、GND/+3V3/1V8 の全 SMD パッドに衝突チェック付きでビアを先置き
    - 自前の SES パーサ (ses_import.py) を用意し、pcbnew API の取り込みが失敗した場合に使用
    - FreeRouting の設定ファイル/GUI 要件などの注意点を README に記載
    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
    [quad_hdmi_tx.kicad_pcb]
2026-09-14 レイアウト: TMDS ペアを事前配線、ファンアウトの衝突チェック強化、配置とルールの修正
    - TMDS 8 本/ch を ADV → TPD 下の U ターン → TPD パッド → コネクタ へ交差なしで固定配線
    - ファンアウトビアは既存配線とも衝突チェック、内向き候補を追加、置けない GND ピンは隣接ピンへ短絡
    - 1V8 の島を LDO 入力側と TPD 3.3V ビアを避ける多角形に変更、DVDD_3V ピン用スロット
    - 最小ドリル 0.2 mm (ADV の EP サーマルビア)、コンデンサ列の間隔調整、シルクの参照記号を Fab 層へ
    - 事前配線状態の DRC: クリアランス/コートヤード違反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
    [quad_hdmi_tx.kicad_pcb]
2026-09-14 レイアウト: 囲われたパッドへのアクセスビア、連続 GND ピンの数珠つなぎ、5V_OUT 事前配線、事前配線 DRC クリーン
    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
    [bom.csv, bom_grouped.csv, fpga_conn.kicad_sch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]
2026-09-14 レイアウト: 左列を ADV 左上へ移動、1V8 の島を縮小、TPD 制御ピンと DVDD_3V の +3V3 事前配線、ビア掃除の修正
    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
    [quad_hdmi_tx.kicad_pcb]
2026-09-14 基板レイアウト完了: DRC 未接続 0 / クリアランス違反 0、ガーバー・ドリル・CPL を出力
    - FreeRouting 1.9 (16 パス) の結果を取り込み、ADV pin15 (AVDD) の残り 2 本をスクリプトで接続
    - 外層 GND ベタ、未使用アクセスビアの削除、DRC レポート
    - fab/: ガーバー (4 層 + マスク/ペースト/シルク/外形)、Excellon ドリル、CPL、各層 PDF
    - README にレイアウト結果 (層画像、ネット長、TMDS ペア長差) と発注前チェックリストを追記
    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
    [quad_hdmi_tx.kicad_pcb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]
2026-09-15 レイアウト修正: HDMI/USB-C を基板端に合わせて再配線、DRC 未接続 0 / クリアランス違反 0
    - gen_pcb.py: フットプリントの "PCB Edge" 線が外形に一致するよう J1-J4 (y=7.02) と J5 (x=111.33) を移動
    - gen_pcb.py: ADV DVDD_3V (pin29) を B.Cu 経由で島の外へ (右上コーナー経由が HPD pin16 を塞いでいた)
    - route_pcb.py: 未接続の島を最寄り端点間で L 字/直線/ビア経由で接続する DRC ゲート付きフィクサ、片層ビアの削除
    - render_images.py: fab/*.pdf から docs/images/pcb-*.png を生成
    - ガーバー・ドリル・CPL・PDF を再出力、README の検証状況とチェックリスト (コネ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
    [quad_hdmi_tx.kicad_pcb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]
2026-09-30 レイアウト rev B: 115 × 38 mm の細長い 6 層基板に再配置、ヘッダ配線を全数固定して DRC 未接続 0 / クリアランス違反 0
    - 基板を HDMI 4 個分の横幅 (115 mm) × 縦 38 mm (横の 1/3) に変更、6 層 (F / GND / SIG1 / SIG2 / PWR / B)
    - FPGA ヘッダ 2×40 を裏面に 2 本、長辺と平行に配置。ヘッダの列が各 ADV7513 の真下に来る
    - J7/J8 のピン割り当てを配線経路に合わせて変更 (J7 = ADV 左辺の D13-23 + D1/D2/D4/D5/D10、J8 = 下辺の残り + CLK/DE/HS/VS/HPD/INT)
    - RGB バス 30 本 × 4 ch、DDC/CEC/HPD、AVDD/PVDD の一部、FPGA_5V を gen_pcb.py で内層に固定配線 (交差しないレーン割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
    [bom.csv, bom_grouped.csv, fpga_conn.kicad_sch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]
2026-10-04 3D モデル: STEP (基板のみ)、簡易 OBJ モデル (テクスチャ + 部品の直方体)、three.js ビューアを追加
    - gen/gen_3d.py: pcbnew から基板外形・穴・ビア・部品の外形 (パッケージ寸法表) を 3d/board3d.json と Wavefront OBJ/MTL に書き出す
    - gen/make_3d_textures.py: 各層の白黒プロットから表裏のテクスチャ (レジスト緑・金パッド・白シルク・穴) を合成し、viewer_template.html に埋め込んで 3d/viewer.html を作る
    - kicad-cli の STEP 出力 (3D ライブラリが無いので部品なし) を 3d/quad_hdmi_tx.step に追加
    - docs/images に 3D 表示 (斜め・表・裏) を追加、README に 3D モ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
    [quad_hdmi_tx.step, quad_hdmi_tx_simplified.obj]
2026-10-31 FPGA メイン基板 (XC7A35T-FTG256) を追加: キャリア基板を重ねる 2 枚構成
    - hardware/fpga_main: 回路図 6 ページ (USB-C 5 V -> 1.0/1.8/3.3 V バック、FPGA I/O・コンフィグ・電源ピン、QSPI フラッシュ、
    JTAG 2x7/1x6、100 MHz、キャリア用 2x40 ソケット J1/J2、LED/DIP/リセット/PMOD)、BOM、全 256 ボールのピン表
    - 115 x 72 mm 6 層レイアウト: BGA は dog-bone ビア + 整数格子線のエスケープ (リング 1-2 表面、3-4 In2、5+ In3) を
    スクリプトで固定配線し、124 本のヘッダ信号を BGA の周回順に割り当て、残りを FreeRouting で配線。
    DRC 未接続 0 / クリアランス違反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
